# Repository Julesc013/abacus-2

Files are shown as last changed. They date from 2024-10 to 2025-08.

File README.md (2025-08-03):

# Project Codename: Abacus 2

**Carbon A1 Minicomputer** and **Carbon Z1 Microcomputer**

[Project Abacus 2 Technical Reference](https://github.com/Julesc013/abacus-2/blob/main/info/manual/Abacus%202%20Technical%20Reference.pdf) (PDF)

## Specifications

- _CPU:_ **Abacus 2** or **Zilog Z80** (8-bit CISC)
- _FPU:_ **AMD Am9511** (Pre-IEEE 754)
- _Clock:_ Up to **16 MHz** (Crystal FM)
- _RAM:_ Up to **640 KB** (SRAM)
- _ROM:_ Up to **128 KB** (PROM)
- _I/O:_ Up to **256 KB** (Memory Mapped)
- _TDD:_ **Compact Cassette** (KCS 240KB/hr)
- _FDD:_ **Floppy Disk** (5.25" DSDD 360KB, 3.5" DSHD 1.44MB)
- _Comms:_ **Serial** (RS-232), **Parallel** (DB-25)
- _Video:_ **Yamaha V9958** or **TMS9918**
- _Audio:_ **Yamaha OPNB** or **AY-3-8910**

## Design Showcase

### System Architecture

16-bit CISC (Von Neumann)

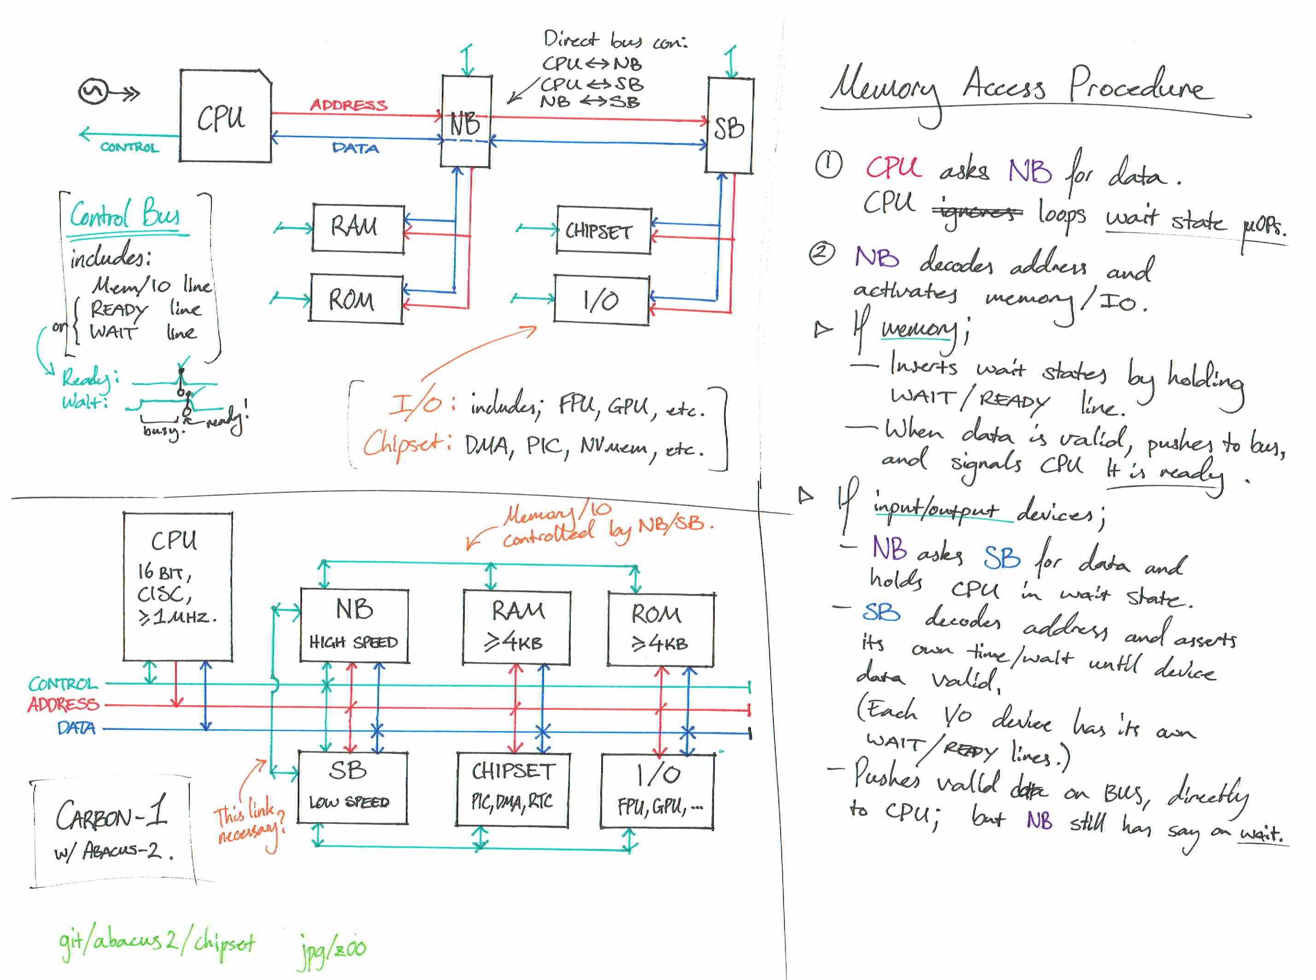
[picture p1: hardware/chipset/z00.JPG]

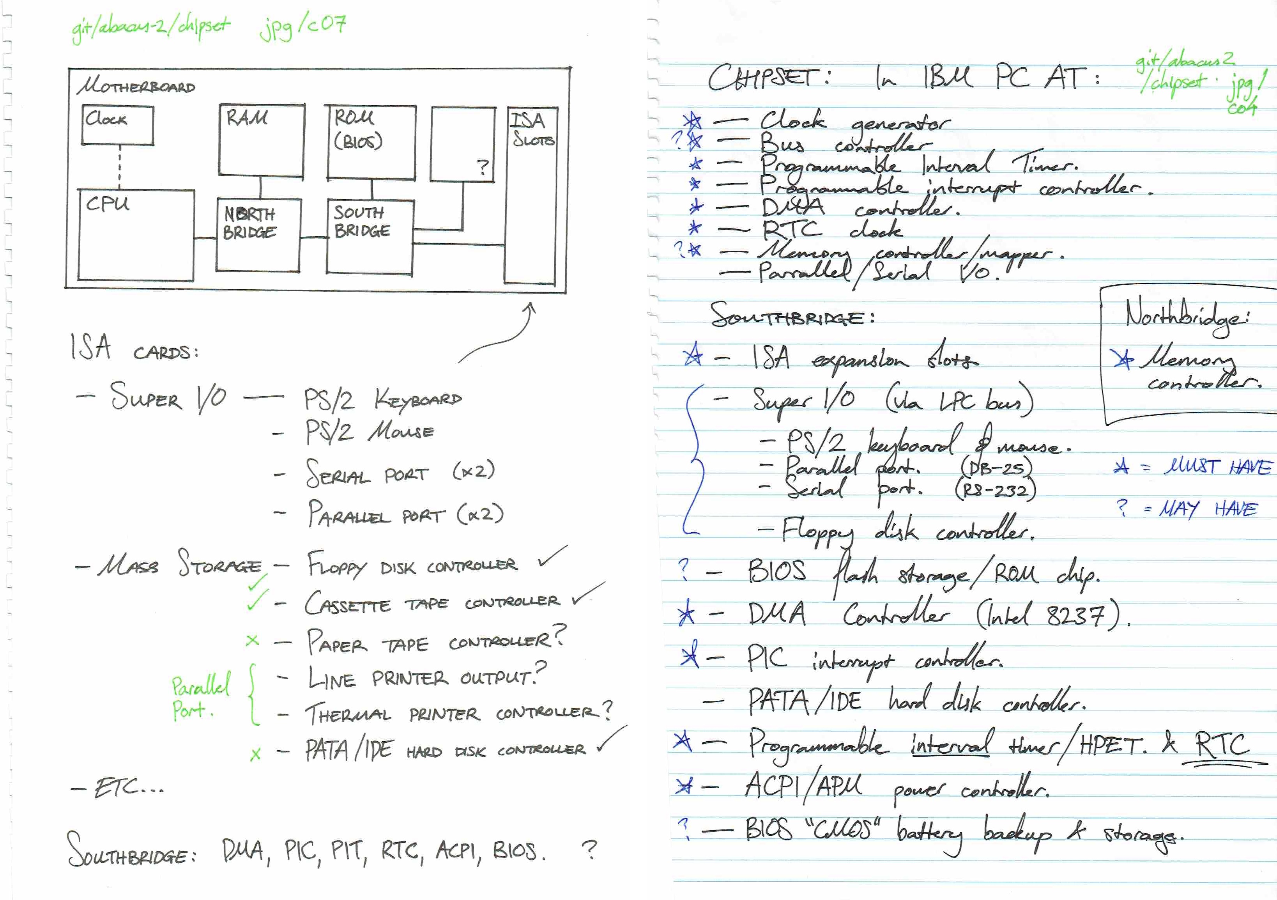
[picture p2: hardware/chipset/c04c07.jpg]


### Memory and I/O

Up to 640KB SRAM (8-bit bytes)

Up to 128KB PROM (8-bit bytes)

Up to 256KB memory mapped I/O.

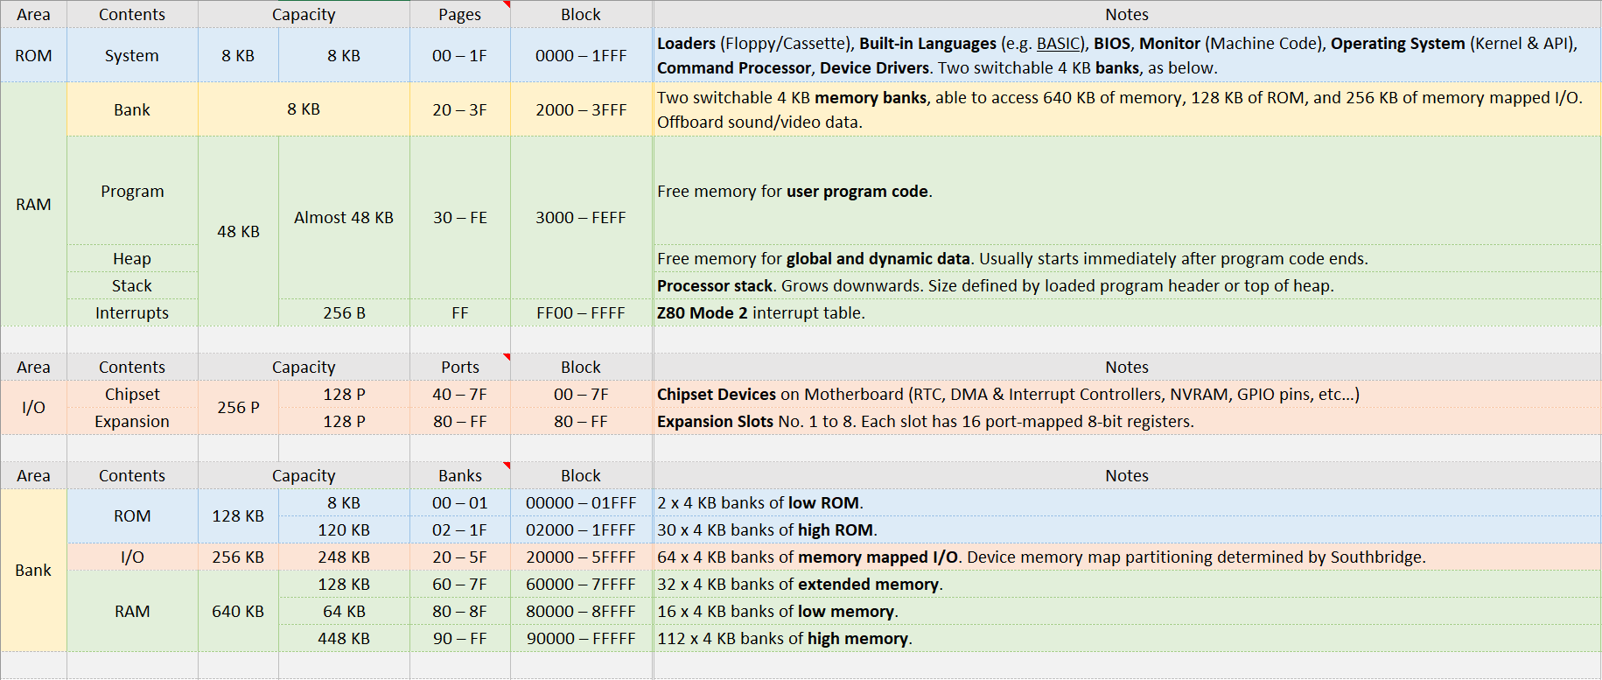
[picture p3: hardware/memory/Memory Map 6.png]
Memory map version 6

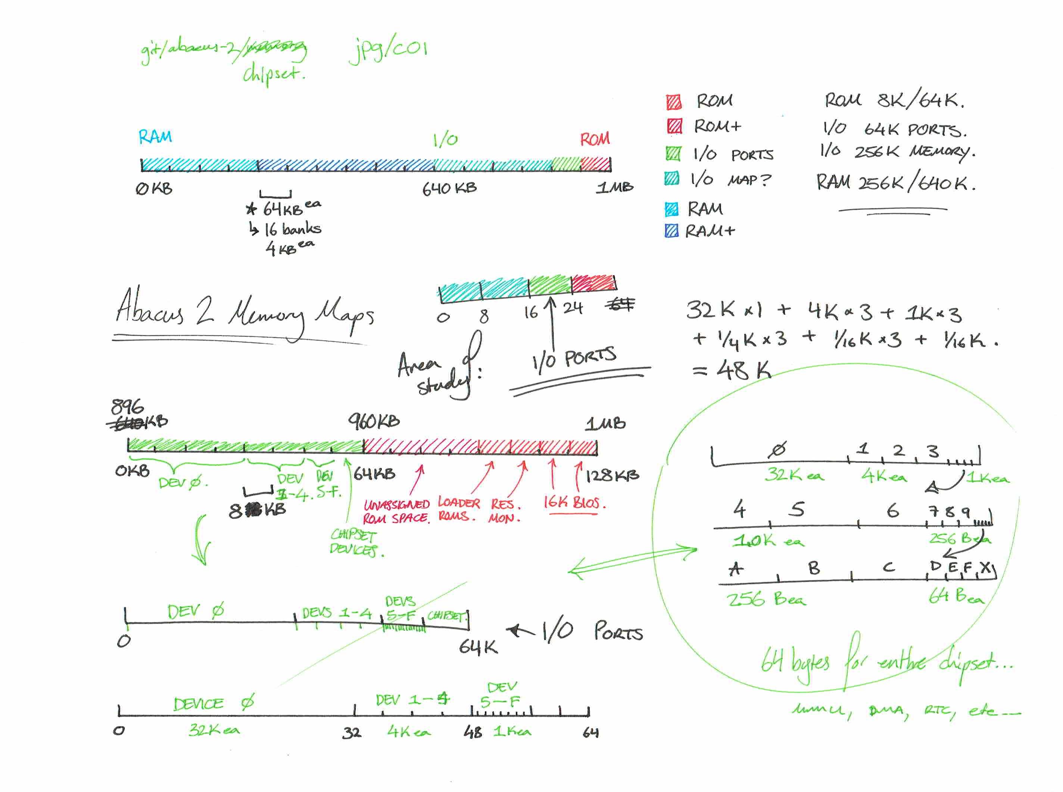
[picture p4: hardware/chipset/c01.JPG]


### Instruction Set

Abacus ISA (44 instructions) or Z80 ISA.

Integrated FPU (AMD AM9511)

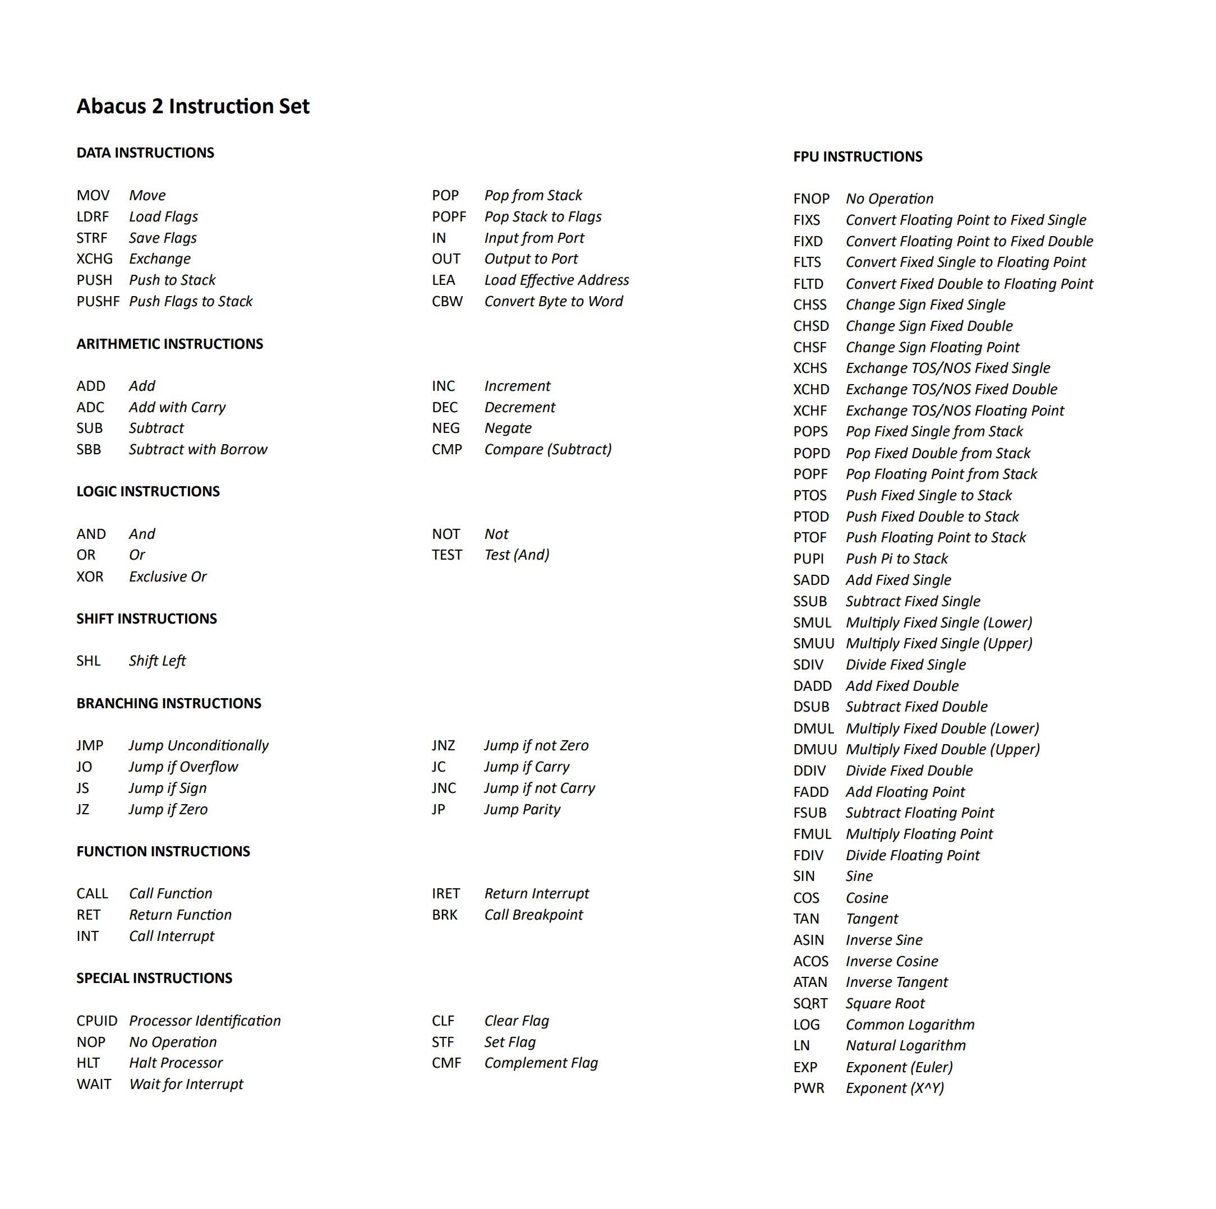
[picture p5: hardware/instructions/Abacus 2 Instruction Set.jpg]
Abacus 2 Instruction Set

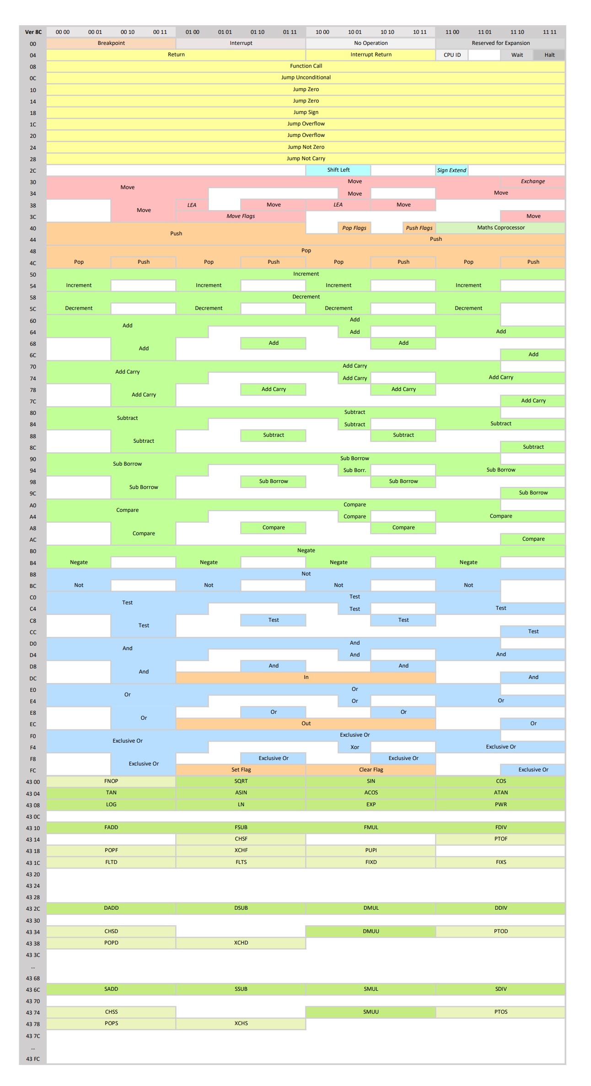
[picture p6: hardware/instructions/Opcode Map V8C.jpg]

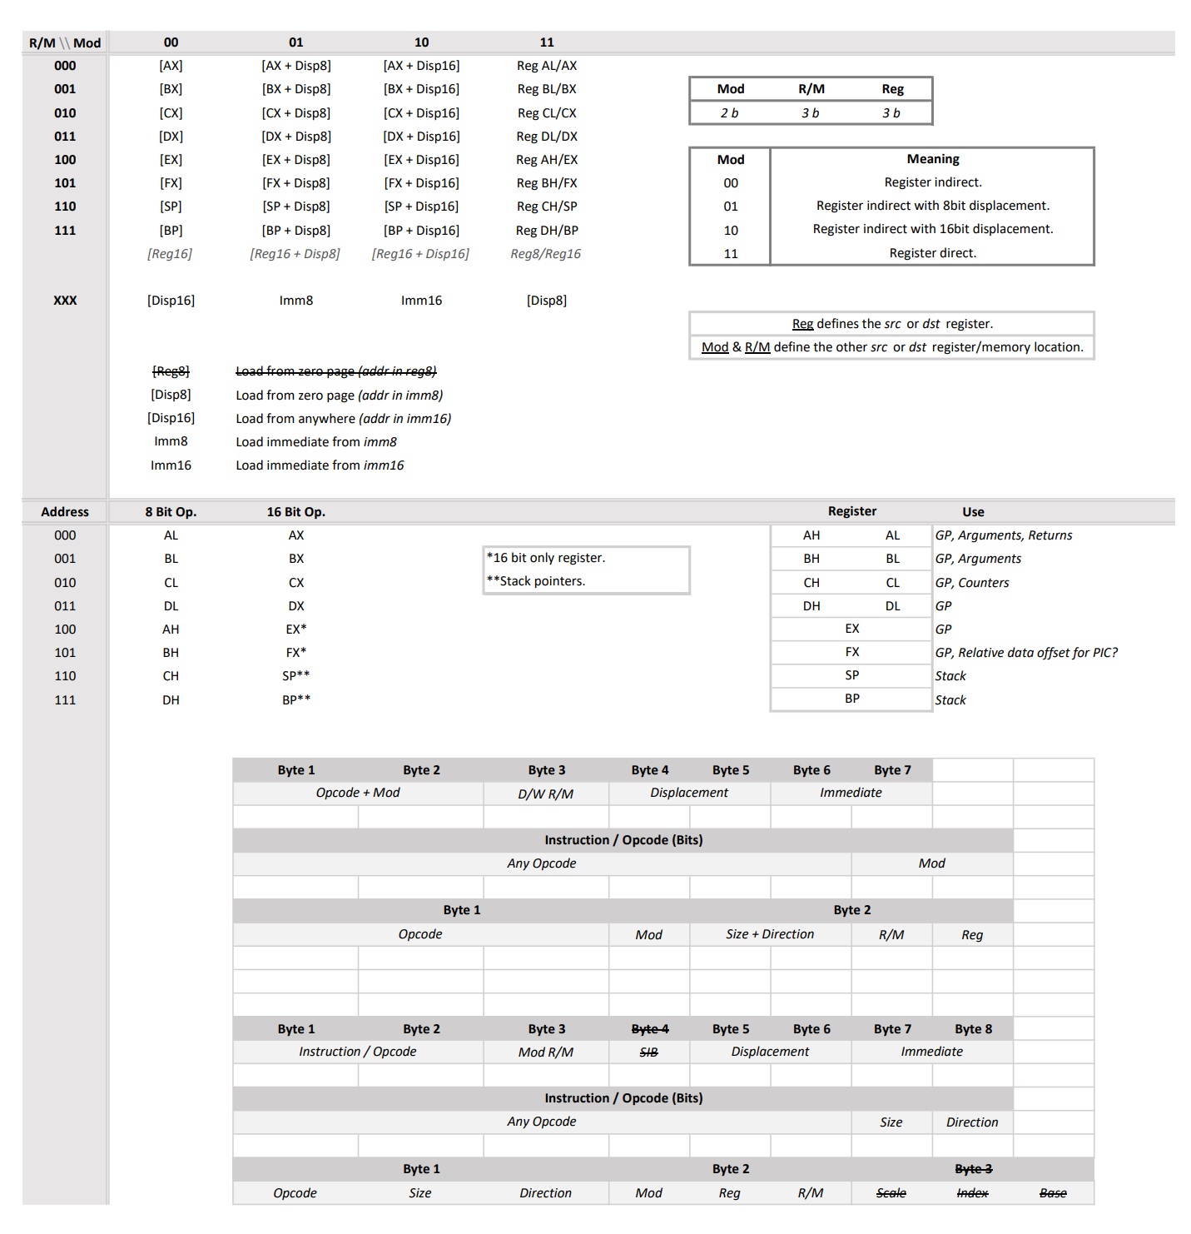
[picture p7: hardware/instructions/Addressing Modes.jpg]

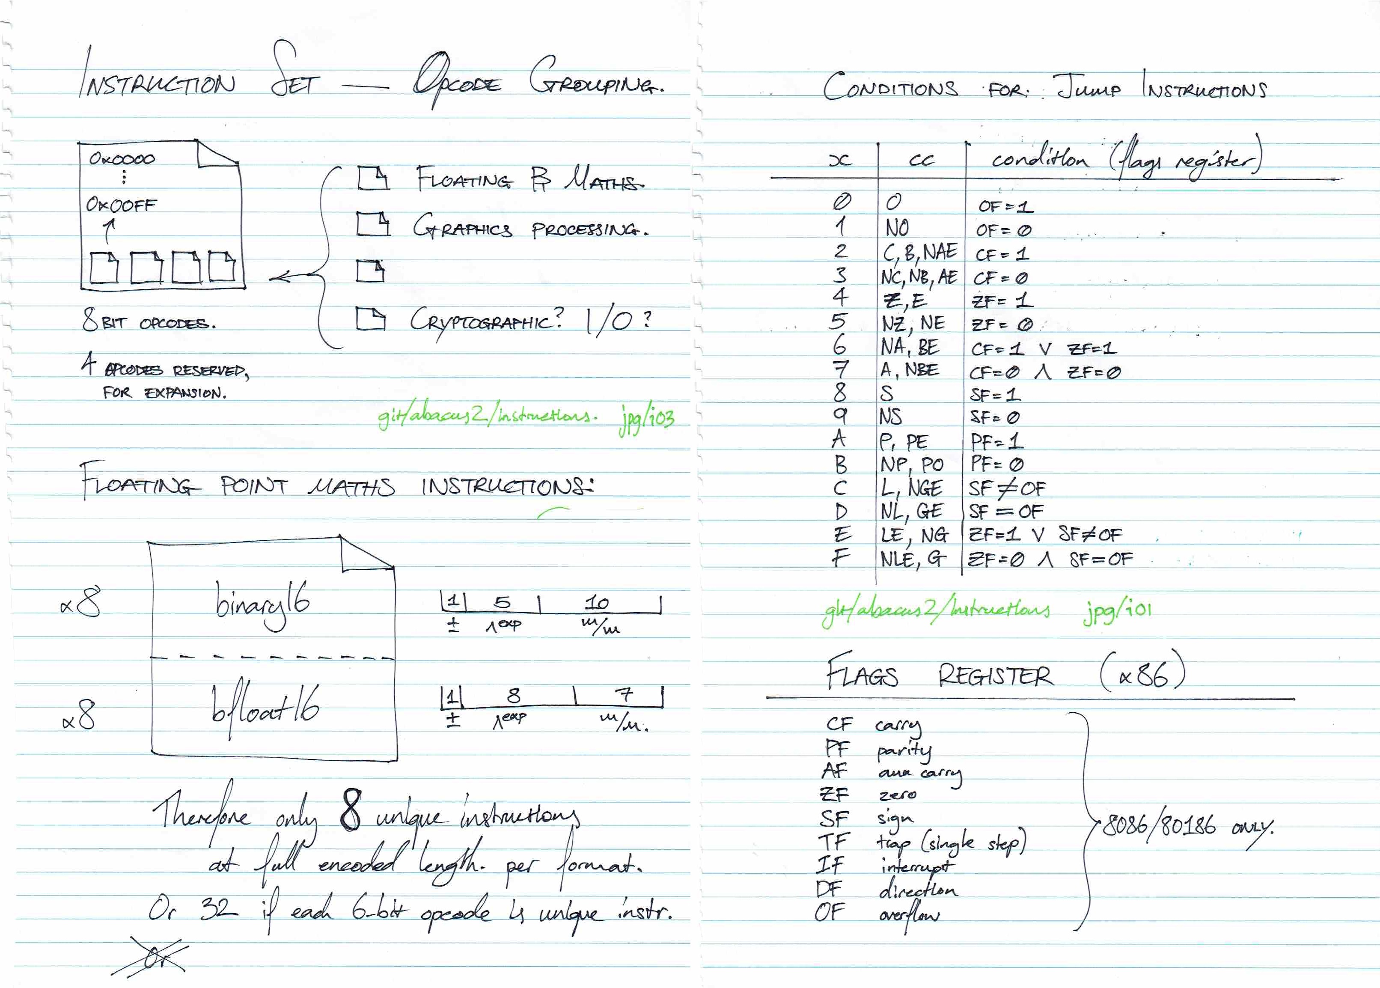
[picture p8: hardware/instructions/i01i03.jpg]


### Interrupt Handling

16 hardware int's, 110 software int's, 1 non-maskable int, 1 reset int; or Z80 Mode 2 interrupt scheme.

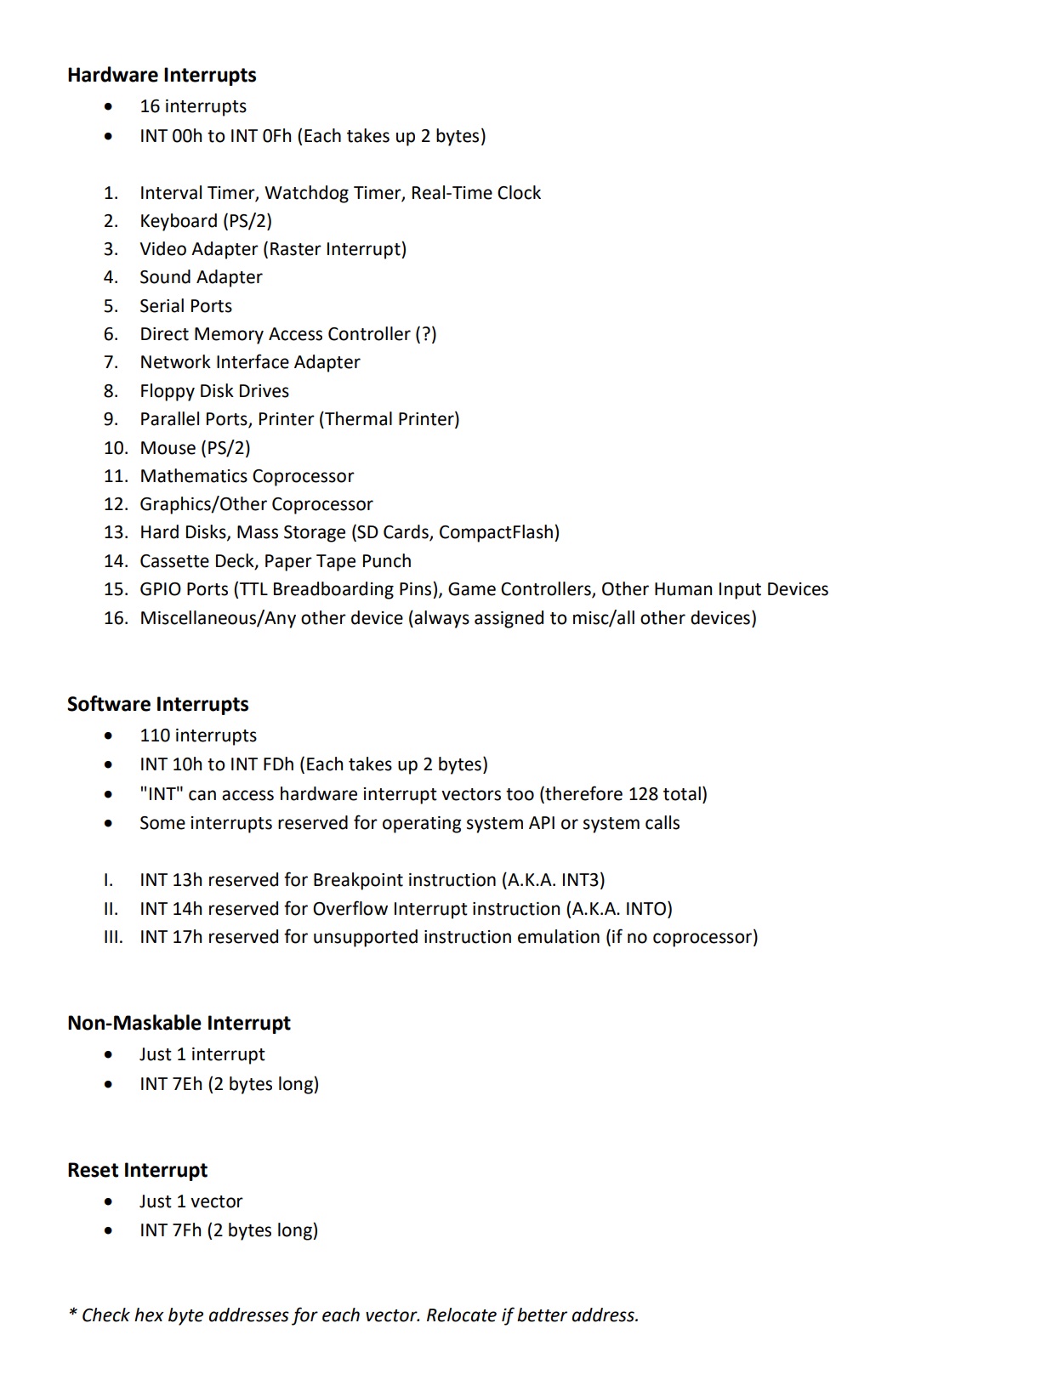
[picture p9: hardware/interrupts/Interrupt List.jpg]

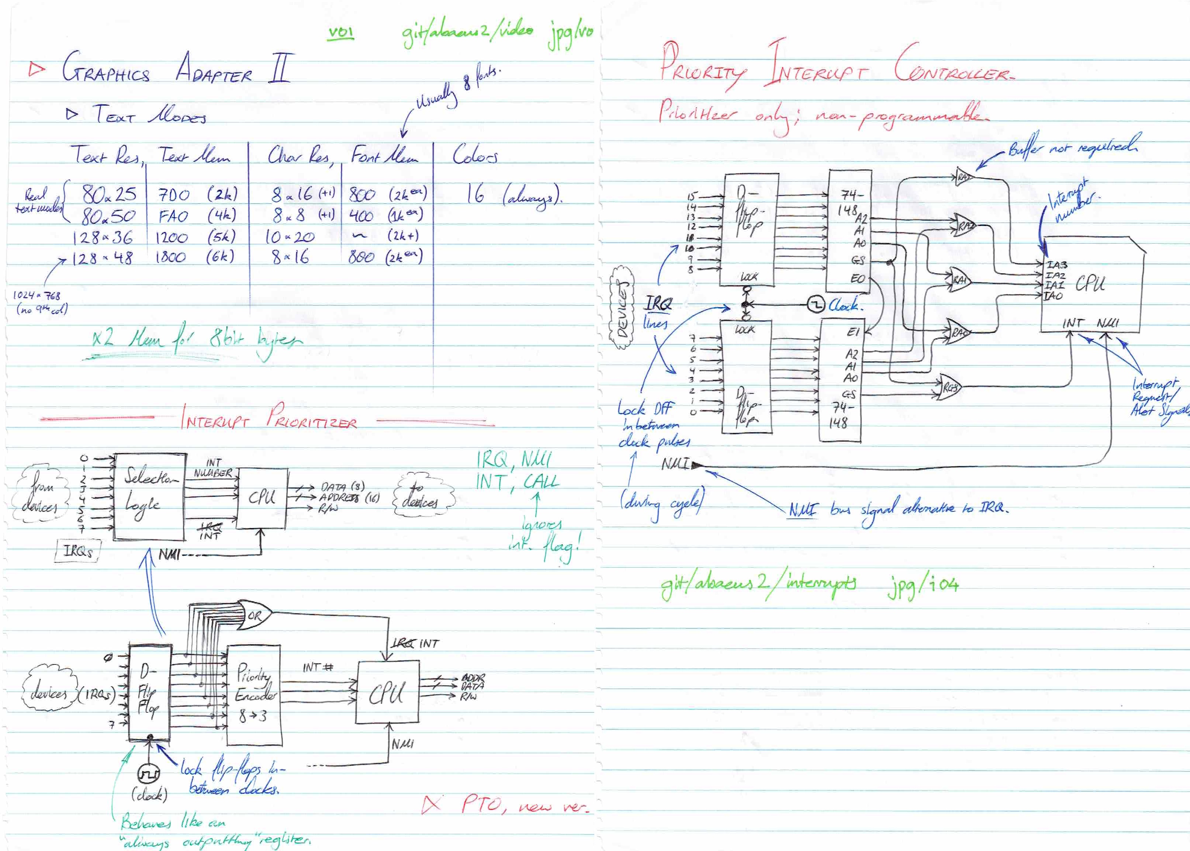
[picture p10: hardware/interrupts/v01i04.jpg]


### Video Output

VESA compatible (maybe)

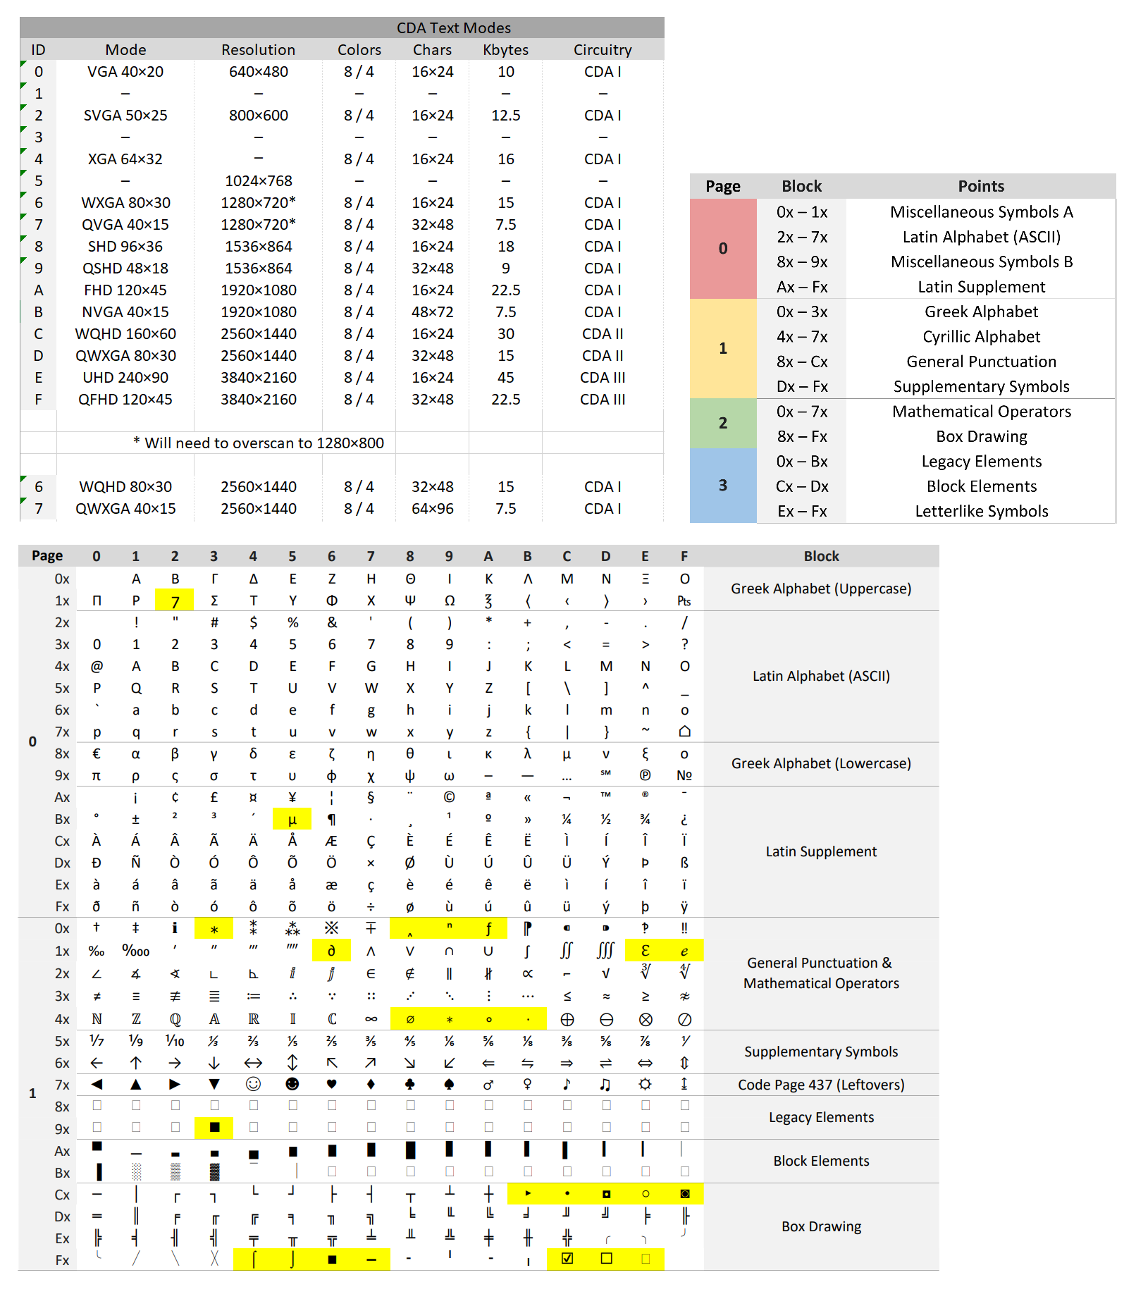
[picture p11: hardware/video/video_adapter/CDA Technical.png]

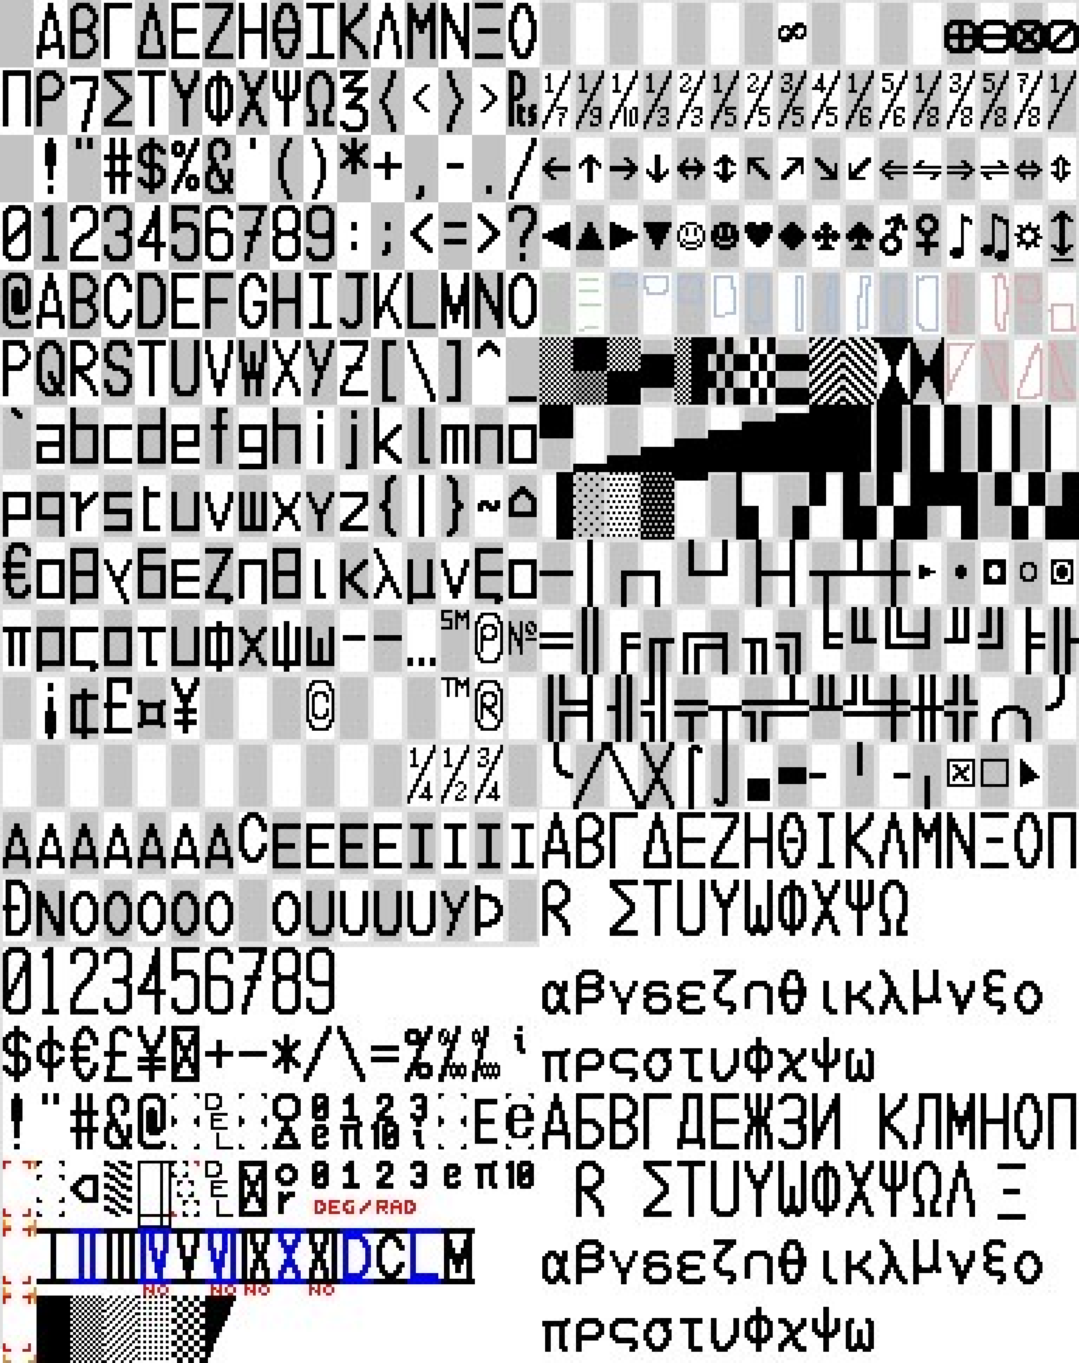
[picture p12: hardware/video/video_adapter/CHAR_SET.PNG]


### System Firmware

Resident monitor, loaders, system routines, etc.

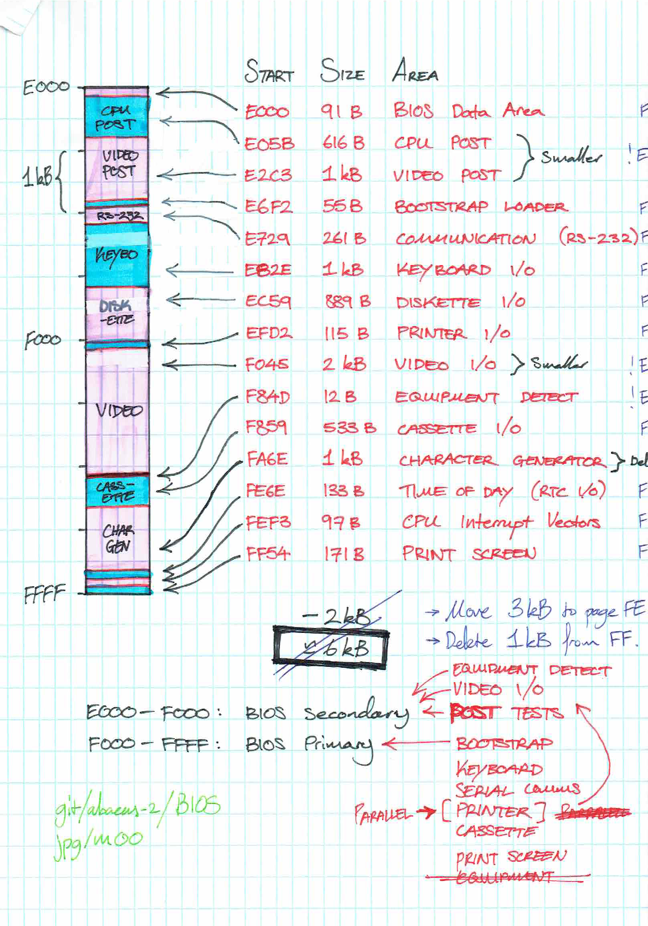
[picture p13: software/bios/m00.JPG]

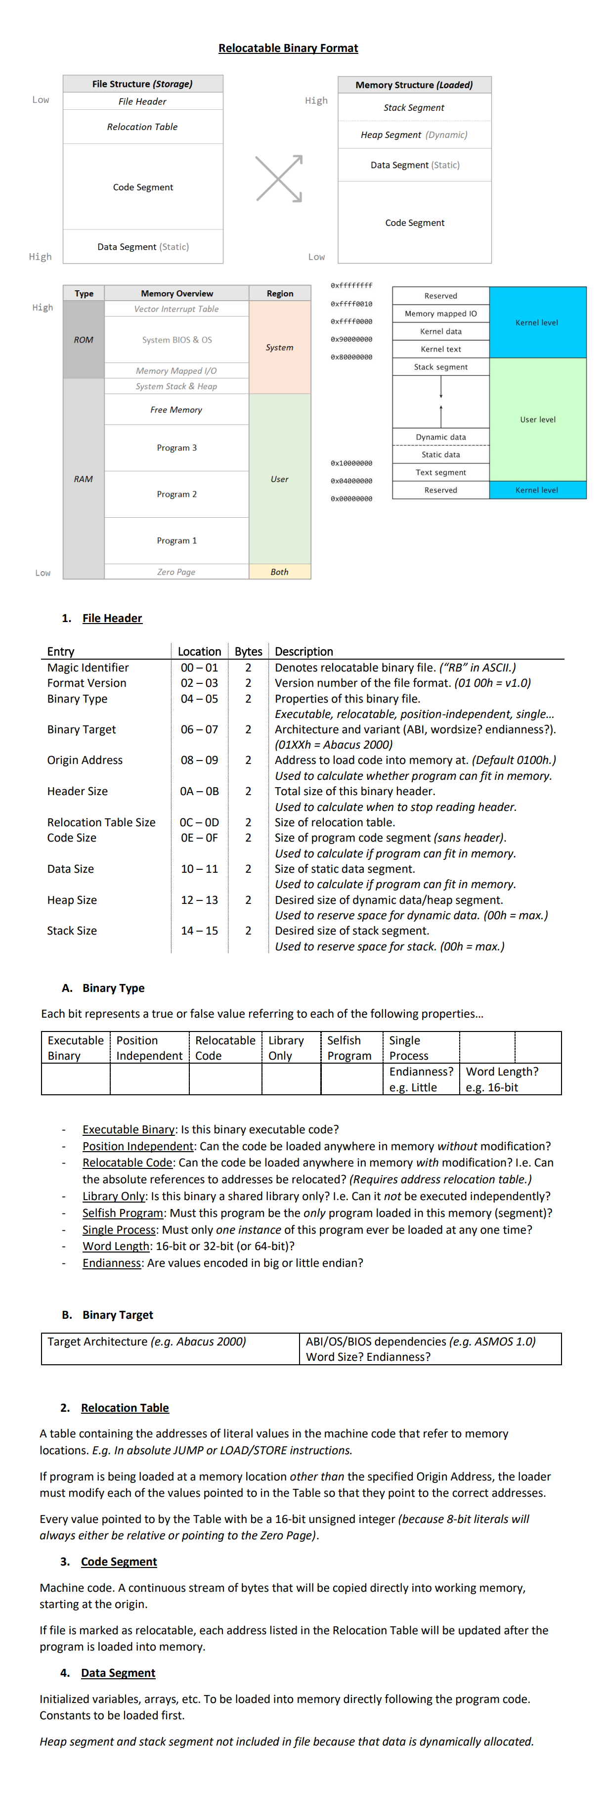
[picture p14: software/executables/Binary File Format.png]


## Physical Case

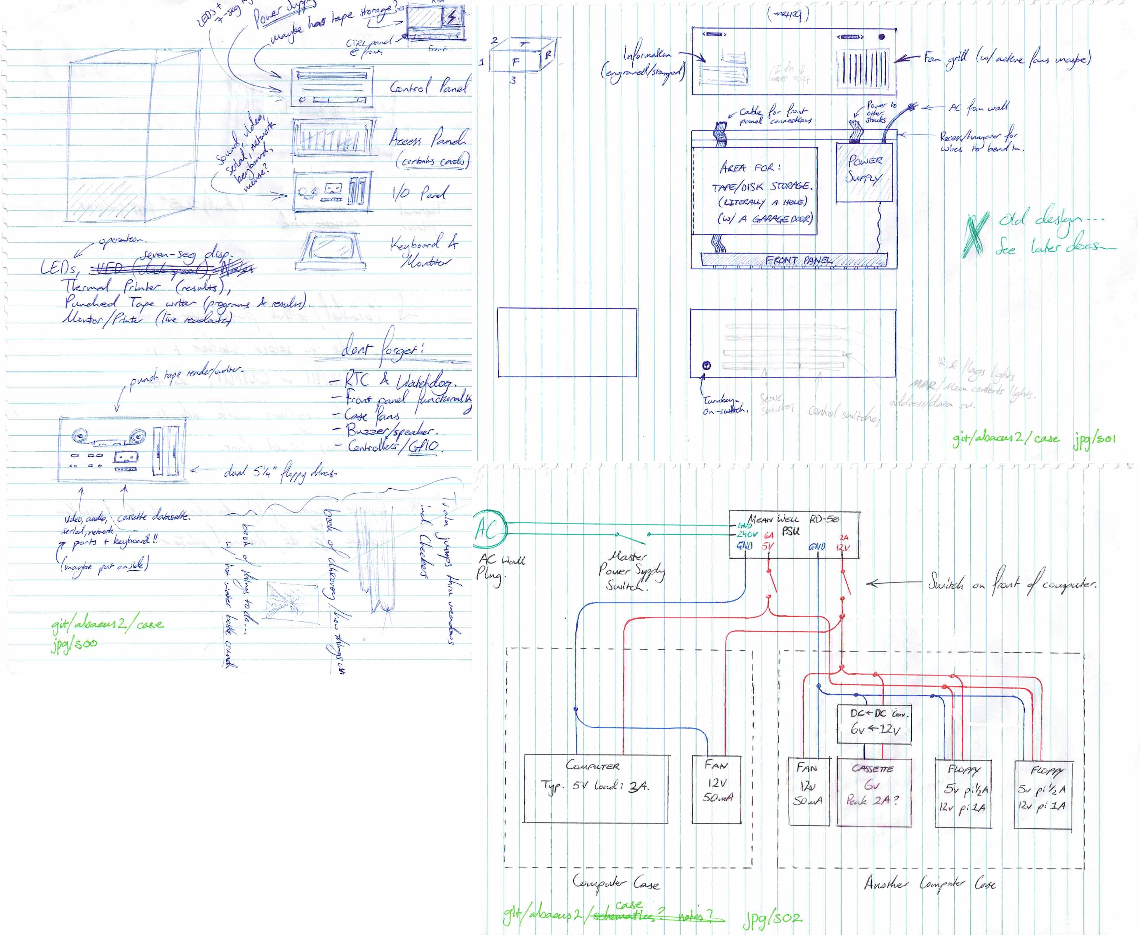
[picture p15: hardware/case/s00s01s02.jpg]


## User Manual

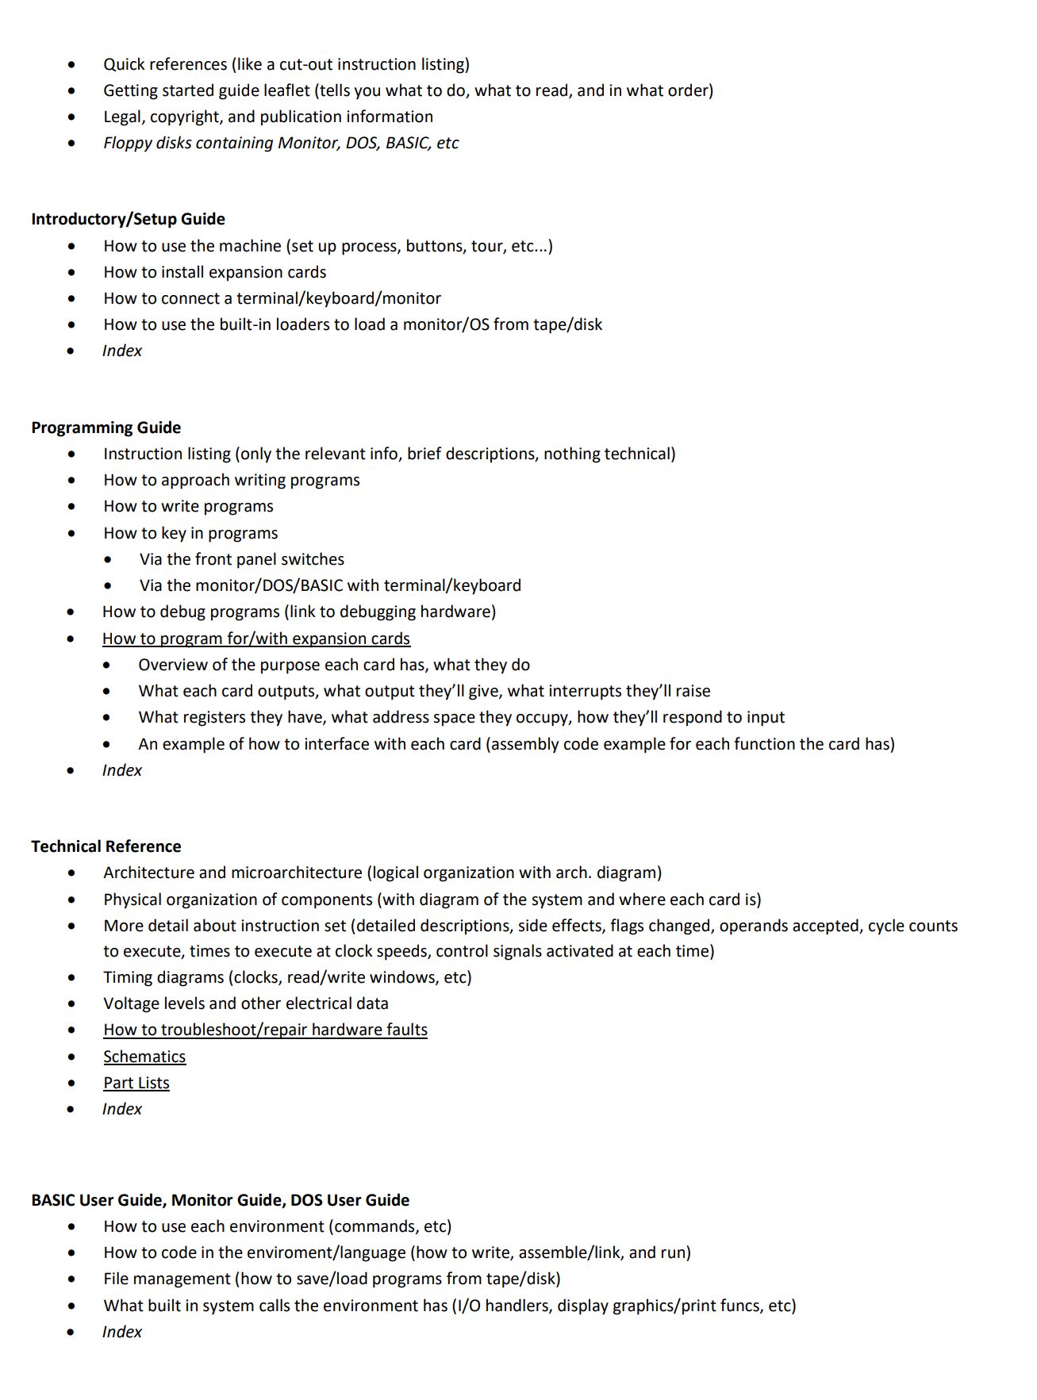
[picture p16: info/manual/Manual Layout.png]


[Abacus 2 Technical Reference](https://github.com/Julesc013/abacus-2/blob/main/info/manual/Abacus%202%20Technical%20Reference.pdf) (PDF)

## Directory Structure
```
├── archive             Archived and old versions of files.
├── hardware            Hardware design and circuitry.
│   ├── case                Physical design of machine.
│   ├── cassette            Cassette tape data storage.
│   ├── chipset             Northbridge, southbridge, I/O, wait states, etc.
│   ├── floppy              Floppy diskette data storage.
│   ├── instructions        Instruction set architecture.
│   ├── interrupts          Interrupt tables and circuits.
│   ├── memory              Memory maps, wait states, DMA, etc.
│   ├── printer             Parallel ports and printer communication.
│   ├── serial              Serial ports and teletype communication.
│   ├── todo                Todo lists and general notes.
│   └── video               Video text and graphics output.
├── info                General project information and metadata.
│   ├── datasheets          Relevant datasheets.
│   ├── manual              User and technical manuals for the system.
│   └── parts               Parts lists and records.
├── schematics          Schematics and technical drawings.
├── simulation          Virtual simulation of processor.
│   ├── digital             Implementation in Digital.
│   └── logisim             Implementation in Logisim Evolution.   
└── software            Software, firmware, drivers, operating systems, etc.
    ├── assembler           Assembler and linker.
    ├── basic               Implementation of Microsoft 8K BASIC.
    ├── bios                Disk loaders, bootstrappers, system calls, etc.
    ├── compiler            Compiler for K&R C.
    └── executables         Executable file formats and disk formats.
```

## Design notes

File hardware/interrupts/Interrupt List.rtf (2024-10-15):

Hardware Interrupts
• 16 interrupts
• INT 00h to INT 0Fh (Each takes up 2 bytes)

1. Interval Timer, Watchdog Timer, Real-Time Clock
2. Keyboard (PS/2)
3. Video Adapter (Raster Interrupt)
4. Sound Adapter
5. Serial Ports
6. Direct Memory Access Controller (?)
7. Network Interface Adapter
8. Floppy Disk Drives
9. Parallel Ports, Printer (Thermal Printer)
10. Mouse (PS/2)
11. Mathematics Coprocessor
12. Graphics/Other Coprocessor
13. Hard Disks, Mass Storage (SD Cards, CompactFlash)
14. Cassette Deck, Paper Tape Punch
15. GPIO Ports (TTL Breadboarding Pins), Game Controllers, Other Human Input Devices
16. Miscellaneous/Any other device (always assigned to misc/all other devices)

Software Interrupts
• 110 interrupts
• INT 10h to INT FDh (Each takes up 2 bytes)
• "INT" can access hardware interrupt vectors too (therefore 128 total)
• Some interrupts reserved for operating system API or system calls

I. INT 13h reserved for Breakpoint instruction (A.K.A. INT3)
II. INT 14h reserved for Overflow Interrupt instruction (A.K.A. INTO)
III. INT 17h reserved for unsupported instruction emulation (if no coprocessor)

Non-Maskable Interrupt
• Just 1 interrupt
• INT 7Eh (2 bytes long)

Reset Interrupt
• Just 1 vector
• INT 7Fh (2 bytes long)

* Check hex byte addresses for each vector. Relocate if better address.

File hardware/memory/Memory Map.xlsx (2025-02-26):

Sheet: Version 6 Lite
Area | Contents | Capacity |  | Pages | Block | Addresses | Notes
ROM | System | 8 KB | 8 KB | 00 – 1F | 0000 – 1FFF |  | Loaders (Floppy/Cassette), Built-in Languages (e.g. BASIC), BIOS, Monitor (Machine Code), Operating System (Kernel & API), Command Processor, Device Drivers.
RAM | Program | 56 KB | Almost 56 KB | 20 – FE | 2000 – FEFF | 00XX XXXX XXXX XXXX 01XX XXXX XXXX XXXX 10XX XXXX XXXX XXXX | Free memory for user program code.
 | Heap |  |  |  |  |  | Free memory for global and dynamic data. Usually starts immediately after program code ends.
 | Stack |  |  |  |  |  | Processor stack. Grows downwards. Size defined by loaded program header or top of heap.
 | Interrupts |  | 256 B | FF | FF00 – FFFF | 1111 1111 000X XXXX | Z80 Mode 2 interrupt table.
Area | Contents | Capacity |  | Ports | Block | Addresses | Notes
I/O | Chipset | 256 P | 128 P | 40 – 7F | 00 – 7F |  | Chipset Devices on Motherboard (RTC, DMA & Interrupt Controllers, NVRAM, GPIO pins, etc…)
 | Expansion |  | 128 P | 80 – FF | 80 – FF |  | Expansion Slots No. 1 to 8. Each slot has 16 port-mapped 8-bit registers.
Area | Contents | Capacity |  | Banks | Block | Addresses | Notes
Bank | ROM | 128 KB | 8 KB | 00 – 01 | 00000 – 01FFF |  | 2 x 4 KB banks of low ROM.
 |  |  | ~~120 KB~~ | ~~02 – 1F~~ | ~~02000 – 1FFFF~~ |  | ~~30 x 4 KB banks of ~~high ROM~~~~.~~~~
 | ~~I/O~~ | ~~256 KB~~ | ~~248 KB~~ | ~~20 – 5F~~ | ~~20000 – 5FFFF~~ |  | ~~64 x 4 KB banks of ~~memory mapped I/O~~~~. Device memory map partitioning determined by Southbridge.~~~~
 | RAM | 640 KB | ~~128 KB~~ | ~~60 – 7F~~ | ~~60000 – 7FFFF~~ |  | ~~32 x 4 KB banks of ~~extended memory~~~~.~~~~
 |  |  | 64 KB | 80 – 8F | 80000 – 8FFFF |  | 16 x 4 KB banks of low memory.
 |  |  | ~~448 KB~~ | ~~90 – FF~~ | ~~90000 – FFFFF~~ |  | ~~112 x 4 KB banks of ~~high memory~~~~.~~~~

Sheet: Version 6
Area | Contents | Capacity |  | Pages | Block | Addresses | Notes
ROM | System | 8 KB | 8 KB | 00 – 1F | 0000 – 1FFF |  | Loaders (Floppy/Cassette), Built-in Languages (e.g. BASIC), BIOS, Monitor (Machine Code), Operating System (Kernel & API), Command Processor, Device Drivers. Two switchable 4 KB banks, as below.
RAM | Bank | 8 KB |  | 20 – 3F | 2000 – 3FFF |  | Two switchable 4 KB memory banks, able to access 640 KB of memory, 128 KB of ROM, and 256 KB of memory mapped I/O. Offboard sound/video data.
 | Program | 48 KB | Almost 48 KB | 30 – FE | 3000 – FEFF | 00XX XXXX XXXX XXXX 01XX XXXX XXXX XXXX 10XX XXXX XXXX XXXX | Free memory for user program code.
 | Heap |  |  |  |  |  | Free memory for global and dynamic data. Usually starts immediately after program code ends.
 | Stack |  |  |  |  |  | Processor stack. Grows downwards. Size defined by loaded program header or top of heap.
 | Interrupts |  | 256 B | FF | FF00 – FFFF | 1111 1111 000X XXXX | Z80 Mode 2 interrupt table.
Area | Contents | Capacity |  | Ports | Block | Addresses | Notes
I/O | Chipset | 256 P | 128 P | 40 – 7F | 00 – 7F |  | Chipset Devices on Motherboard (RTC, DMA & Interrupt Controllers, NVRAM, GPIO pins, etc…)
 | Expansion |  | 128 P | 80 – FF | 80 – FF |  | Expansion Slots No. 1 to 8. Each slot has 16 port-mapped 8-bit registers.
Area | Contents | Capacity |  | Banks | Block | Addresses | Notes
Bank | ROM | 128 KB | 8 KB | 00 – 01 | 00000 – 01FFF |  | 2 x 4 KB banks of low ROM.
 |  |  | 120 KB | 02 – 1F | 02000 – 1FFFF |  | 30 x 4 KB banks of high ROM.
 | I/O | 256 KB | 248 KB | 20 – 5F | 20000 – 5FFFF |  | 64 x 4 KB banks of memory mapped I/O. Device memory map partitioning determined by Southbridge.
 | RAM | 640 KB | 128 KB | 60 – 7F | 60000 – 7FFFF |  | 32 x 4 KB banks of extended memory.
 |  |  | 64 KB | 80 – 8F | 80000 – 8FFFF |  | 16 x 4 KB banks of low memory.
 |  |  | 448 KB | 90 – FF | 90000 – FFFFF |  | 112 x 4 KB banks of high memory.

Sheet: Version 5V Nano
Area | Contents | Capacity |  | Pages | Block | Addresses | Notes
RAM | Zero Page | 48 KB | 256 B | 00 | 0000 – 00FF | 0000 0000 XXXX XXXX | Used for variable and immediate data storage. Can be accessed by shortened instructions.
 | Program |  | Almost 48 KB | 01 – BF | 0100 – BFFF | 00XX XXXX XXXX XXXX 01XX XXXX XXXX XXXX 10XX XXXX XXXX XXXX | Free memory for user program code.
 | Heap |  |  |  |  |  | Free memory for global and dynamic data. Usually starts immediately after program code ends.
 | Stack |  |  |  |  |  | Processor stack. Grows downwards. Size defined by loaded program header or top of heap. Hardware overflow detection.
 | I/O | 8 KB |  | C0 – DF | 40 – 7F |  | 8 KB of memory mapped I/O. Device memory map partitioning determined by Southbridge. Or mapped to internal RAM or ROM.
ROM | System | 8 KB | Almost 8 KB | E0 – FE | E000 – FEFF |  | Loaders (Floppy/Cassette), Built-in Languages (e.g. BASIC), BIOS, Monitor (Machine Code), Operating System (Kernel & API), Command Processor, Device Drivers.
 | Interrupts |  | 256 B | FF | FF00 – FFFF | 1111 1111 000X XXXX | 16 IRQ Hardware Interrupts. 110 INT Software Interrupts. One Non-Maskable Interrupt vector. One Reset vector.
Area | Contents | Capacity |  | Ports | Block | Addresses | Notes
I/O | Non-Volatile | 256 B | 64 B | 00 – 3F | 00 – 3F |  | Non-volatile memory for storing BIOS settings. Backed up by battery.
 | Chipset |  | 64 B | 40 – 7F | 40 – 7F |  | Chipset Devices on Motherboard (RTC, DMA & Interrupt Controllers, GPIO pins, etc…)
 | Expansion |  | 128 B | 80 – FF | 80 – FF |  | Expansion Slots No. 1 to 8. Each slot has 32 port-mapped 8-bit registers.
Area | Contents | Capacity |  | Banks | Block | Addresses | Notes
Bank | ~~RAM~~ | ~~640 KB~~ | ~~64 KB~~ | ~~00 – 0F~~ | ~~00000 – 0FFFF~~ |  | ~~16 x 4 KB banks of ~~standard memory~~~~. Pages 00 to BF map here.~~~~
 |  |  | ~~576 KB~~ | ~~10 – 9F~~ | ~~10000 – 9FFFF~~ |  | ~~144 x 4 KB banks of ~~extended memory~~~~.~~~~
 | ~~ROM~~ | ~~128 KB~~ | ~~120 KB~~ | ~~A0 – BD~~ | ~~A0000 – BDFFF~~ |  | ~~30 x 4 KB banks of ~~extended ROM~~~~.~~~~
 |  |  | ~~8 KB~~ | ~~BE – BF~~ | ~~BE000 – BFFFF~~ |  | ~~2 x 4 KB banks of ~~standard ROM~~~~. Pages E0 to FF map here.~~~~
 | I/O | 256 KB | ~~248 KB~~ | ~~C0 – FB~~ | ~~C0000 – FBFFF~~ |  | ~~60 x 4 KB banks of ~~extended I/O~~~~. Device memory map partitioning determined by Southbridge.~~~~
 |  |  | 8 KB | FC – FD | FC000 – FDFFF |  | 2 x 4 KB banks of memory mapped I/O. Pages C0 to DF map here. Device memory map partitioning determined by Southbridge.
 |  |  | ~~8 KB~~ | ~~FE – FF~~ | ~~FE000 – FFFFF~~ |  | ~~2 x 4 KB banks of ~~extended I/O~~~~. Device memory map partitioning determined by Southbridge.~~~~

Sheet: Version 5V Lite
Area | Contents | Capacity |  | Pages | Block | Addresses | Notes
RAM | Zero Page | 48 KB | 256 B | 00 | 0000 – 00FF | 0000 0000 XXXX XXXX | Used for variable and immediate data storage. Can be accessed by shortened instructions.
 | Program |  | Almost 48 KB | 01 – BF | 0100 – BFFF | 00XX XXXX XXXX XXXX 01XX XXXX XXXX XXXX 10XX XXXX XXXX XXXX | Free memory for user program code.
 | Heap |  |  |  |  |  | Free memory for global and dynamic data. Usually starts immediately after program code ends.
 | Stack |  |  |  |  |  | Processor stack. Grows downwards. Size defined by loaded program header or top of heap. Hardware overflow detection.
 | Bank | 8 KB |  | C0 – DF | C000 – DFFF |  | Two switchable 4 KB memory banks, able to access 64 KB of memory, 8 KB of ROM, and 8 KB of memory mapped I/O. Offboard sound/video data. May be mapped to internal RAM or ROM.
ROM | System | 8 KB | Almost 8 KB | E0 – FE | E000 – FEFF |  | Loaders (Floppy/Cassette), Built-in Languages (e.g. BASIC), BIOS, Monitor (Machine Code), Operating System (Kernel & API), Command Processor, Device Drivers.
 | Interrupts |  | 256 B | FF | FF00 – FFFF | 1111 1111 000X XXXX | 16 IRQ Hardware Interrupts. 110 INT Software Interrupts. One Non-Maskable Interrupt vector. One Reset vector.
Area | Contents | Capacity |  | Ports | Block | Addresses | Notes
I/O | Non-Volatile | 256 B | 64 B | 00 – 3F | 00 – 3F |  | Non-volatile memory for storing BIOS settings. Backed up by battery.
 | Chipset |  | 64 B | 40 – 7F | 40 – 7F |  | Chipset Devices on Motherboard (RTC, DMA & Interrupt Controllers, GPIO pins, etc…)
 | Expansion |  | 128 B | 80 – FF | 80 – FF |  | Expansion Slots No. 1 to 8. Each slot has 32 port-mapped 8-bit registers.
Area | Contents | Capacity |  | Banks | Block | Addresses | Notes
Bank | RAM | 640 KB | 64 KB | 00 – 0F | 00000 – 0FFFF |  | 16 x 4 KB banks of standard memory. Pages 00 to BF map here.
 |  |  | ~~576 KB~~ | ~~10 – 9F~~ | ~~10000 – 9FFFF~~ |  | ~~144 x 4 KB banks of ~~extended memory~~~~.~~~~
 | ROM | 128 KB | ~~120 KB~~ | ~~A0 – BD~~ | ~~A0000 – BDFFF~~ |  | ~~30 x 4 KB banks of ~~extended ROM~~~~.~~~~
 |  |  | 8 KB | BE – BF | BE000 – BFFFF |  | 2 x 4 KB banks of standard ROM. Pages E0 to FF map here.
 | I/O | 256 KB | ~~248 KB~~ | ~~C0 – FB~~ | ~~C0000 – FBFFF~~ |  | ~~60 x 4 KB banks of ~~extended I/O~~~~. Device memory map partitioning determined by Southbridge.~~~~
 |  |  | 8 KB | FC – FD | FC000 – FDFFF |  | 2 x 4 KB banks of memory mapped I/O. Device memory map partitioning determined by Southbridge.
 |  |  | ~~8 KB~~ | ~~FE – FF~~ | ~~FE000 – FFFFF~~ |  | ~~2 x 4 KB banks of ~~extended I/O~~~~. Device memory map partitioning determined by Southbridge.~~~~

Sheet: Version 5V
Area | Contents | Capacity |  | Pages | Block | Addresses | Notes
RAM | Zero Page | 48 KB | 256 B | 00 | 0000 – 00FF | 0000 0000 XXXX XXXX | Used for variable and immediate data storage. Can be accessed by shortened instructions.
 | Program |  | Almost 48 KB | 01 – BF | 0100 – BFFF | 00XX XXXX XXXX XXXX 01XX XXXX XXXX XXXX 10XX XXXX XXXX XXXX | Free memory for user program code.
 | Heap |  |  |  |  |  | Free memory for global and dynamic data. Usually starts immediately after program code ends.
 | Stack |  |  |  |  |  | Processor stack. Grows downwards. Size defined by loaded program header or top of heap. Hardware overflow detection.
 | Bank | 8 KB |  | C0 – DF | C000 – DFFF |  | Two switchable 4 KB memory banks, able to access 640 KB of memory, 128 KB of ROM, and 256 KB of memory mapped I/O. Offboard sound/video data.
ROM | System | 8 KB | Almost 8 KB | E0 – FE | E000 – FEFF |  | Loaders (Floppy/Cassette), Built-in Languages (e.g. BASIC), BIOS, Monitor (Machine Code), Operating System (Kernel & API), Command Processor, Device Drivers.
 | Interrupts |  | 256 B | FF | FF00 – FFFF | 1111 1111 000X XXXX | 16 IRQ Hardware Interrupts. 110 INT Software Interrupts. One Non-Maskable Interrupt vector. One Reset vector.
Area | Contents | Capacity |  | Ports | Block | Addresses | Notes
I/O | Non-Volatile | 256 B | 64 B | 00 – 3F | 00 – 3F |  | Non-volatile memory for storing BIOS settings. Backed up by battery.
 | Chipset |  | 64 B | 40 – 7F | 40 – 7F |  | Chipset Devices on Motherboard (RTC, DMA & Interrupt Controllers, GPIO pins, etc…)
 | Expansion |  | 128 B | 80 – FF | 80 – FF |  | Expansion Slots No. 1 to 8. Each slot has 32 port-mapped 8-bit registers.
Area | Contents | Capacity |  | Banks | Block | Addresses | Notes
Bank | RAM | 640 KB | 64 KB | 00 – 0F | 00000 – 0FFFF |  | 16 x 4 KB banks of standard memory. Pages 00 to BF map here.
 |  |  | 576 KB | 10 – 9F | 10000 – 9FFFF |  | 144 x 4 KB banks of extended memory.
 | ROM | 128 KB | 120 KB | A0 – BD | A0000 – BDFFF |  | 30 x 4 KB banks of extended ROM.
 |  |  | 8 KB | BE – BF | BE000 – BFFFF |  | 2 x 4 KB banks of standard ROM. Pages E0 to FF map here.
 | I/O | 256 KB | 248 KB | C0 – FB | C0000 – FBFFF |  | 60 x 4 KB banks of extended I/O. Device memory map partitioning determined by Southbridge.
 |  |  | 8 KB | FC – FD | FC000 – FDFFF |  | 2 x 4 KB banks of memory mapped I/O. Device memory map partitioning determined by Southbridge.
 |  |  | 8 KB | FE – FF | FE000 – FFFFF |  | 2 x 4 KB banks of extended I/O. Device memory map partitioning determined by Southbridge.
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

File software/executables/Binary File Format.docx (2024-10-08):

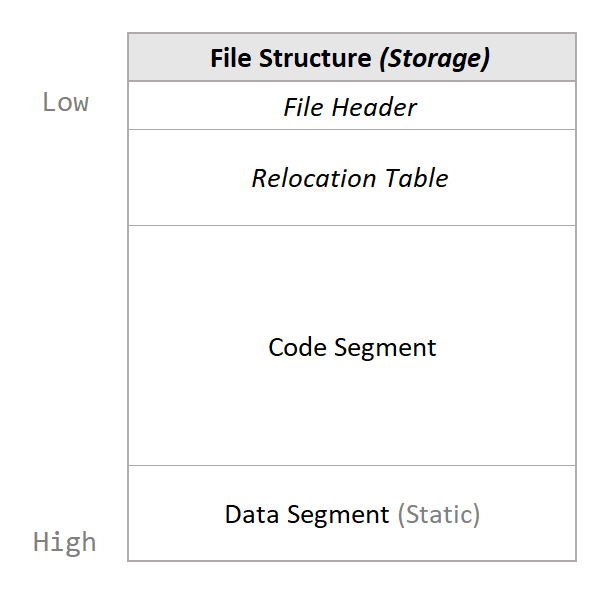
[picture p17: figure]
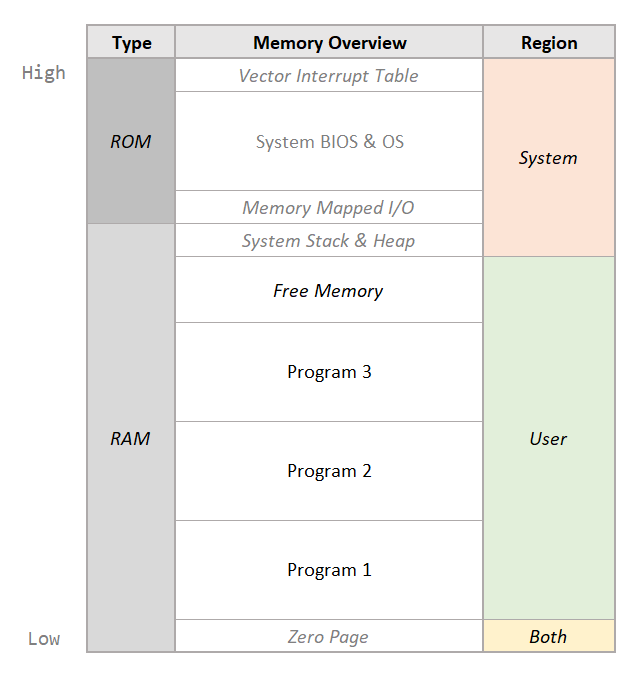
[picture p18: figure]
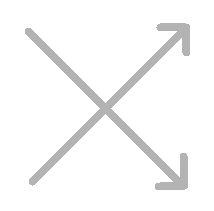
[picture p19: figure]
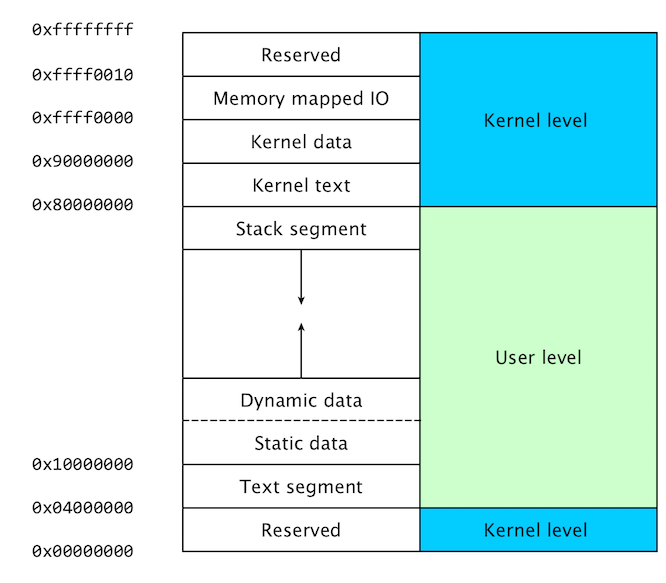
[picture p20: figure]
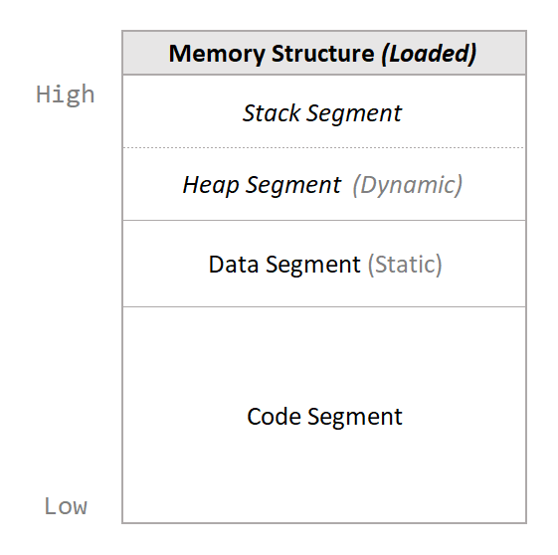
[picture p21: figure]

Relocatable Binary Format

1. File Header

Entry | Location | Bytes | Description
Magic Identifier | 00 – 01 | 2 | Denotes relocatable binary file. (“RB” in ASCII.)
Format Version | 02 – 03 | 2 | Version number of the file format. (01 00h = v1.0)
Binary Type | 04 – 05 | 2 | Properties of this binary file. Executable, relocatable, position-independent, single…
Binary Target | 06 – 07 | 2 | Architecture and variant (ABI, wordsize? endianness?). (01XXh = Abacus 2000)
Origin Address | 08 – 09 | 2 | Address to load code into memory at. (Default 0100h.) Used to calculate whether program can fit in memory.
Header Size | 0A – 0B | 2 | Total size of this binary header. Used to calculate when to stop reading header.
Relocation Table Size | 0C – 0D | 2 | Size of relocation table.
Code Size | 0E – 0F | 2 | Size of program code segment (sans header). Used to calculate if program can fit in memory.
Data Size | 10 – 11 | 2 | Size of static data segment. Used to calculate if program can fit in memory.
Heap Size | 12 – 13 | 2 | Desired size of dynamic data/heap segment. Used to reserve space for dynamic data. (00h = max.)
Stack Size | 14 – 15 | 2 | Desired size of stack segment. Used to reserve space for stack. (00h = max.)

A. Binary Type

Each bit represents a true or false value referring to each of the following properties…

Executable Binary | Position Independent | Relocatable Code | Library Only | Selfish Program | Single Process
| | | | | Endianness? e.g. Little | Word Length? e.g. 16-bit

- Executable Binary: Is this binary executable code?
- Position Independent: Can the code be loaded anywhere in memory without modification?
- Relocatable Code: Can the code be loaded anywhere in memory with modification? I.e. Can the absolute references to addresses be relocated? (Requires address relocation table.)
- Library Only: Is this binary a shared library only? I.e. Can it not be executed independently?
- Selfish Program: Must this program be the only program loaded in this memory (segment)?
- Single Process: Must only one instance of this program ever be loaded at any one time?
- Word Length: 16-bit or 32-bit (or 64-bit)?
- Endianness: Are values encoded in big or little endian?
B. Binary Target

Target Architecture (e.g. Abacus 2000) | ABI/OS/BIOS dependencies (e.g. ASMOS 1.0) Word Size? Endianness?

2. Relocation Table

A table containing the addresses of literal values in the machine code that refer to memory locations. E.g. In absolute JUMP or LOAD/STORE instructions.

If program is being loaded at a memory location other than the specified Origin Address, the loader must modify each of the values pointed to in the Table so that they point to the correct addresses.

Every value pointed to by the Table with be a 16-bit unsigned integer (because 8-bit literals will always either be relative or pointing to the Zero Page).

3. Code Segment

Machine code. A continuous stream of bytes that will be copied directly into working memory, starting at the origin.

If file is marked as relocatable, each address listed in the Relocation Table will be updated after the program is loaded into memory.

4. Data Segment

Initialized variables, arrays, etc. To be loaded into memory directly following the program code. Constants to be loaded first.

Heap segment and stack segment not included in file because that data is dynamically allocated.

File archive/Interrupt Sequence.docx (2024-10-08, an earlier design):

1. Any Interrupt control line goes high; set DF flag high.
2. Finish current cycle. (When DF and IF are high the interrupt sequence will be executed on the next cycle.)
3. Push FR to return stack.
4. Push PC to return stack.
5. Send Acknowledgement signal to bus device that sent interrupt request. (There is an interrupt and an acknowledgement control line for each device.)
6. Receive interrupt code from device (via GPI/O).
7. Jump to interrupt vector that corresponds to code. (7DF00h to 7DFFFh)
8. Execute this code as per usual.
9. When finished with execution, exit (somehow)… Set DF low.
10. Pop PC from stack.
11. Pop FR from stack.
12. Resume normal execution.
1. Interrupt control line goes high; latch DF high.
2. Save 3bit interrupt code in temporary register; finish executing current cycle.
3. If IF and DF are both high begin sequence, else set DF low and finish.
4. Push PC to stack.
5. Jump to corresponding interrupt vector (0b 111 1111 1111 xxx0 0000).
6. Execute code; when DF goes low stop (flags “DF low” instruction).
7. Pop PC from stack.
8. Resume normal execution.

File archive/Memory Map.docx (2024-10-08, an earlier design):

Memory Block | Contents | Memory Area | Block Capacity | Area Capacity | Block Start
00 0000 – F0 0000 | RAM (Free) | Conventional | MB | MB | 0000 0000 0000 0000 0000 0000
EC 0000 – F0 0000 | Video (VGA) | | 256 KB
F0 0000 – 100 0000 | ROM (OS) | Extended | 1 MB

Memory Block | Contents | Memory Area | Block Capacity | Area Capacity | Block Start
0 0000 – 5 0000 | RAM (Free) | Conventional | 320 | 320 | 000 0000 0000 0000 0000
5 0000 – 7 0000 | ROM (OS) | Extended | 128 | 183¹/2 | 101 0000 0000 0000 0000
7 0000 – 7 C000 | Video | | 48 | | 111 0000 0000 0000 0000
7 C000 – 7 D000 | Sound | | 4 | | 111 1100 0000 0000 0000
7 D000 – 7 DD70 | General I/O | | 3⁵⁴/64 (3952) | | 111 1101 0000 0000 0000
7 DD70 – 7 DD80 | Joystick I/O (x2) | | ¹/64 (16) | | 111 1101 1101 0111 0000
7 DD80 – 7 DDC0 | Control I/O (x8) | | ¹/16 (64) | | 111 1101 1101 1000 0000
7 DDC0 – 7 DE00 | Expansion I/O (x8) | | ¹/16 (64) | | 111 1101 1101 1100 0000
7 DE00 – 7 DF00 | Hard Interrupts | Restricted | ¹/4 (256) | 8¹/2 | 111 1101 1110 0000 0000
7 DF00 – 7 E000 | Soft Interrupts | | ¹/4 (256) | | 111 1101 1111 0000 0000
7 E000 – 7 F000 | Stack (Data) | | 4 | | 111 1110 0000 0000 0000
7 F000 – 8 0000 | Stack (Instruction) | | 4 | | 111 1111 0000 0000 0000

Memory Block | Contents | Capacity
0 0000 – 5 6FFF | RAM (Free) | 348 KB
5 7000 – 7 6FFF | ROM (OS) | 128 KB
7 7000 – 7 EFFF | Video | 32 KB
7 F000 – 7 F3FF | Sound | 1 KB
7 F400 – 7 F6FF | General I/O | 768 B
7 F700 – 7 F7FF | Interrupt Vectors | 256 B
7 F800 – 7 FFFF | Stack | 2 KB

Memory Block | Contents | Capacity
7 FF00 – 7 FFFF | Interrupt Vectors | 256 B
7 FE00 – 7 FEFF | I/O#7 (Sound) | 256 B
7 FC00 – 7 FDFF | I/O#6 | 512 B
7 F800 – 7 FBFF | I/O#5 | 1 KB
7 F000 – 7 F7FF | I/O#4 | 2 KB
7 E000 – 7 EFFF | I/O#3 | 4 KB
7 C000 – 7 DFFF | I/O#2 | 8 KB
7 8000 – 7 BFFF | I/O#1 | 16 KB
7 0000 – 7 7FFF | I/O#0 (Video) | 32 KB
5 0000 – 6 FFFF | ROM | 128 KB
0 0000 – 4 FFFF | RAM (Free) | 320 KB

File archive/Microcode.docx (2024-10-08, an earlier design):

Legend

HLT – Halt Clock

MPI – Memory Pointer In

MI – Memory Data In

MO – Memory Data Out

CI – Program Counter In

CO – Program Counter Out

CC – Program Counter Count

II – Instruction Register In

IO – Instruction Register Out

GPI – General Register Pointers In

GPO – General Register Destination Pointer Override

GI – General Register Bank In

GO – General Register Bank Out

SC – Stack Pointer Count

SR – Stack Pointer Reverse

SI – Stack Data In

SO – Stack Data Out

RC – Return Pointer Count

RR – Return Pointer Reverse

RI – Return Data In

RO – Return Data Out

AO – ALU Result Out

ASU – ALU Subtract

AIN – ALU Increment

ADC – ALU Decrement

ANT – ALU Not

AND – ALU And

AOR – ALU Or

AXR – ALU Xor

ASH – ALU Shift Left

ART – ALU Rotate Left

FI – Flags Register In

FO – Flags Register Out

TAI – Temporary Register Address Bus In

TAO – Temporary Register Address Bus Out

TDI – Temporary Register Data Bus In

TDO – Temporary Register Data Bus Out

Fetch

CO, MPI, MO, II

CC, [else]

Mov

CO, MPI, MO, II (Fetch instruction)

CC, IO, GPI (Store Reg-Sel)

GO, TDI (Store value to Temp)

CO, MPI, MO, GPI (Fetch and store Reg-Sel)

CC, TDO, GI (Copy value to Reg)

Wait

[null] (Do nothing; still respond to interrupts)

Lda

CO, MPI, MO, II (Fetch instruction)

CC, IO, GPI (Store Reg-Sel)

CO, MPI, MO, TAI (Store address in Temp)

CC, TAO, MPI (Fetch data at address)

Source is written to Temp register. Dest is overridden to the output of the Regs. Temp is added to Dest and written to Dest.

For ADD… GO and GPO and TI controls allow Source Pointer to place Source in Temp Register; then GI and TO allows Source to be added to Destination.

ALU always uses Source Register (which can be overwritten by Destination Pointer to be Destination Register) for Operand A and Temporary Register as Operand B.

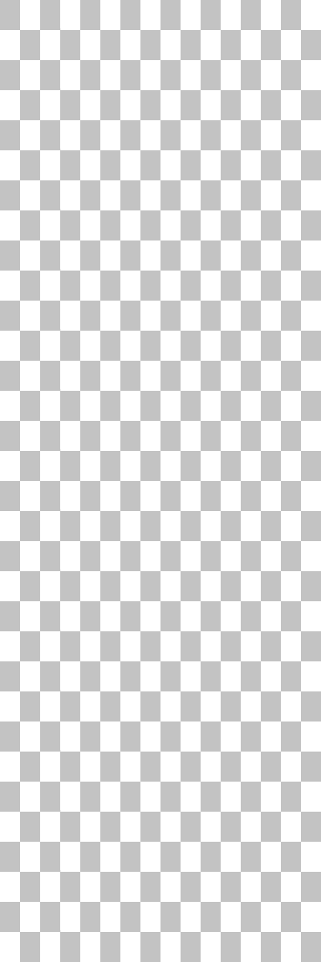
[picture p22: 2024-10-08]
hardware/video/video_adapter/fonts/24x36 Font.png

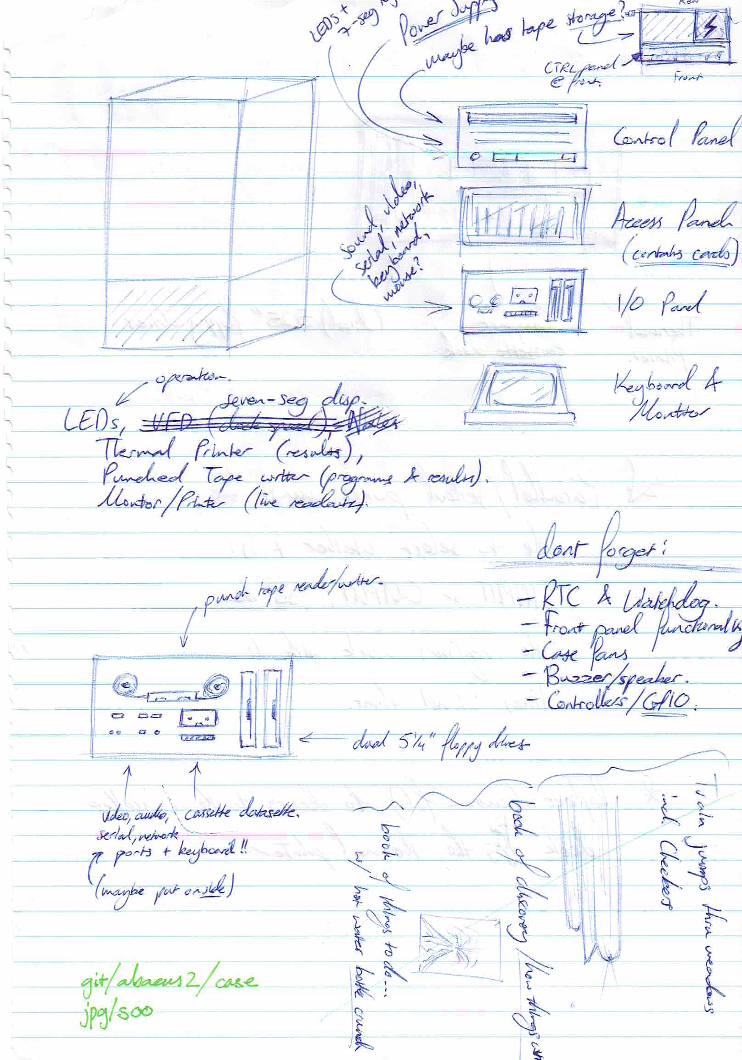
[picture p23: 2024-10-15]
hardware/case/s00.JPG

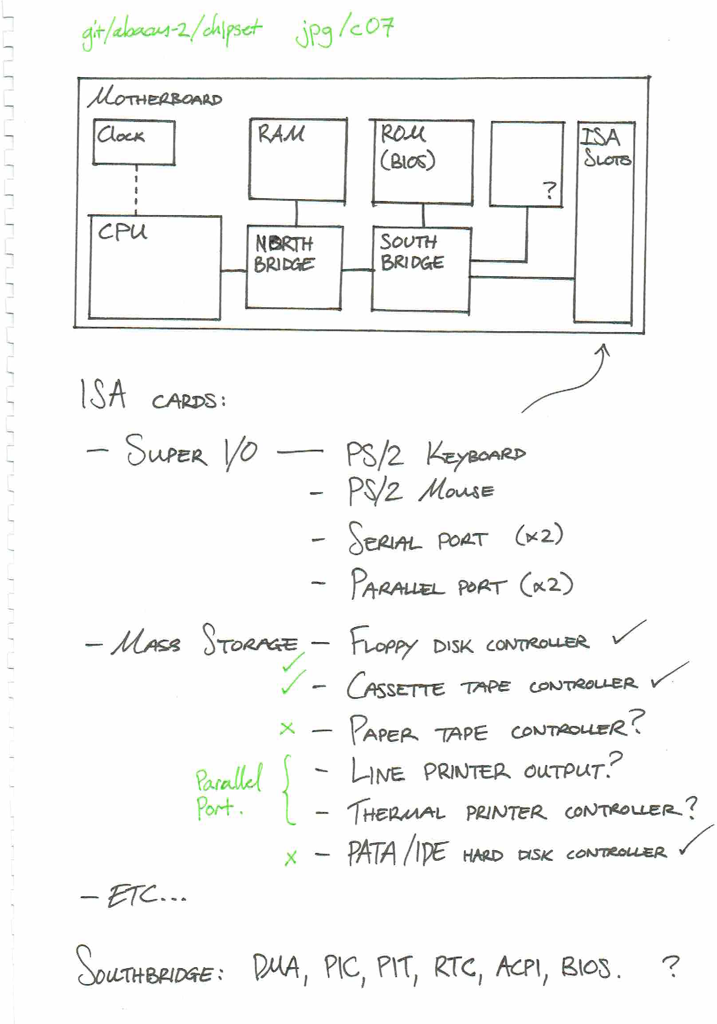
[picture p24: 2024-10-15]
hardware/chipset/c07.JPG

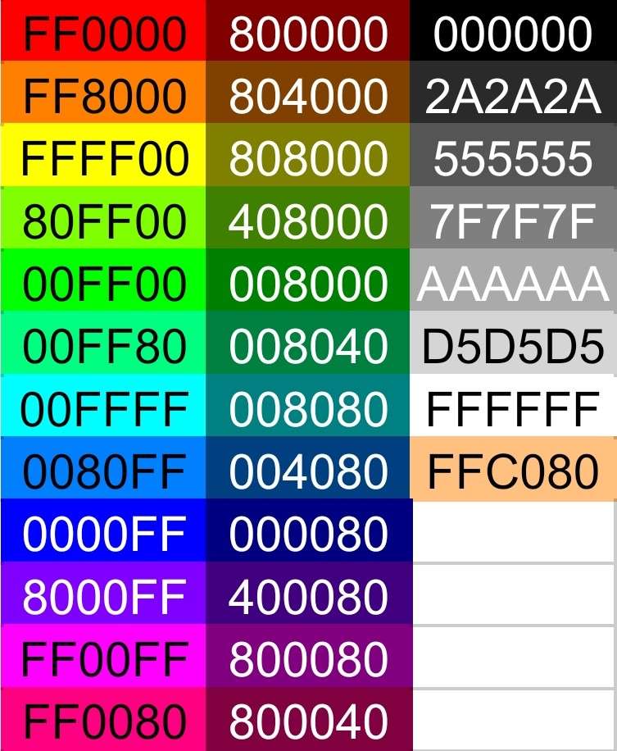
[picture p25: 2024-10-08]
hardware/video/video_adapter/resources/Screenshot_2023-12-20-02-18-27-25_f90b96e7af3c5a594eb0c92de7fc5fe12.jpg

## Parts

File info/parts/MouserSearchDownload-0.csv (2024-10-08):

Mouser Part Number | Mfr Part Number | Mfr. | Datasheet | Availability | Pricing | RoHS | Lifecycle | Product Detail | Product | Logic Function | Logic Family | Number of Gates | Number of Input Lines | Number of Output Lines | High Level Output Current | Low Level Output Current | Propagation Delay Time | Supply Voltage - Max | Supply Voltage - Min | Minimum Operating Temperature | Maximum Operating Temperature | Mounting Style | Package/Case | Packaging
595-CD4082BE | CD4082BE | Texas Instruments | https://www.ti.com/general/docs/suppproductinfo.tsp?distId=26&gotoUrl=https://www.ti.com/lit/gpn/cd4082b | 8,264 In Stock | ="$1.20" | RoHS Compliant |  | https://au.mouser.com/ProductDetail/Texas-Instruments/CD4082BE?qs=KaAwwOlwapuurJwzCPQBUQ%3D%3D | Single-Function Gates | AND | CD4000 | 2 Gate | 8 Input | 2 Output | - 6.8 mA | 6.8 mA | 60 ns | 18 V | 3 V | - 55 C | + 125 C | Through Hole | PDIP-14 | Tube
595-SN74HC08NE4 | SN74HC08NE4 | Texas Instruments | https://www.ti.com/general/docs/suppproductinfo.tsp?distId=26&gotoUrl=https://www.ti.com/lit/gpn/sn74hc08 | 5,525 In Stock | ="$1.17" | RoHS Compliant |  | https://au.mouser.com/ProductDetail/Texas-Instruments/SN74HC08NE4?qs=AgY10sKTvDKZbeCue%2Fg%2Fhg%3D%3D | Single-Function Gates | AND | HC | 4 Gate | 8 Input | 4 Output | - 5.2 mA | 5.2 mA | 8 ns | 6 V | 2 V | - 40 C | + 85 C | Through Hole | PDIP-14 | Tube
595-SN74HC86NE4 | SN74HC86NE4 | Texas Instruments | https://www.ti.com/general/docs/suppproductinfo.tsp?distId=26&gotoUrl=https://www.ti.com/lit/gpn/sn74hc86 | 4,219 In Stock | ="$1.57" | RoHS Compliant |  | https://au.mouser.com/ProductDetail/Texas-Instruments/SN74HC86NE4?qs=AgY10sKTvDJ1JKuZG2yHJg%3D%3D | Single-Function Gates | XOR | HC | 4 Gate | 8 Input | 4 Output | - 5.2 mA | 5.2 mA | 10 ns | 6 V | 2 V | - 40 C | + 85 C | Through Hole | PDIP-14 | Tube
595-CD4093BE | CD4093BE | Texas Instruments | https://www.ti.com/general/docs/suppproductinfo.tsp?distId=26&gotoUrl=https://www.ti.com/lit/gpn/cd4093b | 59,831 In Stock | ="$0.794" | RoHS Compliant |  | https://au.mouser.com/ProductDetail/Texas-Instruments/CD4093BE?qs=X1HXWTtiZ0QxcrKuDdZ5rg%3D%3D | Single-Function Gates | NAND | CD4000 | 4 Gate | 8 Input | 4 Output | - 6.8 mA | 6.8 mA | 65 ns | 18 V | 3 V | - 55 C | + 125 C | Through Hole | PDIP-14 | Tube
595-SN74HC00AN | SN74HC00AN | Texas Instruments | https://www.ti.com/lit/ds/symlink/sn74hc00.pdf?ts=1605228534576 | 9,056 In Stock | ="$1.17" | RoHS Compliant |  | https://au.mouser.com/ProductDetail/Texas-Instruments/SN74HC00AN?qs=6ZVwTuetbD7YqMbSpl34ug%3D%3D | Single-Function Gates | NAND | HC | 4 Gate | 8 Input | 4 Output | - 5.2 mA | 5.2 mA | 8 ns | 6 V | 2 V | - 40 C | + 85 C | Through Hole | PDIP-14 | Tube
595-SN74S20NE4 | SN74S20NE4 | Texas Instruments | https://www.ti.com/general/docs/suppproductinfo.tsp?distId=26&gotoUrl=https://www.ti.com/lit/gpn/sn74s20 | 279 In Stock | ="$4.83" | RoHS Compliant |  | https://au.mouser.com/ProductDetail/Texas-Instruments/SN74S20NE4?qs=dT9u2OTAaVXpwRa5gE7lOA%3D%3D | Single-Function Gates | NAND | S | 2 Gate | 8 Input | 2 Output | - 1 mA | 20 mA | 5 ns | 5.25 V | 4.75 V | 0 C | + 70 C | Through Hole | PDIP-14 | Tube
595-CD4070BE | CD4070BE | Texas Instruments | https://www.ti.com/general/docs/suppproductinfo.tsp?distId=26&gotoUrl=https://www.ti.com/lit/gpn/cd4070b | 16,836 In Stock | ="$0.81" | RoHS Compliant |  | https://au.mouser.com/ProductDetail/Texas-Instruments/CD4070BE?qs=5WY7Uqh921w5Ya0dPgjorQ%3D%3D | Single-Function Gates | XOR | CD4000 | 4 Gate | 8 Input | 4 Output | - 6.8 mA | 6.8 mA | 65 ns | 18 V | 3 V | - 55 C | + 125 C | Through Hole | PDIP-14 | Tube
595-CD4081BEE4 | CD4081BEE4 | Texas Instruments | https://www.ti.com/general/docs/suppproductinfo.tsp?distId=26&gotoUrl=https://www.ti.com/lit/gpn/cd4081b | 793 In Stock | ="$1.54" | RoHS Compliant |  | https://au.mouser.com/ProductDetail/Texas-Instruments/CD4081BEE4?qs=HTr%252BoA4jRiloxIEWd2QErQ%3D%3D | Single-Function Gates | AND | CD4000 | 4 Gate | 8 Input | 4 Output | - 6.8 mA | 6.8 mA | 60 ns | 18 V | 3 V | - 55 C | + 125 C | Through Hole | PDIP-14 | Tube
595-CD4001BE | CD4001BE | Texas Instruments | https://www.ti.com/general/docs/suppproductinfo.tsp?distId=26&gotoUrl=https://www.ti.com/lit/gpn/cd4001b | 14,496 In Stock | ="$0.859" | RoHS Compliant |  | https://au.mouser.com/ProductDetail/Texas-Instruments/CD4001BE?qs=Tv815z3GeNSKspfG7F34rg%3D%3D | Single-Function Gates | NOR | CD4000 | 4 Gate | 8 Input | 4 Output | - 6.8 mA | 6.8 mA | 60 ns | 18 V | 3 V | - 55 C | + 125 C | Through Hole | PDIP-14 | Tube
595-SN74HC7002NE4 | SN74HC7002NE4 | Texas Instruments | https://www.ti.com/general/docs/suppproductinfo.tsp?distId=26&gotoUrl=https://www.ti.com/lit/gpn/sn74hc7002 | 102 In Stock | ="$6.01" | RoHS Compliant |  | https://au.mouser.com/ProductDetail/Texas-Instruments/SN74HC7002NE4?qs=AgY10sKTvDLVliWXT%252BU1YA%3D%3D | Single-Function Gates | NOR | HC | 4 Gate | 8 Input | 4 Output | - 5.2 mA | 5.2 mA | 14 ns | 6 V | 2 V | - 40 C | + 85 C | Through Hole | PDIP-14 | Tube
595-CD74HC32EE4 | CD74HC32EE4 | Texas Instruments | https://www.ti.com/general/docs/suppproductinfo.tsp?distId=26&gotoUrl=https://www.ti.com/lit/gpn/cd74hc32 | 1,180 In Stock | ="$1.05" | RoHS Compliant |  | https://au.mouser.com/ProductDetail/Texas-Instruments/CD74HC32EE4?qs=xFfolx0DHx3KUZ2O2iMjlg%3D%3D | Single-Function Gates | OR | HC | 4 Gate | 8 Input | 4 Output | - 5.2 mA | 5.2 mA | 15 ns | 6 V | 2 V | - 55 C | + 125 C | Through Hole | PDIP-14 | Tube
595-CD74HCT32EE4 | CD74HCT32EE4 | Texas Instruments | https://www.ti.com/general/docs/suppproductinfo.tsp?distId=26&gotoUrl=https://www.ti.com/lit/gpn/cd74hct32 | 195 In Stock | ="$1.28" | RoHS Compliant |  | https://au.mouser.com/ProductDetail/Texas-Instruments/CD74HCT32EE4?qs=xFfolx0DHx2nbN4wbr6qGA%3D%3D | Single-Function Gates | OR | HCT | 4 Gate | 8 Input | 4 Output | - 4 mA | 4 mA | 24 ns | 5.5 V | 4.5 V | - 55 C | + 125 C | Through Hole | PDIP-14 | Tube
595-CD4081BE | CD4081BE | Texas Instruments | https://www.ti.com/general/docs/suppproductinfo.tsp?distId=26&gotoUrl=https://www.ti.com/lit/gpn/cd4081b | 15,093 In Stock | ="$1.13" | RoHS Compliant |  | https://au.mouser.com/ProductDetail/Texas-Instruments/CD4081BE?qs=dQbkqP7qjaZ0jSz5I7zHYA%3D%3D | Single-Function Gates | AND | CD4000 | 4 Gate | 8 Input | 4 Output | - 6.8 mA | 6.8 mA | 60 ns | 18 V | 3 V | - 55 C | + 125 C | Through Hole | PDIP-14 | Tube
595-CD4023BEE4 | CD4023BEE4 | Texas Instruments | https://www.ti.com/general/docs/suppproductinfo.tsp?distId=26&gotoUrl=https://www.ti.com/lit/gpn/cd4023b | 1,080 In Stock | ="$1.36" | RoHS Compliant |  | https://au.mouser.com/ProductDetail/Texas-Instruments/CD4023BEE4?qs=HTr%252BoA4jRil%252BXERw7u%252BFHg%3D%3D | Single-Function Gates | NAND | CD4000 | 3 Gate | 9 Input | 3 Output | - 6.8 mA | 6.8 mA | 60 ns | 18 V | 3 V | - 55 C | + 125 C | Through Hole | PDIP-14 | Tube
595-74ACT11032NE4 | 74ACT11032NE4 | Texas Instruments | https://www.ti.com/general/docs/suppproductinfo.tsp?distId=26&gotoUrl=https://www.ti.com/lit/gpn/74act11032 | 263 In Stock | ="$4.83" | RoHS Compliant |  | https://au.mouser.com/ProductDetail/Texas-Instruments/74ACT11032NE4?qs=yhNIDeTE%252Bcb0UZT3WEUQXw%3D%3D | Single-Function Gates | OR | ACT | 4 Gate | 8 Input | 4 Output | - 24 mA | 24 mA | 6.2 ns | 5.5 V | 4.5 V | - 40 C | + 85 C | Through Hole | PDIP-16 | Tube
595-CD4025BEE4 | CD4025BEE4 | Texas Instruments | https://www.ti.com/general/docs/suppproductinfo.tsp?distId=26&gotoUrl=https://www.ti.com/lit/gpn/cd4025b | 482 In Stock | ="$1.43" | RoHS Compliant |  | https://au.mouser.com/ProductDetail/Texas-Instruments/CD4025BEE4?qs=HTr%252BoA4jRik3OPx6eUsmLg%3D%3D | Single-Function Gates | NOR | CD4000 | 3 Gate | 9 Input | 3 Output | - 6.8 mA | 6.8 mA | 60 ns | 18 V | 3 V | - 55 C | + 125 C | Through Hole | PDIP-14 | Tube
595-SN74LS86ANE4 | SN74LS86ANE4 | Texas Instruments | https://www.ti.com/general/docs/suppproductinfo.tsp?distId=26&gotoUrl=https://www.ti.com/lit/gpn/sn74ls86a | 1,108 In Stock | ="$1.31" | RoHS Compliant |  | https://au.mouser.com/ProductDetail/Texas-Instruments/SN74LS86ANE4?qs=UG%2F8xqv%2F6WdUoTaDIpbxrw%3D%3D | Single-Function Gates | XOR | LS | 4 Gate | 8 Input | 4 Output | - 400 uA | 8 mA | 20 ns | 5.25 V | 4.75 V | 0 C | + 70 C | Through Hole | PDIP-14 | Tube
595-CD74AC20E | CD74AC20E | Texas Instruments | https://www.ti.com/general/docs/suppproductinfo.tsp?distId=26&gotoUrl=https://www.ti.com/lit/gpn/cd74ac20 | 1,065 In Stock | ="$1.49" | RoHS Compliant |  | https://au.mouser.com/ProductDetail/Texas-Instruments/CD74AC20E?qs=bvpNxolhIUP11ckaxDwD7A%3D%3D | Single-Function Gates | NAND | AC | 2 Gate | 8 Input | 2 Output | - 24 mA | 24 mA | 12.2 ns | 5.5 V | 1.5 V | - 55 C | + 125 C | Through Hole | PDIP-14 | Tube
595-CD4011BE | CD4011BE | Texas Instruments | https://www.ti.com/general/docs/suppproductinfo.tsp?distId=26&gotoUrl=https://www.ti.com/lit/gpn/cd4011b | 22,729 In Stock | ="$0.859" | RoHS Compliant |  | https://au.mouser.com/ProductDetail/Texas-Instruments/CD4011BE?qs=st7IWvlL5%2FgbunuzXw39Lg%3D%3D | Single-Function Gates | NAND | CD4000 | 4 Gate | 8 Input | 4 Output | - 6.8 mA | 6.8 mA | 60 ns | 18 V | 3 V | - 55 C | + 125 C | Through Hole | PDIP-14 | Tube
595-CD4082BEE4 | CD4082BEE4 | Texas Instruments | https://www.ti.com/general/docs/suppproductinfo.tsp?distId=26&gotoUrl=https://www.ti.com/lit/gpn/cd4082b | 1,143 In Stock | ="$1.22" | RoHS Compliant |  | https://au.mouser.com/ProductDetail/Texas-Instruments/CD4082BEE4?qs=HTr%252BoA4jRinkkqvflbAJbQ%3D%3D | Single-Function Gates | AND | CD4000 | 2 Gate | 8 Input | 2 Output | - 6.8 mA | 6.8 mA | 60 ns | 18 V | 3 V | - 55 C | + 125 C | Through Hole | PDIP-14 | Tube
595-CD4572UBEE4 | CD4572UBEE4 | Texas Instruments | https://www.ti.com/general/docs/suppproductinfo.tsp?distId=26&gotoUrl=https://www.ti.com/lit/gpn/cd4572ub | 357 In Stock | ="$3.06" | RoHS Compliant |  | https://au.mouser.com/ProductDetail/Texas-Instruments/CD4572UBEE4?qs=HTr%252BoA4jRilTme890hfCEA%3D%3D | Configurable Multiple-Function Gates | NAND, NOR, Inverter | CD4000 | 6 Gate | 8 Input | 1 Output | - 6.8 mA | 6.8 mA | 40 ns | 18 V | 3 V | - 55 C | + 125 C | Through Hole | PDIP-16 | Tube
595-SN74LS11NE4 | SN74LS11NE4 | Texas Instruments | https://www.ti.com/general/docs/suppproductinfo.tsp?distId=26&gotoUrl=https://www.ti.com/lit/gpn/sn74ls11 | 991 In Stock | ="$1.49" | RoHS Compliant |  | https://au.mouser.com/ProductDetail/Texas-Instruments/SN74LS11NE4?qs=SL3LIuy2dWzy1xEz4RR1WQ%3D%3D | Single-Function Gates | AND | LS | 3 Gate | 9 Input | 3 Output | - 400 uA | 8 mA | 10 ns | 5.25 V | 4.75 V | 0 C | + 70 C | Through Hole | PDIP-14 | Tube
595-SN74AHCT132N | SN74AHCT132N | Texas Instruments | https://www.ti.com/general/docs/suppproductinfo.tsp?distId=26&gotoUrl=https://www.ti.com/lit/gpn/sn74ahct132 | 2,548 In Stock | ="$1.25" | RoHS Compliant |  | https://au.mouser.com/ProductDetail/Texas-Instruments/SN74AHCT132N?qs=b0gIXGU74fPl3IUCZE74OQ%3D%3D | Single-Function Gates | NAND | AHCT | 4 Gate | 8 Input | 4 Output | - 8 mA | 8 mA | 6.5 ns | 5.5 V | 4.5 V | - 40 C | + 85 C | Through Hole | PDIP-14 | Tube
595-SN74HC10NE4 | SN74HC10NE4 | Texas Instruments | https://www.ti.com/general/docs/suppproductinfo.tsp?distId=26&gotoUrl=https://www.ti.com/lit/gpn/sn74hc10 | 230 In Stock | ="$1.25" | RoHS Compliant |  | https://au.mouser.com/ProductDetail/Texas-Instruments/SN74HC10NE4?qs=AgY10sKTvDIgfHULZlg4JA%3D%3D | Single-Function Gates | NAND | HC | 3 Gate | 9 Input | 3 Output | - 5.2 mA | 5.2 mA | 9 ns | 6 V | 2 V | - 40 C | + 85 C | Through Hole | PDIP-14 | Tube
595-CD4011UBEE4 | CD4011UBEE4 | Texas Instruments | https://www.ti.com/general/docs/suppproductinfo.tsp?distId=26&gotoUrl=https://www.ti.com/lit/gpn/cd4011ub | 745 In Stock | ="$1.28" | RoHS Compliant |  | https://au.mouser.com/ProductDetail/Texas-Instruments/CD4011UBEE4?qs=HTr%252BoA4jRinJNauBhIS10Q%3D%3D | Single-Function Gates | NAND | CD4000 | 4 Gate | 8 Input | 4 Output | - 6.8 mA | 6.8 mA | 30 ns | 18 V | 3 V | - 55 C | + 125 C | Through Hole | PDIP-14 | Tube

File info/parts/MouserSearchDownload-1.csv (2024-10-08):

Mouser Part Number | Mfr Part Number | Mfr. | Datasheet | Availability | Pricing | RoHS | Lifecycle | Product Detail | Mounting Style | Package/Case | Logic Family | Logic Type
595-SN74HC595N | SN74HC595N | Texas Instruments | https://www.ti.com/general/docs/suppproductinfo.tsp?distId=26&gotoUrl=https://www.ti.com/lit/gpn/sn74hc595 | 72,899 In Stock | ="$1.91" | RoHS Compliant |  | https://au.mouser.com/ProductDetail/Texas-Instruments/SN74HC595N | Through Hole | PDIP-16 | 74HC | CMOS
584-AD734ANZ | AD734ANZ | Analog Devices | https://au.mouser.com/datasheet/2/609/AD734-3118823.pdf | 3,824 In Stock | ="$75.33" | RoHS Compliant |  | https://au.mouser.com/ProductDetail/Analog-Devices/AD734ANZ | Through Hole | PDIP-14
998-MIC58P42YN | MIC58P42YN | Microchip Technology | https://au.mouser.com/datasheet/2/268/mic58p42-1891243.pdf | 1,927 In Stock | ="$14.00" | RoHS Compliant |  | https://au.mouser.com/ProductDetail/Microchip-Technology/MIC58P42YN | Through Hole | DIP-18 | TTL | CMOS
595-SN74HC08NE4 | SN74HC08NE4 | Texas Instruments | https://www.ti.com/general/docs/suppproductinfo.tsp?distId=26&gotoUrl=https://www.ti.com/lit/gpn/sn74hc08 | 5,525 In Stock | ="$1.17" | RoHS Compliant |  | https://au.mouser.com/ProductDetail/Texas-Instruments/SN74HC08NE4 | Through Hole | PDIP-14 | HC | 2-Input AND
595-SN74HC86NE4 | SN74HC86NE4 | Texas Instruments | https://www.ti.com/general/docs/suppproductinfo.tsp?distId=26&gotoUrl=https://www.ti.com/lit/gpn/sn74hc86 | 4,219 In Stock | ="$1.57" | RoHS Compliant |  | https://au.mouser.com/ProductDetail/Texas-Instruments/SN74HC86NE4 | Through Hole | PDIP-14 | HC | 2-Input Exclusive-OR
595-CD4099BE | CD4099BE | Texas Instruments | https://www.ti.com/general/docs/suppproductinfo.tsp?distId=26&gotoUrl=https://www.ti.com/lit/gpn/cd4099b | 3,703 In Stock | ="$1.39" | RoHS Compliant |  | https://au.mouser.com/ProductDetail/Texas-Instruments/CD4099BE | Through Hole | PDIP-16 | ="40" | Latch
595-SN74HC574NE4 | SN74HC574NE4 | Texas Instruments | https://www.ti.com/general/docs/suppproductinfo.tsp?distId=26&gotoUrl=https://www.ti.com/lit/gpn/sn74hc574 | 7,554 In Stock | ="$1.39" | RoHS Compliant |  | https://au.mouser.com/ProductDetail/Texas-Instruments/SN74HC574NE4 | Through Hole | PDIP-20 | HC | D-Type Flip-Flop
595-SN75437ANE | SN75437ANE | Texas Instruments | https://www.ti.com/general/docs/suppproductinfo.tsp?distId=26&gotoUrl=https://www.ti.com/lit/gpn/sn75437a | 9,852 In Stock | ="$4.39" | RoHS Compliant |  | https://au.mouser.com/ProductDetail/Texas-Instruments/SN75437ANE | Through Hole | PDIP-16
595-SN74LS175NE4 | SN74LS175NE4 | Texas Instruments | https://www.ti.com/general/docs/suppproductinfo.tsp?distId=26&gotoUrl=https://www.ti.com/lit/gpn/sn74ls175 | 3,666 In Stock | ="$1.67" | RoHS Compliant |  | https://au.mouser.com/ProductDetail/Texas-Instruments/SN74LS175NE4 | Through Hole | PDIP-16 | LS | D-Type Flip-Flop
595-CD74AC573E | CD74AC573E | Texas Instruments | https://www.ti.com/general/docs/suppproductinfo.tsp?distId=26&gotoUrl=https://www.ti.com/lit/gpn/cd74ac573 | 1,870 In Stock | ="$1.83" | RoHS Compliant |  | https://au.mouser.com/ProductDetail/Texas-Instruments/CD74AC573E | Through Hole | PDIP-20 | 74AC | Transparent Latch
595-SN74HC240AN | SN74HC240AN | Texas Instruments | https://www.ti.com/lit/ds/symlink/sn74hc240.pdf?ts=1601064195927 | 6,413 In Stock | ="$1.88" | RoHS Compliant |  | https://au.mouser.com/ProductDetail/Texas-Instruments/SN74HC240AN | Through Hole | PDIP-20 | HC
595-CD4082BE | CD4082BE | Texas Instruments | https://www.ti.com/general/docs/suppproductinfo.tsp?distId=26&gotoUrl=https://www.ti.com/lit/gpn/cd4082b | 8,264 In Stock | ="$1.20" | RoHS Compliant |  | https://au.mouser.com/ProductDetail/Texas-Instruments/CD4082BE | Through Hole | PDIP-14 | CD4000 | 4-Input AND
595-CD4047BEE4 | CD4047BEE4 | Texas Instruments | https://www.ti.com/general/docs/suppproductinfo.tsp?distId=26&gotoUrl=https://www.ti.com/lit/gpn/cd4047b | 4,645 In Stock | ="$1.36" | RoHS Compliant |  | https://au.mouser.com/ProductDetail/Texas-Instruments/CD4047BEE4 | Through Hole | PDIP-14 | CD4000 | Monostable/Astable Multivibrator
595-SN74HC240N | SN74HC240N | Texas Instruments | https://www.ti.com/general/docs/suppproductinfo.tsp?distId=26&gotoUrl=https://www.ti.com/lit/gpn/sn74hc240 | 5,526 In Stock | ="$2.35" | RoHS Compliant |  | https://au.mouser.com/ProductDetail/Texas-Instruments/SN74HC240N | Through Hole | PDIP-20 | HC | CMOS
595-SN74HC595NE4 | SN74HC595NE4 | Texas Instruments | https://www.ti.com/general/docs/suppproductinfo.tsp?distId=26&gotoUrl=https://www.ti.com/lit/gpn/sn74hc595 | 2,410 In Stock | ="$2.59" | RoHS Compliant |  | https://au.mouser.com/ProductDetail/Texas-Instruments/SN74HC595NE4 | Through Hole | PDIP-16 | 74HC | CMOS
595-SN74LS73AN | SN74LS73AN | Texas Instruments | https://www.ti.com/general/docs/suppproductinfo.tsp?distId=26&gotoUrl=https://www.ti.com/lit/gpn/sn74ls73a | 2,534 In Stock | ="$4.10" | RoHS Compliant |  | https://au.mouser.com/ProductDetail/Texas-Instruments/SN74LS73AN | Through Hole | PDIP-14 | LS | J-K Type Flip-Flop
595-CD4028BEE4 | CD4028BEE4 | Texas Instruments | https://www.ti.com/general/docs/suppproductinfo.tsp?distId=26&gotoUrl=https://www.ti.com/lit/gpn/cd4028b | 4,600 In Stock | ="$1.47" | RoHS Compliant |  | https://au.mouser.com/ProductDetail/Texas-Instruments/CD4028BEE4 | Through Hole | PDIP-16 | CD4000 | Decoders/Demultiplexers
595-SN74ALS109AN | SN74ALS109AN | Texas Instruments | https://www.ti.com/general/docs/suppproductinfo.tsp?distId=26&gotoUrl=https://www.ti.com/lit/gpn/sn74als109a | 2,136 In Stock | ="$3.08" | RoHS Compliant |  | https://au.mouser.com/ProductDetail/Texas-Instruments/SN74ALS109AN | Through Hole | PDIP-16 | ALS | J-K Type Flip-Flop
595-SN74HC165NE4 | SN74HC165NE4 | Texas Instruments | https://www.ti.com/general/docs/suppproductinfo.tsp?distId=26&gotoUrl=https://www.ti.com/lit/gpn/sn74hc165 | 2,904 In Stock | ="$2.19" | RoHS Compliant |  | https://au.mouser.com/ProductDetail/Texas-Instruments/SN74HC165NE4 | Through Hole | PDIP-16 | 74HC | CMOS
595-SN74HC138NE4 | SN74HC138NE4 | Texas Instruments | https://www.ti.com/general/docs/suppproductinfo.tsp?distId=26&gotoUrl=https://www.ti.com/lit/gpn/sn74hc138 | 3,758 In Stock | ="$2.01" | RoHS Compliant |  | https://au.mouser.com/ProductDetail/Texas-Instruments/SN74HC138NE4 | Through Hole | PDIP-16 | HC | Decoders/Demultiplexers
998-MIC5891YN | MIC5891YN | Microchip Technology | https://au.mouser.com/datasheet/2/268/MIC5891_8_Bit_Serial_Input_Latched_Source_Driver_D-2930405.pdf | 11,106 In Stock | ="$4.83" | RoHS Compliant |  | https://au.mouser.com/ProductDetail/Microchip-Technology/MIC5891YN | Through Hole | PDIP-16 | TTL | CMOS
595-SN74LS374N | SN74LS374N | Texas Instruments | https://www.ti.com/general/docs/suppproductinfo.tsp?distId=26&gotoUrl=https://www.ti.com/lit/gpn/sn74ls374 | 18,909 In Stock | ="$2.01" | RoHS Compliant |  | https://au.mouser.com/ProductDetail/Texas-Instruments/SN74LS374N | Through Hole | PDIP-20 | LS | Transparent D-Type Latch
595-CD4093BE | CD4093BE | Texas Instruments | https://www.ti.com/general/docs/suppproductinfo.tsp?distId=26&gotoUrl=https://www.ti.com/lit/gpn/cd4093b | 59,831 In Stock | ="$0.794" | RoHS Compliant |  | https://au.mouser.com/ProductDetail/Texas-Instruments/CD4093BE | Through Hole | PDIP-14 | CD4000 | CMOS
579-MCP2120IP | MCP2120-I/P | Microchip Technology | https://au.mouser.com/datasheet/2/268/21618a-74706.pdf | 1,699 In Stock | ="$2.27" | RoHS Compliant |  | https://au.mouser.com/ProductDetail/Microchip-Technology/MCP2120-I-P | Through Hole | PDIP-14 | IrDA
595-CD74AC273E | CD74AC273E | Texas Instruments | https://www.ti.com/general/docs/suppproductinfo.tsp?distId=26&gotoUrl=https://www.ti.com/lit/gpn/cd74ac273 | 3,998 In Stock | ="$2.59" | RoHS Compliant |  | https://au.mouser.com/ProductDetail/Texas-Instruments/CD74AC273E | Through Hole | PDIP-20 | AC | D-Type Flip-Flop

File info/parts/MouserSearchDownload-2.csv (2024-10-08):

Mouser Part Number | Mfr Part Number | Mfr. | Datasheet | Availability | Pricing | RoHS | Lifecycle | Product Detail | Product Type | Mounting Style | Package/Case | Memory Size | Interface Type
700-DS2431T&R | DS2431+T&R | Analog Devices / Maxim Integrated | https://au.mouser.com/datasheet/2/609/DS2431-3122384.pdf | 18,285 In Stock | ="$2.79" | RoHS Compliant |  | https://au.mouser.com/ProductDetail/Analog-Devices-Maxim-Integrated/DS2431%2bTR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 | EEPROM | Through Hole | TO-92-3 | 1 kbit | 1-Wire
579-24AA512-I/P | 24AA512-I/P | Microchip Technology | https://au.mouser.com/datasheet/2/268/21754M-708763.pdf | 8,937 In Stock | ="$2.96" | RoHS Compliant |  | https://au.mouser.com/ProductDetail/Microchip-Technology/24AA512-I-P | EEPROM | Through Hole | PDIP-8 | 512 kbit | 2-Wire, I2C
579-24LC32A-I/P | 24LC32A-I/P | Microchip Technology | https://au.mouser.com/datasheet/2/268/24AA32A_24LC32A_32_Kbit_I2C_Serial_EEPROM_20001713-2898696.pdf | 45,581 In Stock | ="$0.81" | RoHS Compliant |  | https://au.mouser.com/ProductDetail/Microchip-Technology/24LC32A-I-P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 | EEPROM | Through Hole | PDIP-8 | 32 kbit | 2-Wire, I2C
700-DS1250AB-70 | DS1250AB-70+ | Analog Devices / Maxim Integrated | https://au.mouser.com/datasheet/2/609/DS1250AB_DS1250Y-3122471.pdf |  |  | RoHS Compliant |  | https://au.mouser.com/ProductDetail/Analog-Devices-Maxim-Integrated/DS1250AB-70%2b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 | NVRAM | Through Hole | EDIP-32 | 4 Mbit | Parallel
700-DS1245Y-70IND | DS1245Y-70IND+ | Analog Devices / Maxim Integrated | https://au.mouser.com/datasheet/2/609/DS1245AB_DS1245Y-3122370.pdf |  |  | RoHS Compliant |  | https://au.mouser.com/ProductDetail/Analog-Devices-Maxim-Integrated/DS1245Y-70IND%2b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 | NVRAM | Through Hole | EDIP-32 | 1 Mbit | Parallel
700-DS28E25+T | DS28E25+T | Analog Devices / Maxim Integrated | https://au.mouser.com/datasheet/2/609/DS28E25-3122538.pdf | 8,901 In Stock | ="$4.10" | RoHS Compliant |  | https://au.mouser.com/ProductDetail/Analog-Devices-Maxim-Integrated/DS28E25%2bT | EEPROM | Through Hole | TO-92-3 | 4 kbit | 1-Wire
700-DS2430AT&R | DS2430A+T&R | Analog Devices / Maxim Integrated | https://au.mouser.com/datasheet/2/609/DS2430A-3122485.pdf | 9,342 In Stock | ="$4.70" | RoHS Compliant |  | https://au.mouser.com/ProductDetail/Analog-Devices-Maxim-Integrated/DS2430A%2bTR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 | EEPROM | Through Hole | TO-92-3 | 256 bit | 1-Wire
700-DS1230Y-120 | DS1230Y-120+ | Analog Devices / Maxim Integrated | https://au.mouser.com/datasheet/2/609/DS1230AB_DS1230Y-3122264.pdf |  |  | RoHS Compliant |  | https://au.mouser.com/ProductDetail/Analog-Devices-Maxim-Integrated/DS1230Y-120%2b | NVRAM | Through Hole | EDIP-28 | 256 kbit | Parallel
700-DS28E07+T | DS28E07+T | Analog Devices / Maxim Integrated | https://au.mouser.com/datasheet/2/609/DS28E07-3122240.pdf | 59,685 In Stock | ="$2.17" | RoHS Compliant |  | https://au.mouser.com/ProductDetail/Analog-Devices-Maxim-Integrated/DS28E07%2bT | EEPROM | Through Hole | TO-92-3 | 1 kbit | 1-Wire
700-DS28EC20T | DS28EC20+T | Analog Devices / Maxim Integrated | https://au.mouser.com/datasheet/2/609/DS28EC20-3123148.pdf | 25,809 In Stock | ="$5.65" | RoHS Compliant |  | https://au.mouser.com/ProductDetail/Analog-Devices-Maxim-Integrated/DS28EC20%2bT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 | EEPROM | Through Hole | TO-92-3 | 20 kbit | 1-Wire
556-AT27C040-90PU | AT27C040-90PU | Microchip Technology | https://au.mouser.com/datasheet/2/268/doc0189-1368911.pdf | 5,319 In Stock | ="$20.72" | RoHS Compliant |  | https://au.mouser.com/ProductDetail/Microchip-Technology/AT27C040-90PU | EPROM | Through Hole | PDIP-32 | 4 Mbit | Parallel
700-DS24B33+ | DS24B33+ | Analog Devices / Maxim Integrated | https://au.mouser.com/datasheet/2/609/DS24B33-3122733.pdf | 43,160 In Stock | ="$5.69" | RoHS Compliant |  | https://au.mouser.com/ProductDetail/Analog-Devices-Maxim-Integrated/DS24B33%2b | EEPROM | Through Hole | TO-92-3 | 4 kbit | 1-Wire
700-DS1245Y-70 | DS1245Y-70+ | Analog Devices / Maxim Integrated | https://au.mouser.com/datasheet/2/609/DS1245AB_DS1245Y-3122370.pdf |  |  | RoHS Compliant |  | https://au.mouser.com/ProductDetail/Analog-Devices-Maxim-Integrated/DS1245Y-70%2b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 | NVRAM | Through Hole | EDIP-32 | 1 Mbit | Parallel
579-25AA080C-I/P | 25AA080C-I/P | Microchip Technology | https://au.mouser.com/datasheet/2/268/8_Kbit_SPI_Bus_Serial_EEPROM_20002151C-2887481.pdf | 2,275 In Stock | ="$1.23" | RoHS Compliant |  | https://au.mouser.com/ProductDetail/Microchip-Technology/25AA080C-I-P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 | EEPROM | Through Hole | PDIP-8 | 8 kbit | SPI
700-DS1225AB-85 | DS1225AB-85+ | Analog Devices / Maxim Integrated | https://au.mouser.com/datasheet/2/609/DS1225AB_DS1225AD-3122192.pdf |  |  | RoHS Compliant |  | https://au.mouser.com/ProductDetail/Analog-Devices-Maxim-Integrated/DS1225AB-85%2b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 | NVRAM | Through Hole | EDIP-28 | 64 kbit | Parallel
700-DS1230Y-200 | DS1230Y-200+ | Analog Devices / Maxim Integrated | https://au.mouser.com/datasheet/2/609/DS1230AB_DS1230Y-3122264.pdf |  |  | RoHS Compliant |  | https://au.mouser.com/ProductDetail/Analog-Devices-Maxim-Integrated/DS1230Y-200%2b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 | NVRAM | Through Hole | EDIP-28 | 256 kbit | Parallel
579-24LC256-I/P | 24LC256-I/P | Microchip Technology | https://au.mouser.com/datasheet/2/268/24AA256_24LC256_24FC256_256K_I2C_Serial_EEPROM_DS2-3005041.pdf | 14,432 In Stock | ="$1.85" | RoHS Compliant |  | https://au.mouser.com/ProductDetail/Microchip-Technology/24LC256-I-P | EEPROM | Through Hole | PDIP-8 | 256 kbit | 2-Wire, I2C
700-DS1230Y-150 | DS1230Y-150+ | Analog Devices / Maxim Integrated | https://au.mouser.com/datasheet/2/609/DS1230AB_DS1230Y-3122264.pdf |  |  | RoHS Compliant |  | https://au.mouser.com/ProductDetail/Analog-Devices-Maxim-Integrated/DS1230Y-150%2b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 | NVRAM | Through Hole | EDIP-28 | 256 kbit | Parallel
804-25VF080B5CPAE | SST25VF080B-50-4C-PAE | Microchip Technology | https://au.mouser.com/datasheet/2/268/20005045D-1826881.pdf | 2,228 In Stock | ="$2.66" | RoHS Compliant |  | https://au.mouser.com/ProductDetail/Microchip-Technology/SST25VF080B-50-4C-PAE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 | NOR Flash | Through Hole | PDIP-8 | 8 Mbit | SPI
579-25AA256-E/P | 25AA256-E/P | Microchip Technology | https://au.mouser.com/datasheet/2/268/25AA256_25LC256_256K_SPI_Bus_Serial_EEPROM_2000182-2497265.pdf | 1,870 In Stock | ="$2.80" | RoHS Compliant |  | https://au.mouser.com/ProductDetail/Microchip-Technology/25AA256-E-P | EEPROM | Through Hole | PDIP-8 | 256 kbit | SPI
556-28C256-25DM/883 | AT28C256-25DM/883 | Microchip Technology | https://au.mouser.com/datasheet/2/268/doc0006-1108095.pdf | 14 In Stock | ="$361.63" | RoHS Compliant |  | https://au.mouser.com/ProductDetail/Microchip-Technology/AT28C256-25DM-883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 | EEPROM | Through Hole | CDIP-28 | 256 kbit | Parallel
700-DS1250Y-70 | DS1250Y-70+ | Analog Devices / Maxim Integrated | https://au.mouser.com/datasheet/2/609/DS1250AB_DS1250Y-3122580.pdf |  |  | RoHS Compliant |  | https://au.mouser.com/ProductDetail/Analog-Devices-Maxim-Integrated/DS1250Y-70%2b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 | NVRAM | Through Hole | EDIP-32 | 4 Mbit | Parallel
579-11AA010-I/TO | 11AA010-I/TO | Microchip Technology | https://au.mouser.com/datasheet/2/268/11AAXXX_1_Kbit_to_16_Kbit_UNI_O_Serial_EEPROM_Fami-3132853.pdf | 9,792 In Stock | ="$0.437" | RoHS Compliant |  | https://au.mouser.com/ProductDetail/Microchip-Technology/11AA010-I-TO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 | EEPROM | Through Hole | TO-92-3 | 1 kbit | UNI/O Bus
579-24LC512-E/P | 24LC512-E/P | Microchip Technology | https://au.mouser.com/datasheet/2/268/21754M-708763.pdf | 1,967 In Stock | ="$3.16" | RoHS Compliant |  | https://au.mouser.com/ProductDetail/Microchip-Technology/24LC512-E-P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 | EEPROM | Through Hole | PDIP-8 | 512 kbit | 2-Wire, I2C
579-23LC51579-2-I/P | 23LC512-I/P | Microchip Technology | https://au.mouser.com/datasheet/2/268/23A512_23LC512_512_Kbit_SPI_Serial_SRAM_with_SDI_a-2943674.pdf | 2,139 In Stock | ="$3.06" | RoHS Compliant |  | https://au.mouser.com/ProductDetail/Microchip-Technology/23LC512-I-P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 | SRAM | Through Hole | PDIP-8 | 512 kbit | SDI, SPI, SQI

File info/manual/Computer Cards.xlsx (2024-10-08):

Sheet: Grouped Scheme
Type | Component | ID | Support | Card Name | System | Comp. Num. | Version | Part ID | Notes
Core | Processor | 0 | Obsolete | Registers | 2 | 1 | 0 | 2001 | Data Registers, State Registers
Core | Processor | 0 | Obsolete | Memory | 2 | 2 | 0 | 2002 | Memory (Random Access & Stack), Memory Management Unit
Core | Processor | 0 | Obsolete | Arithmetic & Logic | 2 | 3 | 0 | 2003 | Arithmetic Logic Unit
Core | Processor | 0 | Obsolete | Control Logic | 2 | 4 | 0 | 2004 | Instruction Decoder, Control Logic
Core | Processor | 0 | Obsolete | Interrupt & DMA | 2 | 5 | 0 | 2005 | Interrupt Controller, DMA Controller
Core | Processor | 1 | Current | Combined Processor | 2 | 0 | 0 | 2010 | All the components of the individual CPU cards combined into one. This is the first generation/version.
Expansion | System/Output | 4 | Obsolete | Hexadecimal Display & Buzzer | 2 | 2 | 0 | 2042 | Built-In Hexadecimal Display Port, Built-In Buzzer/Speaker Port
Expansion | System | 4 | Obsolete | Timer | 2 | 1 | 0 | 2041 | Interval Timer/Watchdog Timer/Real-Time Clock
Expansion | I/O | 3 | Obsolete | Keyboard & Mouse | 2 | 1 | 0 | 2031 | Keyboard Controller, Mouse Controller
Expansion | I/O | 3 | Obsolete | Dual Serial | 2 | 2 | 0 | 2032 | Dual Serial Ports
Expansion | I/O | 3 | Obsolete | Dual Parallel | 2 | 3 | 0 | 2033 | Dual Parallel Ports
Expansion | Storage | 5 | Obsolete | Paper Tape Controller | 2 | 1 | 0 | 2051 | Paper Tape Punch Controller
Expansion | Storage | 5 | Obsolete | Cassette Tape Controller | 2 | 2 | 0 | 2052 | Cassette Tape Deck Controller
Expansion | Storage | 5 | Obsolete | Floppy Disk Controller | 2 | 3 | 0 | 2053 | Dual Floppy Disk Controller
Expansion | Storage | 5 | Obsolete | Hard Disk Controller | 2 | 4 | 0 | 2054 | Dual Hard Disk Controller
Expansion | Network | 6 | Obsolete | Network Interface Adapter | 2 | 1 | 0 | 2061 | Network Interface Adapter
Expansion | Video | 8 | Obsolete | Composite Video Graphics | 2 | 1 | 0 | 2081 | Composite Video Graphics Adapter
Expansion | Sound | 7 | Obsolete | Programmable Sound Generator | 2 | 1 | 0 | 2071 | Programmable Sound Generator
Expansion | Sound | 7 | Obsolete | FM Synthesizer | 2 | 2 | 0 | 2072 | FM Synthesizer (includes a PSG)
Expansion | Coprocessor | 9 | Obsolete | Mathematics Coprocessor | 2 | 1 | 0 | 2091 | Mathematics Coprocessor
Expansion | Coprocessor | 9 | Obsolete | Graphics Coprocessor | 2 | 2 | 0 | 2092 | Graphics Coprocessor
Expansion | Output | 4 | Obsolete | Thermal Printer Controller | 2 | 3 | 0 | 2043 | Thermal Printer Controller
Expansion | I/O | 3 | Obsolete | Game Controller | 2 | 4 | 0 | 2034 | Quad Game Controller Ports
Expansion | I/O | 3 | Obsolete | GPIO | 2 | 5 | 0 | 2035 | General Purpose I/O Pin Ports
Expansion | System, Network, Output | 4 | Current | Combined System, Network & Printer | 2 | 0 | 0 | 2040 | Interval Timer/Watchdog Timer/Real-Time Clock, PC Speaker/Buzzer, Hexadecimal Display, Network Interface Adapter, Thermal Printer Controller
Expansion | I/O | 3 | Current | Combined I/O | 2 | 0 | 0 | 2030 | Dual Serial Ports, Dual Parallel Ports, Quad Game Controller Ports, GPIO Pins, Keyboard Controller, Mouse Controller
Expansion | Storage | 5 | Current | Combined Storage | 2 | 0 | 0 | 2050 | Floppy-Disk Controller, Hard-Disk Controller, Cassette Deck Controller, Paper Tape Punch Controller
Expansion | Video, Sound | 7 | Current | Combined Graphics & Synthesizer | 2 | 0 | 0 | 2070 | Composite Video Graphics Adapter, FM Synthesizer (incl. PSG). Sound on this card is better than video, so a better video card would be 2080, while a better sound card would be 2075.

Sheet: Serialized Scheme
Type | Component | Support | Card Name | System | Number | Version | Part ID | Notes
Essential | Processor | Obsolete | Registers | 2 | 01 | 0 | 2001 | Data Registers, State Registers
Essential | Processor | Obsolete | Memory | 2 | 02 | 0 | 2002 | Memory (Random Access & Stack), Memory Management Unit
Essential | Processor | Obsolete | Arithmetic & Logic | 2 | 03 | 0 | 2003 | Arithmetic Logic Unit
Essential | Processor | Obsolete | Control Logic | 2 | 04 | 0 | 2004 | Instruction Decoder, Control Logic
Essential | Processor | Obsolete | Interrupt & DMA | 2 | 05 | 0 | 2005 | Interrupt Controller, DMA Controller
Essential | Processor | Current | Combined Processor | 2 | 20 | 0 | 2020 | All the components of the individual CPU cards combined into one. This is the first generation/version.
Expansion | System/Output | Obsolete | Hexadecimal Display & Buzzer | 2 | 31 | 0 | 2031 | Built-In Hexadecimal Display Port, Built-In Buzzer/Speaker Port
Expansion | System | Obsolete | Timer | 2 | 32 | 0 | 2032 | Interval Timer/Watchdog Timer/Real-Time Clock
Expansion | I/O | Obsolete | Keyboard & Mouse | 2 | 33 | 0 | 2033 | Keyboard Controller, Mouse Controller
Expansion | I/O | Obsolete | Dual Serial | 2 | 34 | 0 | 2034 | Dual Serial Ports
Expansion | I/O | Obsolete | Dual Parallel | 2 | 35 | 0 | 2035 | Dual Parallel Ports
Expansion | Storage | Obsolete | Paper Tape Controller | 2 | 36 | 0 | 2036 | Paper Tape Punch Controller
Expansion | Storage | Obsolete | Cassette Tape Controller | 2 | 37 | 0 | 2037 | Cassette Tape Deck Controller
Expansion | Storage | Obsolete | Floppy Disk Controller | 2 | 38 | 0 | 2038 | Dual Floppy Disk Controller
Expansion | Storage | Obsolete | Hard Disk Controller | 2 | 39 | 0 | 2039 | Dual Hard Disk Controller
Expansion | Network | Obsolete | Network Interface Adapter | 2 | 40 | 0 | 2040 | Network Interface Adapter
Expansion | Video | Obsolete | Composite Video Graphics | 2 | 41 | 0 | 2041 | Composite Video Graphics Adapter
Expansion | Sound | Obsolete | Programmable Sound Generator | 2 | 42 | 0 | 2042 | Programmable Sound Generator
Expansion | Sound | Obsolete | FM Synthesizer | 2 | 43 | 0 | 2043 | FM Synthesizer (includes a PSG)
Expansion | Coprocessor | Obsolete | Mathematics Coprocessor | 2 | 44 | 0 | 2044 | Mathematics Coprocessor
Expansion | Coprocessor | Obsolete | Graphics Coprocessor | 2 | 45 | 0 | 2045 | Graphics Coprocessor
Expansion | Output | Obsolete | Thermal Printer Controller | 2 | 46 | 0 | 2046 | Thermal Printer Controller
Expansion | I/O | Obsolete | Game Controller | 2 | 47 | 0 | 2047 | Quad Game Controller Ports
Expansion | I/O | Obsolete | GPIO | 2 | 48 | 0 | 2048 | General Purpose I/O Pin Ports
Expansion | System, Network, Output | Current | Combined System, Network & Printer | 2 | 81 | 0 | 2081 | Interval Timer/Watchdog Timer/Real-Time Clock, PC Speaker/Buzzer, Hexadecimal Display, Network Interface Adapter, Thermal Printer Controller
Expansion | I/O | Current | Combined I/O | 2 | 82 | 0 | 2082 | Dual Serial Ports, Dual Parallel Ports, Quad Game Controller Ports, GPIO Pins, Keyboard Controller, Mouse Controller
Expansion | Storage | Current | Combined Storage | 2 | 83 | 0 | 2083 | Floppy-Disk Controller, Hard-Disk Controller, Cassette Deck Controller, Paper Tape Punch Controller
Expansion | Video, Sound | Current | Combined Graphics & Synthesizer | 2 | 84 | 0 | 2084 | Composite Video Graphics Adapter, FM Synthesizer (incudes a PSG)

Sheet: Minimal Scheme
Type | Component | Support | Card Name | System | Number | Version | Part ID | Notes
Essential | Processor | Current | Combined Processor | 2 | 10 | 0 | 2010 | All the components of the individual CPU cards combined into one. This is the first generation/version.
Expansion | System, Network, Output | Current | Combined System, Network & Printer | 2 | 50 | 0 | 2050 | Interval Timer/Watchdog Timer/Real-Time Clock, PC Speaker/Buzzer, Hexadecimal Display, Network Interface Adapter, Thermal Printer Controller
Expansion | I/O | Current | Combined I/O | 2 | 60 | 0 | 2060 | Dual Serial Ports, Dual Parallel Ports, Quad Game Controller Ports, GPIO Pins, Keyboard Controller, Mouse Controller
Expansion | Storage | Current | Combined Storage | 2 | 70 | 0 | 2070 | Floppy-Disk Controller, Hard-Disk Controller, Cassette Deck Controller, Paper Tape Punch Controller
Expansion | Video, Sound | Current | Combined Graphics & Synthesizer | 2 | 80 | 0 | 2080 | Composite Video Graphics Adapter, FM Synthesizer (incudes a PSG)

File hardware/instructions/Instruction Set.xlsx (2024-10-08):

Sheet: Version 8C
Priority | Category | Name | Code | Range | Size | Addressing |  |  | ⧖ | Opcode | Instruction |  |  |  |  |  | Mo |  | D | S | R/M |  |  | Reg |  |  | Byte 3 | Byte 4 | Byte 5 | Byte 6 | Notes
Core | Data Transfer | Move | MOV | – | 8 | Register8 | ← | Register8 | H | 00 3 0 | 0 | 0 | 0 | 0 | 0 | 0 | 1 | 1 | 0 | 0 | Source |  |  | Dest |  |  |  |  |  |  | Move contents between registers. Mneumonic also serves Load and Store instructions.
 |  |  |  |  |  |  |  | Immediate8 | M | 04 1 0 | 0 | 0 | 0 | 0 | 0 | 1 | 0 | 1 | 0 | 0 |  |  |  | Dest |  |  | Immediate8
 |  |  |  |  | 16 | Register16 | ← | Register16 | H | 00 3 1 | 0 | 0 | 0 | 0 | 0 | 0 | 1 | 1 | 0 | 1 | Source |  |  | Dest
 |  |  |  |  |  |  |  | Immediate16 | M | 04 2 1 | 0 | 0 | 0 | 0 | 0 | 1 | 1 | 0 | 0 | 1 |  |  |  | Dest |  |  | Immediate16
Low |  |  |  | Zero Page | 8 | Register8 | ← | [Disp8] | H | 04 3 0 | 0 | 0 | 0 | 0 | 0 | 1 | 1 | 1 | 0 | 0 |  |  |  | Dest |  |  | Disp8
 |  |  |  |  |  |  | → | [Disp8] | M | 04 3 2 | 0 | 0 | 0 | 0 | 0 | 1 | 1 | 1 | 1 | 0 |  |  |  | Source |  |  | Disp8
 |  |  |  |  | 16 | Register16 | ← | [Disp8] | H | 04 3 1 | 0 | 0 | 0 | 0 | 0 | 1 | 1 | 1 | 0 | 1 |  |  |  | Dest |  |  | Disp8
 |  |  |  |  |  |  | → | [Disp8] | H | 04 3 3 | 0 | 0 | 0 | 0 | 0 | 1 | 1 | 1 | 1 | 1 |  |  |  | Source |  |  | Disp8
Low |  |  |  |  | 8 | Immediate8 | → | [Disp8] | M | 0C 3 2 | 0 | 0 | 0 | 0 | 1 | 1 | 1 | 1 | 1 | 0 |  |  |  |  |  |  | Disp8 | Immediate8
 |  |  |  |  | 16 | Immediate16 | → | [Disp8] | M | 0C 3 3 | 0 | 0 | 0 | 0 | 1 | 1 | 1 | 1 | 1 | 1 |  |  |  |  |  |  | Disp8 | Immediate16
Core |  |  |  | Near | 8 | Register8 | ← | [Disp16] | M | 04 0 0 | 0 | 0 | 0 | 0 | 0 | 1 | 0 | 0 | 0 | 0 |  |  |  | Dest |  |  | Disp16
 |  |  |  |  |  |  |  | [Reg16] | H | 00 0 0 | 0 | 0 | 0 | 0 | 0 | 0 | 0 | 0 | 0 | 0 | Base |  |  | Dest
 |  |  |  |  |  |  |  | [Reg16 + Disp8] | M | 00 1 0 | 0 | 0 | 0 | 0 | 0 | 0 | 0 | 1 | 0 | 0 | Base |  |  | Dest |  |  | Disp8
 |  |  |  |  |  |  |  | [Reg16 + Disp16] | M | 00 2 0 | 0 | 0 | 0 | 0 | 0 | 0 | 1 | 0 | 0 | 0 | Base |  |  | Dest |  |  | Disp16
Core |  |  |  |  | 16 | Register16 | ← | [Disp16] | M | 04 0 1 | 0 | 0 | 0 | 0 | 0 | 1 | 0 | 0 | 0 | 1 |  |  |  | Dest |  |  | Disp16
 |  |  |  |  |  |  |  | [Reg16] | H | 00 0 1 | 0 | 0 | 0 | 0 | 0 | 0 | 0 | 0 | 0 | 1 | Base |  |  | Dest
 |  |  |  |  |  |  |  | [Reg16 + Disp8] | M | 00 1 1 | 0 | 0 | 0 | 0 | 0 | 0 | 0 | 1 | 0 | 1 | Base |  |  | Dest |  |  | Disp8
 |  |  |  |  |  |  |  | [Reg16 + Disp16] | M | 00 2 1 | 0 | 0 | 0 | 0 | 0 | 0 | 1 | 0 | 0 | 1 | Base |  |  | Dest |  |  | Disp16
Med |  |  |  | Near | 8 | Immediate8 | → | [Disp16] | M | 0C 0 2 | 0 | 0 | 0 | 0 | 1 | 1 | 0 | 0 | 1 | 0 |  |  |  |  |  |  | Disp16 |  | Immediate8
 |  |  |  |  |  |  |  | [Reg16] | H | 08 0 2 | 0 | 0 | 0 | 0 | 1 | 0 | 0 | 0 | 1 | 0 | Base |  |  |  |  |  | Immediate8
 |  |  |  |  |  |  |  | [Reg16 + Disp8] | M | 08 1 2 | 0 | 0 | 0 | 0 | 1 | 0 | 0 | 1 | 1 | 0 | Base |  |  |  |  |  | Disp8 | Immediate8
 |  |  |  |  |  |  |  | [Reg16 + Disp16] | M | 08 2 2 | 0 | 0 | 0 | 0 | 1 | 0 | 1 | 0 | 1 | 0 | Base |  |  |  |  |  | Disp16 |  | Immediate8
Core |  |  |  |  |  | Register8 | → | [Disp16] | M | 04 0 2 | 0 | 0 | 0 | 0 | 0 | 1 | 0 | 0 | 1 | 0 |  |  |  | Source |  |  | Disp16
 |  |  |  |  |  |  |  | [Reg16] | H | 00 0 2 | 0 | 0 | 0 | 0 | 0 | 0 | 0 | 0 | 1 | 0 | Base |  |  | Source
 |  |  |  |  |  |  |  | [Reg16 + Disp8] | M | 00 1 2 | 0 | 0 | 0 | 0 | 0 | 0 | 0 | 1 | 1 | 0 | Base |  |  | Source |  |  | Disp8
 |  |  |  |  |  |  |  | [Reg16 + Disp16] | M | 00 2 2 | 0 | 0 | 0 | 0 | 0 | 0 | 1 | 0 | 1 | 0 | Base |  |  | Source |  |  | Disp16
Med |  |  |  |  | 16 | Immediate16 | → | [Disp16] | M | 0C 0 3 | 0 | 0 | 0 | 0 | 1 | 1 | 0 | 0 | 1 | 1 |  |  |  |  |  |  | Disp16 |  | Immediate16
 |  |  |  |  |  |  |  | [Reg16] | M | 08 0 3 | 0 | 0 | 0 | 0 | 1 | 0 | 0 | 0 | 1 | 1 | Base |  |  |  |  |  | Immediate16
 |  |  |  |  |  |  |  | [Reg16 + Disp8] | M | 08 1 3 | 0 | 0 | 0 | 0 | 1 | 0 | 0 | 1 | 1 | 1 | Base |  |  |  |  |  | Disp8 | Immediate16
 |  |  |  |  |  |  |  | [Reg16 + Disp16] | M | 08 2 3 | 0 | 0 | 0 | 0 | 1 | 0 | 1 | 0 | 1 | 1 | Base |  |  |  |  |  | Disp16 |  | Immediate16
Core |  |  |  |  |  | Register16 | → | [Disp16] | M | 04 0 3 | 0 | 0 | 0 | 0 | 0 | 1 | 0 | 0 | 1 | 1 |  |  |  | Source |  |  | Disp16
 |  |  |  |  |  |  |  | [Reg16] | H | 00 0 3 | 0 | 0 | 0 | 0 | 0 | 0 | 0 | 0 | 1 | 1 | Base |  |  | Source
 |  |  |  |  |  |  |  | [Reg16 + Disp8] | M | 00 1 3 | 0 | 0 | 0 | 0 | 0 | 0 | 0 | 1 | 1 | 1 | Base |  |  | Source |  |  | Disp8
 |  |  |  |  |  |  |  | [Reg16 + Disp16] | M | 00 2 3 | 0 | 0 | 0 | 0 | 0 | 0 | 1 | 0 | 1 | 1 | Base |  |  | Source |  |  | Disp16
Low |  | Move Flags | LDRF | – | 8 | Flags8 | ← | Register8 | N | 0C 1 0 | 0 | 0 | 0 | 0 | 1 | 1 | 0 | 1 | 0 | 0 |  |  |  | Source |  |  |  |  |  |  | Load value into Flags register from General register. (Flags8 can be either High or Low half of Flags.)
 |  |  |  |  | 16 | Flags16 | ← | Register16 | N | 0C 1 1 | 0 | 0 | 0 | 0 | 1 | 1 | 0 | 1 | 0 | 1 |  |  |  | Source
 |  |  | STRF | – | 8 | Flags8 | → | Register8 | N | 0C 1 2 | 0 | 0 | 0 | 0 | 1 | 1 | 0 | 1 | 1 | 0 |  |  |  | Dest |  |  |  |  |  |  | Store value from Flags register into General register. (Flags8 can be either High or Low half of Flags.)
 |  |  |  |  | 16 | Flags16 | → | Register16 | N | 0C 1 3 | 0 | 0 | 0 | 0 | 1 | 1 | 0 | 1 | 1 | 1 |  |  |  | Dest
Med |  | Exchange | XCHG | – | 8 | Register8 | ↔ | Register8 | N | 00 3 2 | 0 | 0 | 0 | 0 | 0 | 0 | 1 | 1 | 1 | 0 | Source |  |  | Dest |  |  |  |  |  |  | Swap values between registers.
 |  |  |  |  | 16 | Register16 | ↔ | Register16 | N | 00 3 3 | 0 | 0 | 0 | 0 | 0 | 0 | 1 | 1 | 1 | 1 | Source |  |  | Dest
Core |  | Push | PUSH | – | 8 | Stack16 | ← | Register8 | H | 20 3 2 | 0 | 0 | 1 | 0 | 0 | 0 | 1 | 1 | 1 | 0 |  |  |  | Source |  |  |  |  |  |  | Pushes register value to the stack.
 |  |  |  |  |  |  |  | Immediate8 | L | 14 0 X | 0 | 0 | 0 | 1 | 0 | 1 | 0 | 0 | Immediate8
 |  |  |  |  | 16 |  |  | Register16 | H | 20 3 3 | 0 | 0 | 1 | 0 | 0 | 0 | 1 | 1 | 1 | 1 |  |  |  | Source
 |  |  |  |  |  |  |  | Immediate16 | L | 14 1 X | 0 | 0 | 0 | 1 | 0 | 1 | 0 | 1 | Immediate16
 |  |  |  | Zero Page | 8 |  |  | [Disp8] | L | 18 0 X | 0 | 0 | 0 | 1 | 1 | 0 | 0 | 0 | Disp8
 |  |  |  |  | 16 |  |  | [Disp8] | L | 18 1 X | 0 | 0 | 0 | 1 | 1 | 0 | 0 | 1 | Disp8
 |  |  |  | Near | 8 |  |  | [Disp16] | M | 18 2 X | 0 | 0 | 0 | 1 | 1 | 0 | 1 | 0 | Disp16
 |  |  |  |  |  |  |  | [Reg16] | M | 20 0 2 | 0 | 0 | 1 | 0 | 0 | 0 | 0 | 0 | 1 | 0 | Base |  |  | Source
 |  |  |  |  |  |  |  | [Reg16 + Disp8] | M | 20 1 2 | 0 | 0 | 1 | 0 | 0 | 0 | 0 | 1 | 1 | 0 | Base |  |  | Source |  |  | Disp8
 |  |  |  |  |  |  |  | [Reg16 + Disp16] | M | 20 2 2 | 0 | 0 | 1 | 0 | 0 | 0 | 1 | 0 | 1 | 0 | Base |  |  | Source |  |  | Disp16
 |  |  |  |  | 16 |  |  | [Disp16] | M | 18 3 X | 0 | 0 | 0 | 1 | 1 | 0 | 1 | 1 | Disp16
 |  |  |  |  |  |  |  | [Reg16] | M | 20 0 3 | 0 | 0 | 1 | 0 | 0 | 0 | 0 | 0 | 1 | 1 | Base |  |  | Source
 |  |  |  |  |  |  |  | [Reg16 + Disp8] | M | 20 1 3 | 0 | 0 | 1 | 0 | 0 | 0 | 0 | 1 | 1 | 1 | Base |  |  | Source |  |  | Disp8
 |  |  |  |  |  |  |  | [Reg16 + Disp16] | M | 20 2 3 | 0 | 0 | 1 | 0 | 0 | 0 | 1 | 0 | 1 | 1 | Base |  |  | Source |  |  | Disp16
 |  |  | PUSHF | – | 16 | Stack16 | ← | Flags16 | L | 14 2 3 | 0 | 0 | 0 | 1 | 0 | 1 | 1 | 0 | 1 | 1 |  |  |  |  |  |  |  |  |  |  | Pushes Flags register to the stack.
Core |  | Pop | POP | – | 8 | Stack16 | → | Register8 | H | 20 3 0 | 0 | 0 | 1 | 0 | 0 | 0 | 1 | 1 | 0 | 0 |  |  |  | Dest |  |  |  |  |  |  | Pops register value from the stack.
 |  |  |  |  | 16 |  |  | Register16 | H | 20 3 1 | 0 | 0 | 1 | 0 | 0 | 0 | 1 | 1 | 0 | 1 |  |  |  | Dest
 |  |  |  | Zero Page | 8 |  |  | [Disp8] | L | 1C 0 X | 0 | 0 | 0 | 1 | 1 | 1 | 0 | 0 | Disp8
 |  |  |  |  | 16 |  |  | [Disp8] | L | 1C 1 X | 0 | 0 | 0 | 1 | 1 | 1 | 0 | 1 | Disp8
 |  |  |  | Near | 8 |  |  | [Disp16] | M | 1C 2 X | 0 | 0 | 0 | 1 | 1 | 1 | 1 | 0 | Disp16
 |  |  |  |  |  |  |  | [Reg16] | M | 20 0 0 | 0 | 0 | 1 | 0 | 0 | 0 | 0 | 0 | 0 | 0 | Base |  |  | Source
 |  |  |  |  |  |  |  | [Reg16 + Disp8] | M | 20 1 0 | 0 | 0 | 1 | 0 | 0 | 0 | 0 | 1 | 0 | 0 | Base |  |  | Source |  |  | Disp8
 |  |  |  |  |  |  |  | [Reg16 + Disp16] | M | 20 2 0 | 0 | 0 | 1 | 0 | 0 | 0 | 1 | 0 | 0 | 0 | Base |  |  | Source |  |  | Disp16
 |  |  |  |  | 16 |  |  | [Disp16] | M | 1C 3 X | 0 | 0 | 0 | 1 | 1 | 1 | 1 | 1 | Disp16
 |  |  |  |  |  |  |  | [Reg16] | M | 20 0 1 | 0 | 0 | 1 | 0 | 0 | 0 | 0 | 0 | 0 | 1 | Base |  |  | Source
 |  |  |  |  |  |  |  | [Reg16 + Disp8] | M | 20 1 1 | 0 | 0 | 1 | 0 | 0 | 0 | 0 | 1 | 0 | 1 | Base |  |  | Source |  |  | Disp8
 |  |  |  |  |  |  |  | [Reg16 + Disp16] | M | 20 2 1 | 0 | 0 | 1 | 0 | 0 | 0 | 1 | 0 | 0 | 1 | Base |  |  | Source |  |  | Disp16
 |  |  | POPF | – | 16 | Stack16 | → | Flags16 | L | 14 2 1 | 0 | 0 | 0 | 1 | 0 | 1 | 1 | 0 | 0 | 1 |  |  |  |  |  |  |  |  |  |  | Pops Flags register from the stack.
High |  | In | IN | Near | 8 | Register8 | ← | Port(Disp8) | N | DC 1 X | 1 | 1 | 0 | 1 | 1 | 1 | 0 | 1 | Disp8 |  |  |  |  |  |  |  |  |  |  |  | Input data from port to register.
 |  |  |  |  | 16 | Register16 | ← | Port(Disp8) | N | DC 2 X | 1 | 1 | 0 | 1 | 1 | 1 | 1 | 0 | Disp8
High |  | Out | OUT | Near | 8 | Register8 | → | Port(Disp8) | N | EC 1 X | 1 | 1 | 1 | 0 | 1 | 1 | 0 | 1 | Disp8 |  |  |  |  |  |  |  |  |  |  |  | Output data from rergister to port.
 |  |  |  |  | 16 | Register16 | → | Port(Disp8) | N | EC 2 X | 1 | 1 | 1 | 0 | 1 | 1 | 1 | 0 | Disp8
Low |  | Load Effective Address | LEA | Short | 8 | Register8 | ← | Reg8 + Disp8 | L | 08 2 0 | 0 | 0 | 0 | 0 | 1 | 0 | 1 | 0 | 0 | 0 | Base |  |  | Dest |  |  | Disp8
 |  |  |  | Near | 16 | Register16 | ← | Reg16 + Disp8 | L | 08 1 0 | 0 | 0 | 0 | 0 | 1 | 0 | 0 | 1 | 0 | 0 | Base |  |  | Dest |  |  | Disp8
 |  |  |  |  |  |  |  | Reg16 + Disp16 | L | 08 2 1 | 0 | 0 | 0 | 0 | 1 | 0 | 1 | 0 | 0 | 1 | Base |  |  | Dest |  |  | Disp16
Low | Arithmetic | Sign Extend | CBW | – | 8 | Register8 |  |  | N | 24 3 0 | 0 | 0 | 1 | 0 | 0 | 1 | 1 | 1 | 0 | 0 |  |  |  | Reg |  |  |  |  |  |  | Convert signed Byte to signed Word. (High byte goes into pair register. Doesn't work for High registers.)
High |  | Add | ADD | Zero Page | 8 | Register8 | ←+ | [Disp8] | H | 84 3 0 | 1 | 0 | 0 | 0 | 0 | 1 | 1 | 1 | 0 | 0 |  |  |  | Dest |  |  | Disp8 |  |  |  | Sums two registers or variables.
 |  |  |  |  |  |  | +→ | [Disp8] | M | 84 3 2 | 1 | 0 | 0 | 0 | 0 | 1 | 1 | 1 | 1 | 0 |  |  |  | Source |  |  | Disp8
Med |  |  |  |  | 16 | Register16 | ←+ | [Disp8] | H | 84 3 1 | 1 | 0 | 0 | 0 | 0 | 1 | 1 | 1 | 0 | 1 |  |  |  | Dest |  |  | Disp8
 |  |  |  |  |  |  | +→ | [Disp8] | H | 84 3 3 | 1 | 0 | 0 | 0 | 0 | 1 | 1 | 1 | 1 | 1 |  |  |  | Source |  |  | Disp8
Med |  |  |  |  | 8 | Immediate8 | +→ | [Disp8] | M | 8C 3 2 | 1 | 0 | 0 | 0 | 1 | 1 | 1 | 1 | 1 | 0 |  |  |  |  |  |  | Disp8 | Immediate8
 |  |  |  |  | 16 | Immediate16 | +→ | [Disp8] | M | 8C 3 3 | 1 | 0 | 0 | 0 | 1 | 1 | 1 | 1 | 1 | 1 |  |  |  |  |  |  | Disp8 | Immediate16
Core |  |  |  | Near | 8 | Register8 | ←+ | Immediate8 | M | 84 1 0 | 1 | 0 | 0 | 0 | 0 | 1 | 0 | 1 | 0 | 0 |  |  |  | Dest |  |  | Immediate8
 |  |  |  |  |  |  |  | Register8 | M | 80 3 0 | 1 | 0 | 0 | 0 | 0 | 0 | 1 | 1 | 0 | 0 | Source |  |  | Dest
 |  |  |  |  |  |  |  | [Disp16] | M | 84 0 0 | 1 | 0 | 0 | 0 | 0 | 1 | 0 | 0 | 0 | 0 |  |  |  | Dest |  |  | Disp16
 |  |  |  |  |  |  |  | [Reg16] | H | 80 0 0 | 1 | 0 | 0 | 0 | 0 | 0 | 0 | 0 | 0 | 0 | Base |  |  | Dest
High |  |  |  |  |  |  |  | [Reg16 + Disp8] | M | 80 1 0 | 1 | 0 | 0 | 0 | 0 | 0 | 0 | 1 | 0 | 0 | Base |  |  | Dest |  |  | Disp8
 |  |  |  |  |  |  |  | [Reg16 + Disp16] | H | 80 2 0 | 1 | 0 | 0 | 0 | 0 | 0 | 1 | 0 | 0 | 0 | Base |  |  | Dest |  |  | Disp16
 |  |  |  |  |  | Register8 | +→ | [Disp16] | M | 84 0 2 | 1 | 0 | 0 | 0 | 0 | 1 | 0 | 0 | 1 | 0 |  |  |  | Source |  |  | Disp16
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

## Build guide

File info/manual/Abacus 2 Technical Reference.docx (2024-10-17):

# Carboni 1 Minicomputer

Technical Reference

Jules Carboni, 2016-2024 First Edition, 17 November 20XX

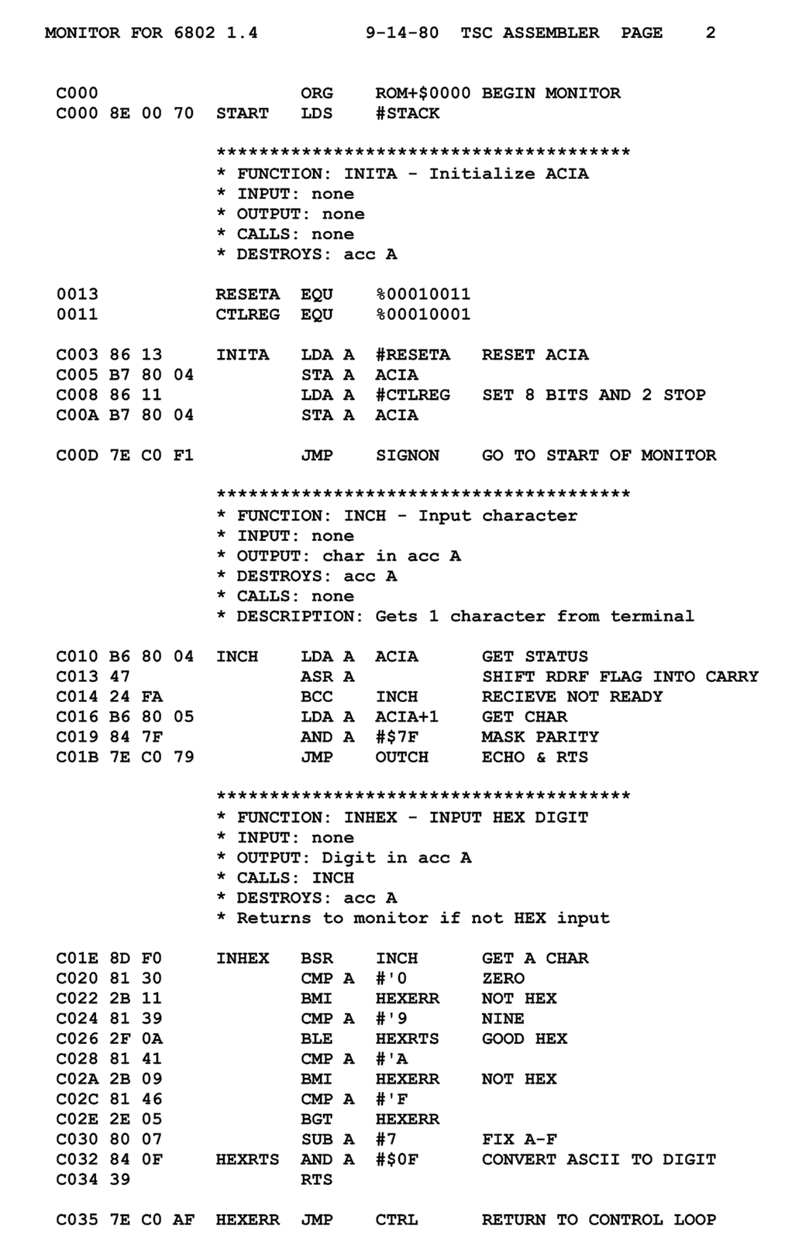
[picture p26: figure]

## Contents

Part One — Introduction Page 3

Background, For Beginners, System Specifications

Part Two — Design Details Page 5

Organisation, Clock, Arithmetic Logic Unit, Registers, Memory, External Storage, Instruction Decoding & Control Logic, Input & Output

Part Three — Operation Details Page X

Power Supply, Front Panel Switches & Indicators, Settings & Modes of Operation, Loading a Program, Using the Memory, Memory Addressing, Operating Hints

Part Four — Instruction Set Page X

Control Pins, Command Instructions, Data Transfer Instructions, Accumulator Instructions, Branching Instructions

Part Five — Programming Guide Page X

Fundamentals of Programming, A Simple Program, Assembly Language, Machine Code, Debugging, Sample Programs, Concept of Operating Systems

Appendix One — Maintenance Information Page X

Hardware Vulnerabilities, Maintenance Advice, Bad Circuitry, Bad Microcode

Appendix Two — Technical Information Page X

Instruction Reference Card, Parts List, System Schematics, Data Sheets

Appendix Three — Supplementary Information Page X

Boolean Algebra, Electronic Logic, Number Systems & Binary, Storing Negative Numbers

## Part 1 — Introduction

Background Page 4

Rationale, Design

For Beginners Page 4

Required Understanding

System Specifications Page 4

Overview

### 1.1 Background

The Abacus 1 was created as a research project with the purpose of exploring how computers function at the lowest level.

Abacus 2 uses an evolution of the Abacus 1 architecture (based on Albert Paul Malvino’s SAP-1/2/3 architecture). The computer is Turing complete; it can compute anything computable within the constraints of its memory size and processing speed (explained further in parts 2.5 & 2.2 respectively). The Abacus 2 instruction set architecture also provides integration with AMD’s AM9511 floating point unit.

The physical construction of Carbon 1 is highly reminiscent of home computers of the 1970s, i.e. MITS Altair 8800. The case opens to allow access to the internals. The “slot card” design allows components—called “modules”—to be easily removed for repair or replacement. The front panel uses LEDs to indicate the logical states of every component in the system, e.g. the registers, to assist the operator in debugging.

### 1.2 For Beginners

This operating manual will describe the architecture, functions and processes of the Abacus 2. An understanding of Boolean algebra, electronic logic, number systems (specifically the binary system) is assumed knowledge. It is highly recommended to understand these concepts fully before continuing. To assist beginners, the introductory section of MITS’ ‘Altair 8800 Operators Manual’ has been included in appendix three “Supplementary Information” of this manual. The excerpt details these concepts to a beginner audience in sufficient detail for comprehension of this manual.

### 1.3 System Specifications

This section of the manual outlines the key technical specifications of the Abacus 2 processor. For more detail see part two “Design Details”.

Power | ATX standard
Architecture | 16-bit, CISC, Von Neumann
Instruction Set | Abacus ISA, 44 instructions
Clock | FM, digital control, ~1Hz–16MHz
ALU | 16-bit, 74181 based
Memory | 4KB–16MB, 8-bit bytes, SRAM
Bus | 16-bits, shared, internal/external

## Part 2 — Design Details

Organisation Page 6

Modules

Clock Page 7

Astable & Monostable Modes, Speeds

Arithmetic Logic Unit Page 7

Arithmetic and Logic Operations

Registers Page 8

Importance of Accumulator, Other Registers, Flags Register

Memory Page 9

Word Length, Addressing, Program Counter

External Storage Page 9

Punched Tape Reader

Instruction Decoding & Control Logic Page 9

Word Length, Control Lines, Fetch Phase

Input & Output Page 9

Front Panel Interface, Seven-Segment Display, Internal State Indicators

### 2.1 Organisation

The organisation of the Abacus 1 is based around “modules”. Each major component of the system comprises its own module. Data is shared between modules on the system’s bus.Below can be observed the order of the Abacus 1’s modules as they are assembled.

Clock

MAR

Memory

Inst. Register

Counter

Accumulator

ALU

Register B

Output

Tape

Inst. Decoder

Flags

B

u

s

12 LSB

12 LSB

4 MSB

12 LSB

12 LSB

4 LSB

Hlt

Co Ce

J Jc Jz

Mi

Ri Ro

Ii Io

Ai Ao

Bi

Fi Fo

Eo Su Xr

An Or Nt

Oi

Clock

Counter

MAR

Memory

Accumulator

ALU

Flags

Register B

Instruction

Output

Tape

TEMPORARY GRAPHIC

### 2.2 Clock

The clock synchronises the actions of the whole system, keeping every component coordinated. Each component of the system activates and operates in time with the pulsing of the clock—the more frequent the clock pulses the faster the system operates.

The Abacus 1 internal clock has an adjustable clock speed in the range of 0.721Hz to 4810Hz (~5KHz). The duty cycle ranges from 50% high at 0.7Hz to 66.67% high at 4.8KHz. The clock is not regulated by a crystal, using only a 555 timer integrated circuit.

Each fetch-decode-execute cycle requires two to five clock pulses to complete, resulting in an execution rate in the range of 962 to 2405 instructions per second (IPS), with an approximate weighted average of 1150 IPS.

The Hlt control feeds back to the clock and halts it, so that neither a-stable nor monostable modes will output a clock pulse to the system, effectively freezing the computer until it is reset. This control is tied to the Hlt instruction which can be used in programs.

### 2.3 Arithmetic Logic Unit

At the heart of every computer is the Arithmetic Logic Unit, a device for performing operations on numbers. The Abacus 1’s ALU can perform six functions:

- Arithmetical Addition
- Arithmetical Subtraction
- Logical Exclusive Or
- Logical And
- Logical Or
- Logical Not

Note; all arithmetic operations are performed by addition (subtraction is just inverse addition); this means it is easily possible to write programs to perform multiplication and division, despite these functions not being implemented in hardware. Shift and rotate functions can also be implemented this way.

After the ALU has finished its operation, it will update the Flags Register. This enables the ALU to be used to implement comparative instructions that are not available as explicit instructions in the instruction set, such as “greater than” and “equal to”.

### 2.4 Registers

Every register in the Abacus 1 minicomputer serves a special purpose, there are no “general purpose” registers that can be used freely for variable storage—variables must be stored in memory. The unique features and uses of each register will be described in the following parts.

The A Register, known as the accumulator, is imperative to the functionality of the Abacus 1. It holds the current value being operated on, particularly during arithmetic and logic operations, and is where the results of these operations are eventually loaded/located. The accumulator is accessible via instructions and can be read and written to directly.

The B Register is electrically identical to the accumulator and holds intermediate or secondary values during operations that require the arithmetic and logic unit. However, unlike the accumulator, the B Register is not accessible to the end user and cannot be read or written to directly.

The Instruction Register takes in the four most significant bits on the bus (the instruction) and relays the value to the instruction decoder/control logic component. This register cannot be accessed by the user at all.

The Memory Address Register will be discussed in 2.5 “Memory” of this manual.

The Program Counter will be discussed in 2.5 “Memory” of this manual.

The Flags Register operates differently to the other registers. It stores the status of four conditions which may or may not be affected by the result of an operation. It is only readable through the Ldf instruction and cannot be read or written to directly. The four status bits are:

- Carry bit—This bit is set to 1 if a carry has occurred during an arithmetical or logical operation. The bit is reset to 0 is no carry occurs.
- Zero bit—This bit is set to 1 if the result of arithmetic or logic instructions is zero and reset to 0 is the result is not zero.
- Sign bit—This bit is set to show the sign of a result. If set to 1, the result is negative; if set to 0 the result is positive. The sign bit reflects the condition of the most significant bit in the result (bit number 15).
- Overflow bit—This bit indicates that an operation incorrectly changed the sign bit of the result. This happens when the result of an arithmetic operation exceeds the maximum value that can be stored in the 16-bit ALU’s “sum” register.

The carry bit and zero bit stored in the Flags Register affect the results of instructions that rely on comparisons between numbers, such as conditional jump instructions. The sign bit and overflow bit have no effect on the program/system at all and are used only as indicators to the operator.

The bit widths of the registers in the Abacus 1 differ:

Register | Bit Width
A | 16 bits
B | 16 bits
Instruction | 4 most significant bits
Memory Address | 12 least significant bits
Flags | 4 (least significant) bits

Note; most/least significant bits (MSB/LSB) refers to the significant figures of a binary integer. For example, the most significant bit in 1000 is 1.

### 2.5 Memory

The Abacus 1 minicomputer contains four kilowords (4,096 words) of random access memory. Each word is 16-bits in length. When instructions are stored in memory, the four most significant bits constitute the instruction and the remaining twelve bits form the address (if necessary). Values can also be stored in memory using the full 16-bits of data per address.

The memory can be read and written to directly with the use of the front panel memory address and memory data switches.

The Memory Address Register takes in the twelve least significant bits on the bus (the address) and relays the value to the (random access) memory module. This register cannot be accessed by the user at all.

The Program Counter is a special 12-bit register which stores the address of the next program step (memory address) to be executed. The Program Counter is automatically advanced to the next sequential program address upon completion of the “fetch phase” of the instruction cycle. The PC is directly writable via jump and conditional jump instructions but cannot be read from.

### 2.6 External Storage

The Abacus 1 has a 16-bit system-wide bus. This bus extends beyond the internal components and can be accessed via 16 external pins. The Abacus 1 is fitted with an optional “tape reader” module that can automate the process of loading programs. A punched tape reader, or any other functionally compatible device, can be plugged into the 16 external bus pins for use with the Tape module.

### 2.7 Instruction Decoding & Control Logic

The Instruction Register (explained in part 2.4 “Registers”) is connected to the bus. When the fetch phase of the instruction cycle commences, the IR reads the contents supplied by the memory and splits it into two sections; the instruction (4 MSB) and the address (12 LSB). It forwards the address (12 LSB) to where it needs to go and increments the Program Counter. All the while, the Instruction Decoder has taken in the instruction (4 MBS) and fed the value into the three EEPROMs that comprise its control logic. The logic activates certain control signals at specific times in the instruction cycle, allowing many unique and complex instructions to be performed depending on the input value.

### 2.8 Input & Output

The Abacus 1 can be interfaced with the on-board switches or using a “tape compatible” input device. Its output consists of a five-digit seven-segment display (with one additional digit for signifying negative integers). The display can be hexadecimal or signed or unsigned decimal. Additionally, myriad status indicator LEDs report the contents of every internal register in the system.

## Part 3 — Operation Details

Power Supply Page 6

temp

Front Panel Switches & Indicators Page 7

Temp

Settings & Modes of Operation Page 6

Clock Modes and Speed, Display Modes

Loading a Program Page 7

temp

Using the Memory Page 8

temp

Memory Addressing Page 9

temp

Operating Hints Page 9

temp

### 3.3 Settings & Modes of Operation

The clock has two operational modes; a-stable “pulse mode” and monostable “step mode”. Pulse mode is considered the normal operating mode, where the clock rhythmically pulses at its set speed. Step mode overrides the internal clock with a non-latching switch labelled Step on the front panel. When Step is pressed, the clock will go high until the switch is released. Note; a logical process is used when switching between modes to ensure the wire never floats.

The LED labelled Clock on the front panel indicates the computer’s current clock speed. The LED labelled Halt indicates whether the computer is halted… If so, the computer has finished executing the program in memory. When Halt is high, the clock will be stopped.

## Part 4 — Abacus 1 Instruction Set

Control Signals Page 12

Types of Instructions, Respective Control Signals, Control Timing

Control Instructions Page 13

Nop, Out, Hlt

Data Transfer Instructions Page 13

Lda, Ldi, Sta, Ldf

Accumulator Instructions Page 14

Add, Sub, Xor, And, Or, Not

Branching Instructions Page 14

Jmp, Jc, Jz

### 4.1 Control Signals

The Abacus 1 has 15 basic machine language instructions grouped into the following four categories:

- Command Instructions
- Data Transfer Instructions
- Accumulator Instructions
- Branching Instructions

Each instruction is performed over a maximum of five clock pulses through a series of signals sent to many different components of the system. Listed below are all the modules of the Abacus 1 and their control signals.

Module | Control Signals
Clock | Hlt
Program Counter | Ce, Co, J, Jc, Jz
Instruction Register | Ii, Io
Memory Address Register | Mi
(Random Access) Memory | Ri, Ro
Accumulator | Ai, Ao
Register B | Bi
Arithmetic Logic Unit | Eo, Su, Xr, An, Or, Nt
Flags Register | Fi, Fo

The special control signal Tr (time reset) is activated after an instruction has finished executing if it does not use all five “time” periods. It asynchronously resets the control logic counter back to “time one”, beginning the fetch phase of the next instruction cycle.

Listed below are all the instructions of the Abacus 1 and their active controls for every “time”. The first two “times” comprise the “fetch” component of the instruction (fetch-decode-execute) cycle.

Instruction | Active Controls
| T1 | T2 | T3 | T4 | T5
Nop | Mi, Co | Ro, Ii, Ce | Tr | – | –
Lda | Mi, Co | Ro, Ii, Ce | Io, Mi | Ro, Ai | Tr
Add | Mi, Co | Ro, Ii, Ce | Io, Mi | Ro, Bi | Eo, Ai, Fi
Sub | Mi, Co | Ro, Ii, Ce | Io, Mi | Ro, Bi | Eo, Ai, Su, Fi
Sta | Mi, Co | Ro, Ii, Ce | Io, Mi | Ao, Ri | Tr
Ldi | Mi, Co | Ro, Ii, Ce | Io, Ai | Tr | –
Jmp | Mi, Co | Ro, Ii, Ce | Io, J | Tr | –
Jc | Mi, Co | Ro, Ii, Ce | Io, Jc | Tr | –
Jz | Mi, Co | Ro, Ii, Ce | Io, Jz | Tr | –
Xor | Mi, Co | Ro, Ii, Ce | Io, Mi | Ro, Bi | Eo, Ai, Xr, Fi
And | Mi, Co | Ro, Ii, Ce | Io, Mi | Ro, Bi | Eo, Ai, An, Fi
Or | Mi, Co | Ro, Ii, Ce | Io, Mi | Ro, Bi | Eo, Ai, Or, Fi
Not | Mi, Co | Ro, Ii, Ce | Eo, Ai, Nt, Fi | Tr | –
Ldf | Mi, Co | Ro, Ii, Ce | Fo, Ai | Tr | –
Out | Mi, Co | Ro, Ii, Ce | Ao, Oi | Tr | –
Hlt | Mi, Co | Ro, Ii, Ce | Hlt | Tr | –

The physical paths and connections of the control signals can be observed in part 2.1 “Organisation” of this manual.

### 4.2 Control Instructions

Nop – no operation. Syntax: 0000. This instruction carries out the “fetch phase” of the instruction (fetch-decode-execute) cycle but nothing more. It simply increments the program counter, progressing to the next memory location.

Out – output accumulator. Syntax: 1110. This instruction takes the current value loaded in the accumulator and pushed it to the display module. The value will be displayed on the five-digit seven-segment display.

Hlt – halt clock. Syntax: 1111. This instruction signals the clock to stop pulsing, freezing the computer at “time five”—the Hlt instruction’s “execute phase”.

### 4.3 Data Transfer Instructions

Lda – load accumulator. Syntax: 0001 <Address>. This instruction takes the value stored at the specified address in memory and loads it into the accumulator. It does not affect the contents in memory.

Ldi – load immediate. Syntax: 0101 <Integer>. This instruction takes the value specified (which would normally be an address) and loads it into the accumulator. It cannot load values less than zero or greater than 4095 (0x000-0xfff). This is because it only has 12-bits to work with. It does not access the memory at any time.

Sta – store accumulator. Syntax: 0100 <Address>. This instruction takes the value loaded into the accumulator and stores it at the specified address in memory. It will overwrite any memory contents at the specified address.

Ldf – load flags. Syntax: 1101. This instruction takes the value stored at the special flags register and loads it into the accumulator. The contents can then be masked to make use of the system’s many flags. It does not affect the contents in memory.

### 4.4 Accumulator Instructions

Accumulator instructions will update the flags register. Note; they can cause overflow errors.

Add – arithmetical addition. Syntax: 0010 <Address>. This instruction takes the value stored at the specified address in memory and adds it to the current value loaded in the accumulator.

Sub – arithmetical subtraction. Syntax: 0011 <Address>. This instruction takes the value stored at the specified address in memory and subtracts it from the current value loaded in the accumulator. It works by adding the twos-compliment of a number.

Xor – logical exclusive or. Syntax: 1001 <Address>. This instruction takes the value stored at the specified address in memory and “exclusively ors” it with the current value loaded in the accumulator.

And – logical and. Syntax: 1010 <Address>. This instruction takes the value stored at the specified address in memory and “ands” it with the current value loaded in the accumulator.

Or – logical or. Syntax: 1011 <Address>. This instruction takes the value stored at the specified address in memory and “ors” it with the current value loaded in the accumulator.

Not – logical not. Syntax: 1100. This instruction “nots” the current value loaded in the accumulator. It does not require any additional parameters.

### 4.5 Branching Instructions

Jmp – unconditional jump. Syntax: 0110 <Address>. This instruction will overwrite the program counter’s value with the value stored at the specified address in memory.

Jc – jump on carry. Syntax: 0111 <Address>. This instruction will overwrite the program counter’s value with the value stored at the specified address in memory only when the carry bit is set.

Jz – jump on zero. Syntax: 1000 <Address>. This instruction will overwrite the program counter’s value with the value stored at the specified address in memory only when the zero bit is set.

An instruction reference card is included in appendix three “Supplementary Information” of this manual.

## Part 5 — Programming Guide

Fundamentals of Programming Page 16

Theory of Simulating Circuits, Methodical Approach to Programming

A Simple Program Page 17

Defining a Problem, Creating a Flow Diagram

Assembly Language Page 18

Purpose, Flow Diagram to Assembly Language, Representing Values

Machine Code Page 19

Assembly Language to Machine Code, Hexadecimal Representation

Debugging Page 20

Where Bugs Are Born, Tools to Use, Step-By-Step Process

Sample Programs Page 21

Fibonacci Sequence, Multiplication, Loop Counter, Floor Division with Modulo

Concept of Operating Systems Page 23

Purpose, Basic Application

### 5.1 Fundamentals of Programming

As has become apparent through the exploration of the Abacus 1 and its control logic, to be meaningfully applied, the computer must be programmed. Sets of digital instructions, called programs, routines, code or software, implement variations in hardware, altering the functionality of the computer. In programming a computer, the operator is effectively wiring an invisible circuit; and so long that the circuit does not change, the process which it carries out will not change. For example, imagine the programmed “circuit” is one that adds numbers; given this “circuit” or process remains the same, the outputs will always be the same for given inputs. Computers are a piece of variable hardware, that can be programmed to imitate a constant piece of hardware reliably.

The software instructions for the Abacus 1 must be inputted into the machine in the form of sequential 16-bit words known as machine language. Machine code will be discussed in part 5.3.

The basics of computer programming are quite simple. In fact, often the most difficult part of programming is defining the problem you with to solve with the computer. Below are listed the three main steps in generating a program.

1. Defining the problem.
2. Establishing an approach.
3. Writing the program.

Once the problem has been defined, an approach to its solution can be developed. This step is simplified by making a diagram which shows the orderly, step-by-step solution of the problem. Such a diagram is called a flow diagram. After a flow diagram has been made, the various steps can be translated into the computer's language. This is the easiest of the three steps since all you need is a general understanding of the instructions and a list showing each instruction and its machine language equivalent.

The Abacus 1 has a small instruction set with extensive capability. For example, a program can cause data to be transferred between the computer's memory and the registers. The program can even cause the computer to make logical decisions. For example, if a specified condition is met, the computer can jump from one place in the program to any other place and continue program execution at the new place.

The Abacus 1 instruction set was described in detail in part four of this manual.

### 5.2 A Simple Program

Assume you wish to use the Abacus 1 to add two numbers located at two different memory locations and store the result elsewhere in the memory. Of course, this is a very simple problem, but it can be used to illustrate several basic programming techniques. Here are the steps used in generating a program to solve this problem:

1. Define the problem—Add two numbers located in memory and store the result elsewhere in memory, then display the number and halt execution.
2. Establish an approach—A flow diagram can now be generated:

Add number from second memory location.

Retrieve number from first memory location.

Store result in a new memory location.

Output result and halt the computer.

3. Write the program—This step will be covered in the next part, part 5.3, after an explanation of assembly language.

Note; many flow diagrams can be created to compare the structure of different approaches to a problem.

### 5.3 Assembly Language

The software for any computer must be entered the machine in the form of binary words called machine language/code. Machine language programs are generally written with the help of mnemonics which correspond to the bit patterns for various instructions. For example, 0010 is an add instruction for the Abacus 1 and the corresponding mnemonic is Add. Obviously, the mnemonic Add is much more convenient to remember than its corresponding machine language bit pattern.

Ultimately, however, the machine language bit pattern for each instruction must be entered into the computer one step at a time.

We are now ready to translate the simple program from part 5.2 into assembly language. Translating the flow diagram into a language or format suitable for use by the computer may seem complicated at first. However, a general knowledge of the computer's organization and operation makes the job simple. In this case, the four-part flow diagram translates into five separate instructions:

Line | Instruction | Address
0 | Lda (load value into accumulator) | 5
1 | Add (add value to accumulator) | 6
2 | Sta (store accumulator to memory) | 7
3 | Out (output result to display) | null
4 | Hlt (halt/stop the computer) | null

Make note of the line numbering, the program begins at line zero. This is because each line of code represents an address in physical memory, which is indexed from zero.

As described in part four, many instructions have arguments that are required for the instruction to execute. For example, the Lda instruction on line zero looks up the value at memory address three and moves it into the accumulator. If the address space were to be empty, the instruction would attempt to load memory address zero into the accumulator, which happens to be itself—a value of 0001—not what we intended.

For this reason, we need to store our values/integers in the memory too. The following lines of this program could look like this.

Line | Instruction | Address
5 | 137 (the first number) 6200 (the second number) null (the result will go here)
6
7

The lines of a program that contain values should always be written in the final lines of the program, sequentially after the program is halted. Values stored in memory can take up the whole 16-bits of data at any address, so were these placed in the middle of a program, they could be interpreted as an instruction and cause errors in execution. Shared instruction and data memory is one limitation of the Von Neumann architecture.

### 5.4 Machine Code

To put it simply, “machine code” is ones and zeroes. The mnemonics of assembly language are directly interchangeable with the raw binary instructions of machine code. This makes “assembling programs” simple.

Assembled, the program from part 5.3 would be written like this:

Line | Instruction | Address
… 0000 | 0001 | 0000 0000 0101
… 0001 | 0010 | 0000 0000 0110
… 0010 | 0100 | 0000 0000 0111
… 0011 | 1110 | 0000 0000 0000
… 0100 | 1111 | 0000 0000 0000
… 0101 | 0000 | 0000 1000 1001
… 0110 | 0001 | 1000 0011 1000
… 0111 | 0000 | 0000 0000 0000

Make note of how binary representation of the decimal value 6200 flows into the instruction space.

The binary view of the program is not elegant nor space efficient. To neaten things up we can use hexadecimal notation to display this program; where in the contents the first digit represents the 4-bit instruction and the following three represent the 12-bit address.

Memory Address | Memory Contents
000 | 1 005 2 006 4 007 E 000 F 000 0 089 1 838 0 000
001
002
003
004
005
006
007

Congratulations, you’ve just written your first program for the Abacus 1 minicomputer! This code can be loaded into the memory of the computer and executed. Additionally, the code can be stored on paper or punch tape for storage outside of the volatile system memory for later recall/usage.

### 5.5 Debugging

Occasionally, the code loaded into the computer’s memory will not execute as expected. This is most likely the result of an error, called a “bug”, in the program. Rarely, this can be the result of a hardware failure; appendix one details the proper method of identifying and repairing faulty hardware. A bug often arises at three times in the process of programming a computer:

- When establishing an approach.
- When writing the program.
- When loading the program into memory.

There are a few things that will make debugging your code easier. These include:

- The program’s flow diagram.
- The program itself, written in assembly code.
- The instruction set reference, including all control signals (see part four).

The process of debugging can be both time consuming and infuriating; patience is essential. Rest assured, finally executing your program without error will be a very satisfying and rewarding experience. To successfully debug a program, follow these steps:

1. Switch the clock mode from Pulse to Step; this ensures that the computer will not run before we’re ready.
2. Load the program from scratch; sometimes a “buggy” program can alter its own code, further worsening the problem.
3. Reset the computer by pressing the Reset switch. Initialisation of the computer is done.
4. Look up the current instruction in your program and make note of the controls that it activates at each “time”. The clock should be at “time zero”, the first half of the “fetch phase”. It is safe to step the clock once, moving to “time one”, the second half of the “fetch phase”. If there are any erroneous controls at this point, there is an error in the computer’s microcode; see appendix 1.4 “Bad Microcode”.
5. Step the clock by one, progressing to “time two”. Check that the instruction in the Instruction Register is the same as the one in your program. If not, there is an error in translation from assembly language to machine code.
6. Compare the active controls to that of the instruction to check that there are no errors in the Microcode. If there are any erroneous controls at this point, there is an error in the computer’s microcode; see appendix 1.4 “Bad Microcode”.
7. Repeat steps five to six until at “time four”.
8. Compare the result of the instruction to the expected results described in your flow diagram and program (check register indicators). If there is a discrepancy, there may be an error in the usage of certain instructions, the implementation of code from the flow diagram, or simply a flow diagram that does not describe the process desired for execution.
9. Repeat steps four to eight until a bug is found. If the program is not to blame for the erroneous operation of the computer, there may be an error in the wiring of the computer’s circuitry; see appendix 1.3 “Bad Circuitry”.

### 5.6 Sample Programs

Note; “–” denotes a variable value that is supplied by the programmer at the time of assembly.

Fibonacci Sequence:

# | Assembly | Code | Comments

| Top:
0 | Ldi 0 | 7000 | Load 0 into accumulator (Acc).
1 | Sta X | 400D | Store Acc value in X variable.
2 | Out | E000 | Output Acc.
3 | Ldi 1 | 5001 | Load 1 into Acc.
| Next:
4 | Sta Y | 400E | Store Acc in Y variable.
5 | Out | E000 | Output Acc.
6 | Add X | 200D | Add Y to Acc.
7 | Jc Top | 7000 | If carry, start over (jump to “Top”).
8 | Sta Z | 400F | Store Acc in Z variable.
9 | Lda Y | 100E | Load Y into Acc.
10 | Sta X | 400D | Store Acc into X.
11 | Lda Z | 100F | Load Z into Acc.
12 | Jmp Next | 6004 | Jump to “Next”.
13 | X; 0 | 0000
14 | Y; 0 | 0000
15 | Z; 0 | 0000

Multiplication:

# | Assembly | Code | Comments

0 | Lda Y | 100E
1 | Sta Count | 4010 | Store multiplier (Y) as Count.
| Top:
2 | Lda Count | 1010
3 | Sub One | 300D | For every addition, decrement Count.
4 | Jc Next | 7008 | If Count > 0, go to addition.
5 | Lda Result | 1011
6 | Out | E000 | Output result.
7 | Hlt | F000
| Next:
8 | Sta Count | 4010 | Store decremented Count value.
9 | Lda Result | 1011 | Load previous sum.
10 | Add X | 200F | Add multiplicand.
11 | Sta Result | 4011 | Store sum as Result.
12 | Jmp Top | 6002 | Do it all again.
13 | One; 1 | 0001
14 | X; – | – | Multiplicand variable.
15 | Y; – | – | Multiplier variable.
16 | Count; 0 | 0000
17 | Result; 0 | 0000 | Product value.

### 5.6 Sample Programs (continued)

Loop Counter:

# | Assembly | Code | Comments

| Top:
0 | Add Inc | 2003 | Increment by “inc” value.
1 | Out | E000 | Display number.
2 | Jmp Top | 6000 | Do it again.
3 | Inc; 1 | 0001 | Value to increment by.

Floor Division with Modulo:

# | Assembly | Code | Comments

| Top:
0 | Ldi 0 | 7000
1 | Or Num | A012
2 | Sta Res | 4016 | Res = Num.
3 | Jz Result | 800E | If Num == 0, skip division.
4 | Ldi 1 | 5001
5 | Add Cnt | 2014 | Increment Cnt.
6 | Sta Cnt | 4014
7 | Lda Res | 1016
8 | Sub Den | 3013
9 | Jc Modulo | 700C | If Num < Den, store Mod and output Cnt.
10 | Sta Res | 4016 | Store current value as Res.
11 | Jmp Top | 6000 | Do it again.
| Modulo:
12 | Sta Mod | 4015 | Mod = Res.
13 | Nop | 0000 | Optionally output modulo.
| Result:
14 | Lda Cnt | 1014
15 | Sta Res | 4016 | Res = Cnt.
16 | Out | E000 | Output result.
| End:
17 | Hlt | F000 | End of program.
18 | Num; – | – | Numerator/Dividend variable.
19 | Den; – | – | Denominator/Divisor variable.
20 | Cnt; 0 | 0000
21 | Mod; 0 | 0000 | Modulus value.
22 | Res; 0 | 0000 | Quotient value.

### 5.7 Concept of Operating Systems

Traditionally, a program is loaded into a computer’s memory and is executed until completed, at which point the computer halts. Only one program can be loaded into a computer at once and the computer must be reprogrammed before each use. Operating systems can be used in computers to elevate this limitation, allowing the user to select from hundreds of programs which have all been loaded into memory at once.

The simplest form of an operating system is a small program located at the beginning of the system’s memory which, referencing a user-defined value, can jump to the location of and execute many other programs. This can be represented in a flow diagram:

Retrieve number of program to jump to.

Is number zero?

Is number one?

Is number two?

Jump to and execute first program.

Jump to and execute second program.

Jump to and execute third program.

## Appendix 1 — Maintenance Information

Hardware Vulnerabilities Page 25

Hardware Vulnerabilities, Maintenance Advice, Bad Circuitry, Bad Microcode, Parts List

Maintenance Advice Page 25

Hardware

Bad Circuitry Page 25

Hardware

Bad Microcode Page 25

Hardware

## Appendix 2 — Technical Information

Instruction Reference Card Page 35

Instruction Set Listing

Parts List Page 25

Hardware

System Schematics Page 36

Redacted

Data Sheets Page 37

74LS161, 74LS189, 28C16, 74LS382

## Appendix 3 — Supplementary Information

Boolean Algebra (Logic) Page 25

History, Logical Operations, Binary States, Truth Tables

Electronic Logic Page 28

Logic Gates, Layers

Number Systems & Binary Page 30

Overview, The Binary System, Conversion

Storing Negative Numbers Page 34

Two’s Compliment

Jules Carboni, Nov 20XX First Edition, Page 1

Jules Carboni, Nov 2018 First Edition, Page 1

Carbon 1 Technical Reference

ABACUS 1 Operators Manual

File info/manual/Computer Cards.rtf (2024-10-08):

Internal Cards (CPU)
1. Data Registers, State Registers
2. Memory (Random Access & Stack), Memory Management Unit
3. Arithmetic Logic Unit
4. Interrupt Controller, DMA Controller
5. Instruction Decoder, Control Logic
Maybe more cards to be added to this list.

External Cards (Expansion)
1. Interval Timer/Watchdog Timer/Real-Time Clock
2. Keyboard Controller, Mouse Controller
3. Composite Video Graphics Adapter
4. FM Synthesizer/Programmable Sound Generator
5. Dual Serial Ports, Dual Parallel Ports
6. Network Interface Adapter
7. Floppy-Disk Controller, Hard-Disk Controller
8. Mathematics Coprocessor
9. Graphics Coprocessor
10. Cassette Deck Controller, Paper Tape Punch Controller
11. Thermal Printer Controller, Game Controller Ports, GPIO Pins, Hexadecimal Display, PC Speaker/Buzzer

Proposed Combinations
1. CPU Combination Card 1
2. CPU Combination Card 2
3. Interval Timer/Watchdog Timer/Real-Time Clock, PC Speaker/Buzzer, Hexadecimal Display, Network Interface Adapter, Thermal Printer Controller
4. Composite Video Graphics Adapter, FM Synthesizer/Programmable Sound Generator
5. Dual Serial Ports, Dual Parallel Ports, Game Controller Ports, GPIO Pins, Keyboard Controller, Mouse Controller
6. Floppy-Disk Controller, Hard-Disk Controller, Cassette Deck Controller, Paper Tape Punch Controller

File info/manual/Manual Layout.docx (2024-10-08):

- Quick references (like a cut-out instruction listing)
- Getting started guide leaflet (tells you what to do, what to read, and in what order)
- Legal, copyright, and publication information
- Floppy disks containing Monitor, DOS, BASIC, etc

Introductory/Setup Guide

- How to use the machine (set up process, buttons, tour, etc...)
- How to install expansion cards
- How to connect a terminal/keyboard/monitor
- How to use the built-in loaders to load a monitor/OS from tape/disk
- Index

Programming Guide

- Instruction listing (only the relevant info, brief descriptions, nothing technical)
- How to approach writing programs
- How to write programs
- How to key in programs
- Via the front panel switches
- Via the monitor/DOS/BASIC with terminal/keyboard
- How to debug programs (link to debugging hardware)
- How to program for/with expansion cards
- Overview of the purpose each card has, what they do
- What each card outputs, what output they’ll give, what interrupts they’ll raise
- What registers they have, what address space they occupy, how they’ll respond to input
- An example of how to interface with each card (assembly code example for each function the card has)
- Index

Technical Reference

- Architecture and microarchitecture (logical organization with arch. diagram)
- Physical organization of components (with diagram of the system and where each card is)
- More detail about instruction set (detailed descriptions, side effects, flags changed, operands accepted, cycle counts to execute, times to execute at clock speeds, control signals activated at each time)
- Timing diagrams (clocks, read/write windows, etc)
- Voltage levels and other electrical data
- How to troubleshoot/repair hardware faults
- Schematics
- Part Lists
- Index

BASIC User Guide, Monitor Guide, DOS User Guide

- How to use each environment (commands, etc)
- How to code in the enviroment/language (how to write, assemble/link, and run)
- File management (how to save/load programs from tape/disk)
- What built in system calls the environment has (I/O handlers, display graphics/print funcs, etc)
- Index

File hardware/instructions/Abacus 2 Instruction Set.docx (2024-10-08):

Abacus 2 Instruction Set

DATA INSTRUCTIONS

MOV Move

LDRF Load Flags

STRF Save Flags

XCHG Exchange

PUSH Push to Stack

PUSHF Push Flags to Stack

POP Pop from Stack

POPF Pop Stack to Flags

IN Input from Port

OUT Output to Port

LEA Load Effective Address

CBW Convert Byte to Word

ARITHMETIC INSTRUCTIONS

ADD Add

ADC Add with Carry

SUB Subtract

SBB Subtract with Borrow

INC Increment

DEC Decrement

NEG Negate

CMP Compare (Subtract)

LOGIC INSTRUCTIONS

AND And

OR Or

XOR Exclusive Or

NOT Not

TEST Test (And)

SHIFT INSTRUCTIONS

SHL Shift Left

BRANCHING INSTRUCTIONS

JMP Jump Unconditionally

JO Jump if Overflow

JS Jump if Sign

JZ Jump if Zero

JNZ Jump if not Zero

JC Jump if Carry

JNC Jump if not Carry

JP Jump Parity

FUNCTION INSTRUCTIONS

CALL Call Function

RET Return Function

INT Call Interrupt

IRET Return Interrupt

BRK Call Breakpoint

SPECIAL INSTRUCTIONS

CPUID Processor Identification

NOP No Operation

HLT Halt Processor

WAIT Wait for Interrupt

CLF Clear Flag

STF Set Flag

CMF Complement Flag

FPU INSTRUCTIONS

FNOP No Operation

FIXS Convert Floating Point to Fixed Single

FIXD Convert Floating Point to Fixed Double

FLTS Convert Fixed Single to Floating Point

FLTD Convert Fixed Double to Floating Point

CHSS Change Sign Fixed Single

CHSD Change Sign Fixed Double

CHSF Change Sign Floating Point

XCHS Exchange TOS/NOS Fixed Single

XCHD Exchange TOS/NOS Fixed Double

XCHF Exchange TOS/NOS Floating Point

POPS Pop Fixed Single from Stack

POPD Pop Fixed Double from Stack

POPF Pop Floating Point from Stack

PTOS Push Fixed Single to Stack

PTOD Push Fixed Double to Stack

PTOF Push Floating Point to Stack

PUPI Push Pi to Stack

SADD Add Fixed Single

SSUB Subtract Fixed Single

SMUL Multiply Fixed Single (Lower)

SMUU Multiply Fixed Single (Upper)

SDIV Divide Fixed Single

DADD Add Fixed Double

DSUB Subtract Fixed Double

DMUL Multiply Fixed Double (Lower)

DMUU Multiply Fixed Double (Upper)

DDIV Divide Fixed Double

FADD Add Floating Point

FSUB Subtract Floating Point

FMUL Multiply Floating Point

FDIV Divide Floating Point

SIN Sine

COS Cosine

TAN Tangent

ASIN Inverse Sine

ACOS Inverse Cosine

ATAN Inverse Tangent

SQRT Square Root

LOG Common Logarithm

LN Natural Logarithm

EXP Exponent (Euler)

PWR Exponent (X^Y)

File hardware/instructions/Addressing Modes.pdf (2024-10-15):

R/M \\ Mod | 00 | 01 | 10 | 11
000 | [AX] | [AX + Disp8] | [AX + Disp16] | Reg AL/AX
001 | [BX] | [BX + Disp8] | [BX + Disp16] | Reg BL/BX | Mod | R/M | Reg
010 | [CX] | [CX + Disp8] | [CX + Disp16] | Reg CL/CX | 2 b | 3 b | 3 b
011 | [DX] | [DX + Disp8] | [DX + Disp16] | Reg DL/DX
100 | [EX] | [EX + Disp8] | [EX + Disp16] | Reg AH/EX | Mod
101 | [FX] | [FX + Disp8] | [FX + Disp16] | Reg BH/FX | 00
110 | [SP] | [SP + Disp8] | [SP + Disp16] | Reg CH/SP | 01
111 | [BP] | [BP + Disp8] | [BP + Disp16] | Reg DH/BP | 10
| [Reg16] | [Reg16 + Disp8] | [Reg16 + Disp16] | Reg8/Reg16 | 11
XXX | [Disp16] | Imm8 | Imm16 | [Disp8]
| [Reg8] | Load from zero page (addr in reg8)
| [Disp8] | Load from zero page (addr in imm8)
| [Disp16] | Load from anywhere (addr in imm16)
| Imm8 | Load immediate from imm8
| Imm16 | Load immediate from imm16
Address | 8 Bit Op. | 16 Bit Op. | | | Use
000 | AL | AX | AH | AL | GP, Arguments, Returns
001 | BL | BX | BH | BL | GP, Arguments
010 | CL | CX | CH | CL | GP, Counters
011 | DL | DX | DH | DL | GP
100 | AH | EX* | | | GP
101 | BH | FX* | | | GP, Relative data offset for PIC?
110 | CH | SP** | | | Stack
111 | DH | BP** | | | Stack
Byte 1 | Byte 2 | Byte 3 | Byte 4 | Byte 5 | Byte 6 | Byte 7
Opcode + Mod | | D/W R/M | | | Immediate Displacement
Byte 1 | Byte 2 | Byte 3 | Byte 4 | Byte 5 | Byte 6 | Byte 7 | Byte 8
Instruction / Opcode | | Mod R/M | SIB | Displacement | | Immediate
Opcode | Size | Direction | Mod | Reg | R/M | Scale | Index | Base

Reg defines the src or dst register. Mod & R/M define the other src or dst register/memory location.

Instruction / Opcode (Bits)
Any Opcode | Size | Direction
Byte 1 | Byte 2 | Byte 3

Instruction / Opcode (Bits)
Any Opcode | Mod
Byte 1 | Byte 2
Opcode | Mod | Size + Direction | R/M | Reg

SP
BP

Register

*16 bit only register.
**Stack pointers.

EX
FX

Meaning

Register direct.

Register indirect with 16bit displacement.

Register indirect with 8bit displacement.

Register indirect.

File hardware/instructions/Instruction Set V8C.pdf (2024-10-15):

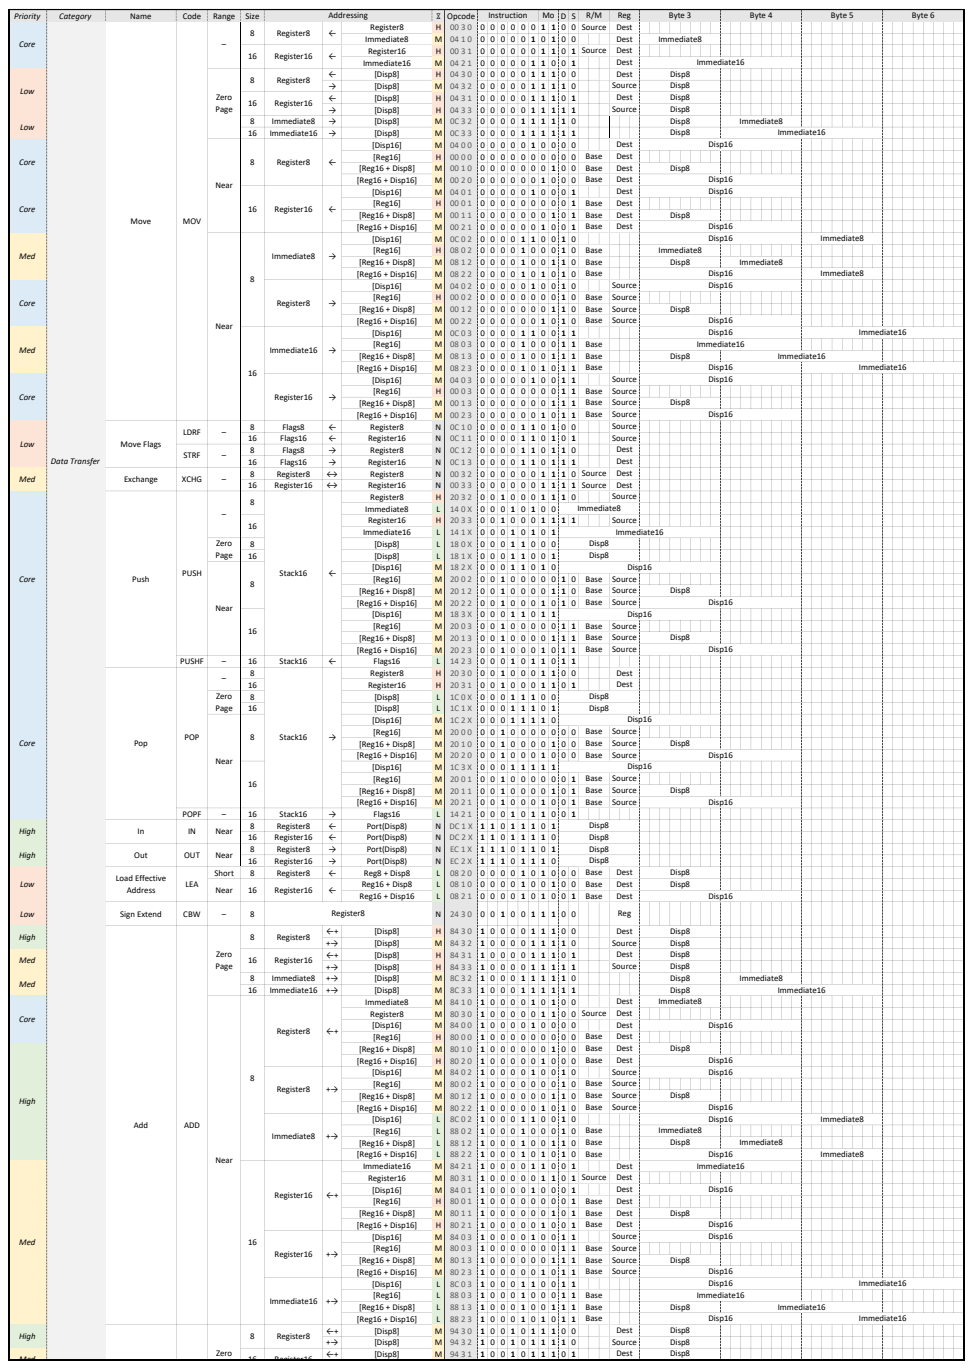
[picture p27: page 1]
Priority; Category; Name; Code Range Size; ⧖ Opcode; Register8; Immediate8; Register16; Immediate16; [Disp8]; 16 Immediate16 →; [Disp16]; [Reg16]; [Reg16 + Disp8]; [Reg16 + Disp16]; Flags8; Flags16; PUSHF; Stack16; POPF; Port(Disp8); Short; Reg8 + Disp8; Reg16 + Disp8; Reg16 + Disp16; Low; Sign Extend; CBW; Immediate8 +→; 16 Immediate16 +→; Dest; Byte 4; Byte 5; Byte 6; Core; Data Transfer; Move; MOV; 8 Register8; Addressing; Instruction; Reg; Byte 3; Disp8; Source; Base; Near; Disp16; Med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

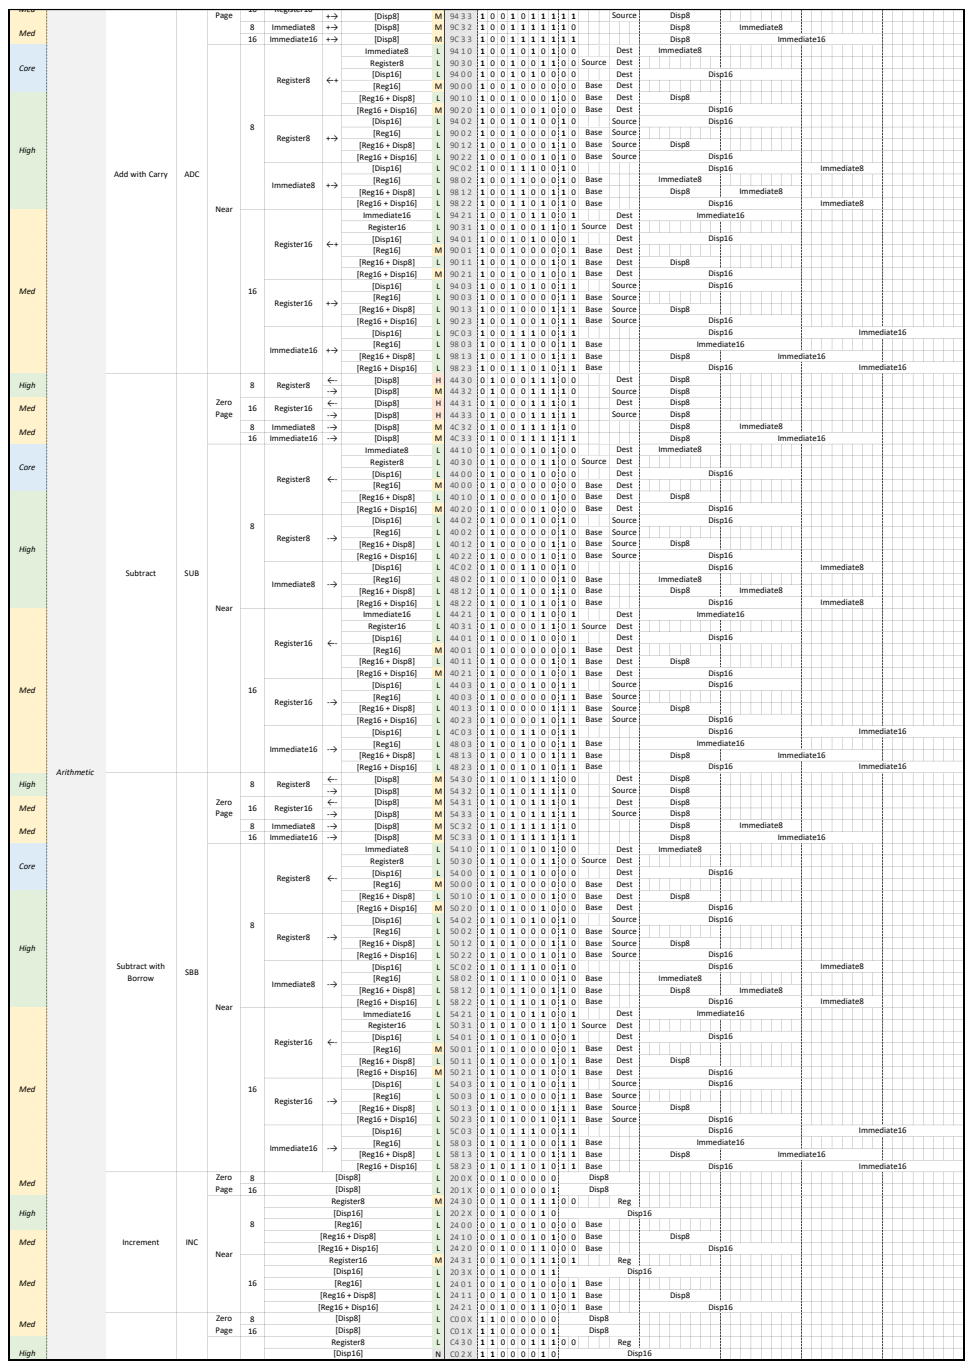
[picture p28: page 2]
[Disp8]; Immediate8 +→; 16 Immediate16 +→; Immediate8; Register8; [Disp16]; [Reg16]; [Reg16 + Disp8]; [Reg16 + Disp16]; Immediate16; Register16; Immediate8 -→; 16 Immediate16 -→; Arithmetic; Dest; Disp16; Base; Source; Disp8; Med; Add with Carry; ADC; Page; High; Core; Near; Subtract; SUB; Zero Page; 8 Register8; Immediate16 +→; Immediate16 -→; Subtract with Borrow; SBB; Source Dest; Base Source; Base Source Base; Increment; INC; Reg; Zero

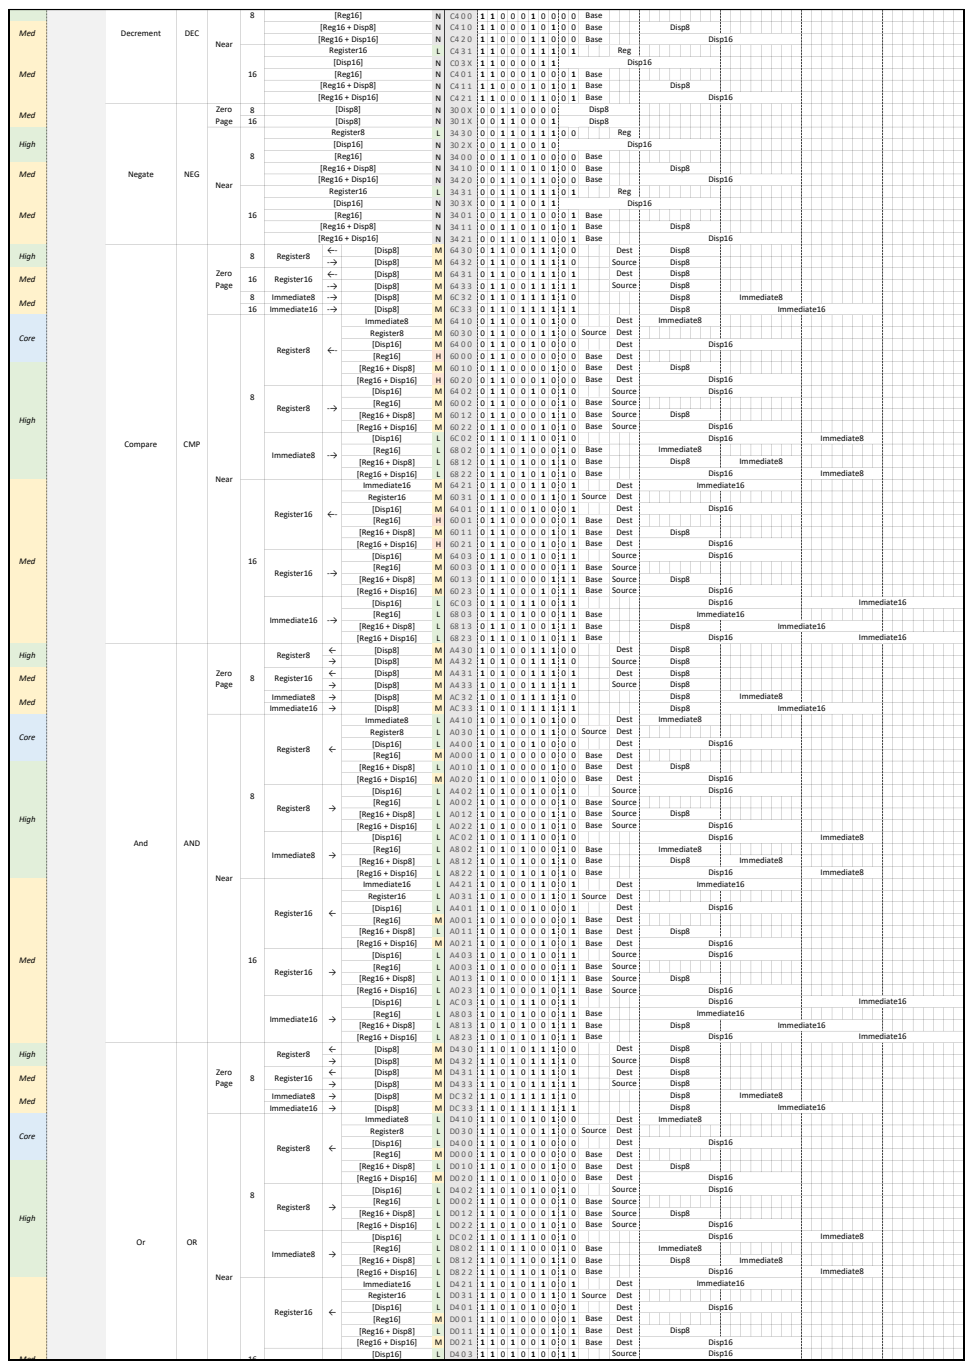
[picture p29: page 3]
[Disp8]; Immediate8 -→; 16 Immediate16 -→; Immediate8; Register8; [Disp16]; [Reg16]; [Reg16 + Disp8]; [Reg16 + Disp16]; Immediate16; Register16; Immediate16 →; Decrement; DEC; Base; Med; Disp8; Disp16; Near; Negate; NEG; Zero Page; Reg; High; Dest; Source; Compare; CMP; 8 Register8; Core; Immediate16 -→; Base Source; And; AND; Base Source Base; Source Dest

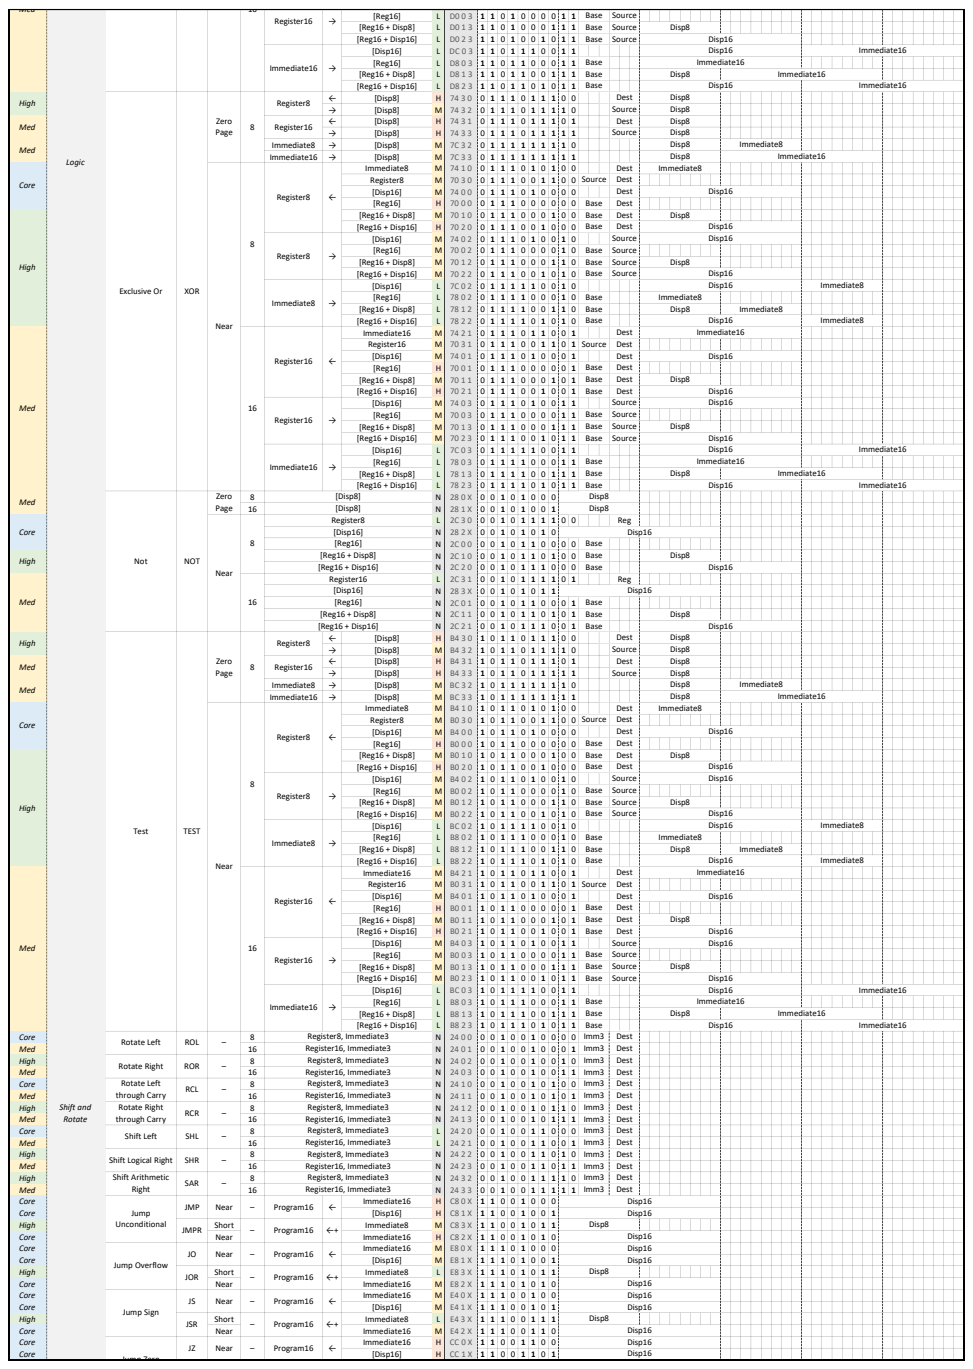
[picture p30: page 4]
[Reg16]; [Reg16 + Disp8]; [Reg16 + Disp16]; [Disp16]; [Disp8]; Immediate8; Immediate16; Register8; Register16; Immediate16 →; Core; Med; High; Short; Near; Logic; Base; Source; Exclusive Or; XOR; Zero Page; Dest; Disp8; Disp16; Not; NOT; Reg; Test; TEST; Source Dest; Base Source; Source Dest Dest; Base Source Base; Shift and Rotate; Rotate Left; ROL; Register8, Immediate3; Imm3 Dest; Register16, Immediate3; through Carry; RCL; Imm3; Rotate Right; ROR; Shift Left; SHL; RCR; Shift Arithmetic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

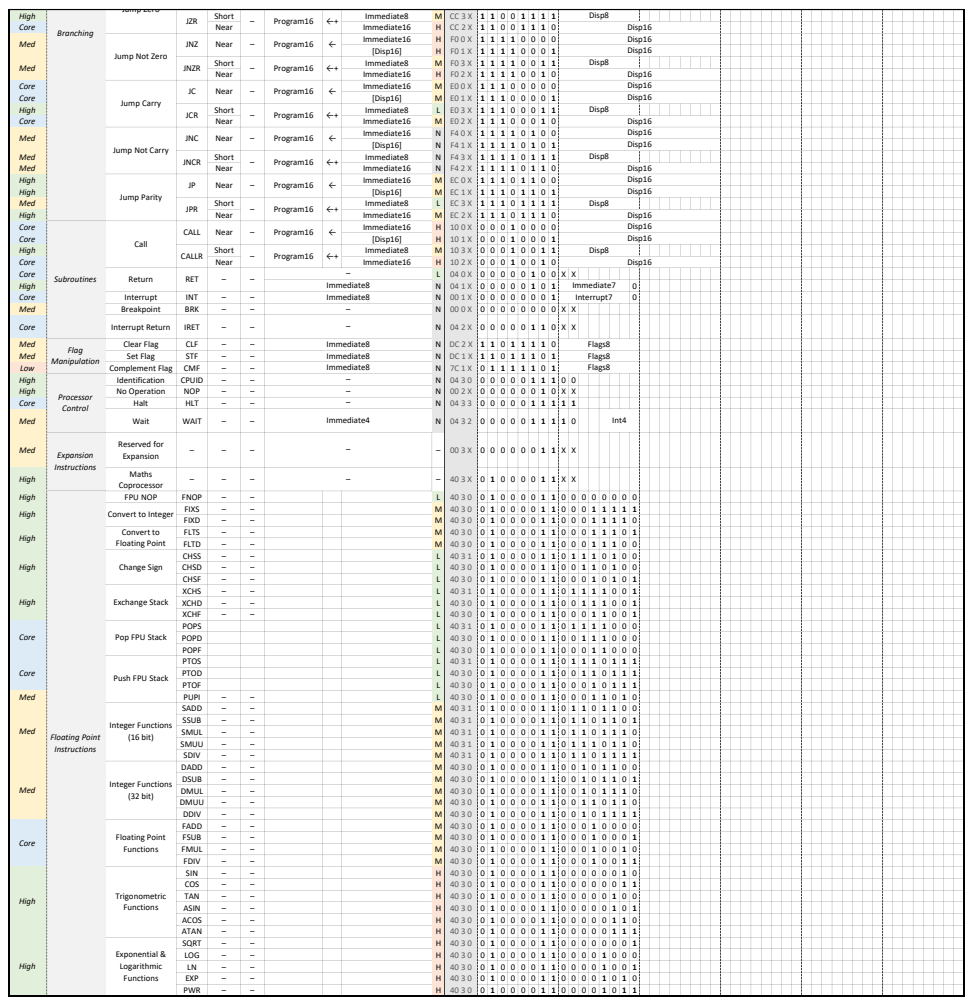
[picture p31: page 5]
High; Short; Immediate8; Core; Near; Immediate16; [Disp16]; Med; Interrupt; INT; Breakpoint; BRK; Interrupt Return; IRET; Clear Flag; CLF; Set Flag; STF; Low; Complement Flag CMF; Identification; CPUID; No Operation; NOP; Halt; HLT; Wait; WAIT; Reserved for; Expansion; Maths; Coprocessor; FPU NOP; FNOP; FIXS; FIXD; FLTS; FLTD; CHSS; CHSD; CHSF; XCHS; XCHD; XCHF; POPS; POPD; POPF; PTOS; PTOD; PTOF; PUPI; SADD; SSUB; SMUL; SMUU; SDIV; DADD; DSUB; DMUL; DMUU; DDIV; FADD; FSUB; FMUL; FDIV; SIN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

Jump Not Zero

Jump Not Carry

Convert to Integer
Convert to
Floating Point

Pop FPU Stack

Push FPU Stack

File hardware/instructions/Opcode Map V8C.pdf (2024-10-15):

Ver 8C | 00 00 00 01 00 10 00 11 01 00 01 01 01 10 01 11 | 10 00 10 01 10 10 10 11 | 11 00 11 01 11 10 11 11
00 | Breakpoint | Interrupt | No Operation | Reserved for Expansion
Return | Interrupt Return
04 | CPU ID | Wait | Halt
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
2C | Sign Extend
30

### 34 Move 38 LEA

3C
40 | Pop Flags | Push Flags
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
### 64 Add

68
6C
70

### 74 Add Carry

78
7C
80

### 84 Subtract

88
8C
90
94 Sub Borr.
98
9C
A0
A4 | Compare
A8
AC
B0
B4
B8
BC
C0
C4 | Test
C8
CC
D0
D4 | And
D8
DC
E0
E4 | Or
E8
EC
F0
F4 | Xor
F8
FC
43 00 43 04 43 08 43 0C 43 10 43 14 43 18 43 1C 43 20 43 24 43 28 43 2C 43 30 43 34 43 38 43 3C … 43 68 43 6C 43 70 43 74 43 78 43 7C … 43 FC | FNOP | SQRT | SIN | COS
| TAN | ASIN | ACOS | ATAN
| LOG | LN | EXP | PWR
CHSS | SMUU | PTOS
POPS | XCHS
POPD | XCHD
SADD | SSUB | SMUL | SDIV
DADD | DSUB | DMUL | DDIV
CHSD | | DMUU | PTOD
| CHSF | | PTOF
POPF | XCHF | PUPI
FLTD | FLTS | FIXD | FIXS
FADD | FSUB | FMUL | FDIV

Exclusive Or

Exclusive Or | Exclusive Or
Set Flag | Clear Flag | Exclusive Or

Or

Or | Or
Out | Or

Exclusive Or

Exclusive Or
| Exclusive Or

And

And | And
In | And

Or

Or
| Or

Test

Test | Test
Test

And

And
| And

Not
Not | Not | Not | Not

Test

Test
Test

Compare

Compare | Compare
Compare
Negate
Negate | Negate | Negate | Negate

Sub Borrow

Sub Borrow | Sub Borrow
Sub Borrow

Compare

Compare
| Compare

Subtract

Subtract | Subtract
Subtract

Sub Borrow

Sub Borrow
Sub Borrow

Add Carry

Add Carry | Add Carry
Add Carry

Subtract

Subtract
Subtract

Add

Add | Add
Add

Add Carry

Add Carry
Add Carry

Decrement
Decrement | Decrement | Decrement | Decrement

Add

| | Add
Add
Pop | Push
Increment
Increment | Increment | Increment | Increment

Push
Push
Pop
Pop | Push | Pop | Push | Pop | Push
| Move | | Move | LEA | Move
Move Flags | | Move
| Maths Coprocessor

Jump Overflow
Jump Not Zero
Jump Not Carry
| Shift Left
Move | Exchange
Move
Move

Function Call
Jump Unconditional
Jump Zero
Jump Zero
Jump Sign
Jump Overflow

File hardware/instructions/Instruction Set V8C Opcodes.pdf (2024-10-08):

Ver 8C | 00 00 00 01 00 10 00 11 01 00 01 01 01 10 01 11 | 10 00 10 01 10 10 10 11 | 11 00 11 01 11 10 11 11
00 | Breakpoint | Interrupt | No Operation | Reserved for Expansion
Return | Interrupt Return
04 | CPU ID | Wait | Halt
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
2C | Sign Extend
30

### 34 Move 38 LEA

3C
40 | Pop Flags | Push Flags
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
### 64 Add

68
6C
70

### 74 Add Carry

78
7C
80

### 84 Subtract

88
8C
90
94 Sub Borr.
98
9C
A0
A4 | Compare
A8
AC
B0
B4
B8
BC
C0
C4 | Test
C8
CC
D0
D4 | And
D8
DC
E0
E4 | Or
E8
EC
F0
F4 | Xor
F8
FC

Exclusive Or

Exclusive Or | Exclusive Or
Set Flag | Clear Flag | Exclusive Or

Or

Or | Or
Out | Or

Exclusive Or

Exclusive Or
| Exclusive Or

And

And | And
In | And

Or

Or
| Or

Test

Test | Test
Test

And

And
| And

Not
Not | Not | Not | Not

Test

Test
Test

Compare

Compare | Compare
Compare
Negate
Negate | Negate | Negate | Negate

Sub Borrow

Sub Borrow | Sub Borrow
Sub Borrow

Compare

Compare
| Compare

Subtract

Subtract | Subtract
Subtract

Sub Borrow

Sub Borrow
Sub Borrow

Add Carry

Add Carry | Add Carry
Add Carry

Subtract

Subtract
Subtract

Add

Add | Add
Add

Add Carry

Add Carry
Add Carry

Decrement
Decrement | Decrement | Decrement | Decrement

Add

| | Add
Add
Pop | Push
Increment
Increment | Increment | Increment | Increment

Pop
Pop | Push | Pop | Push | Pop | Push

Push

Push

Move
Move

Move

Move | LEA | Move
Move Flags | Move
Maths Coprocessor

Jump Overflow
Jump Not Zero
Jump Not Carry
| Shift Left
Move | Exchange

Function Call
Jump Unconditional
Jump Zero
Jump Zero
Jump Sign
Jump Overflow

43 00
43 04
43 08
43 0C
43 10
43 14
43 18
43 1C
43 20
43 24
43 28
43 2C
43 30
43 34
43 38
43 3C
43 40
43 44
43 48
43 4C
43 50
43 54
43 58
43 5C
43 60
43 64
43 68
43 6C
43 70
43 74
43 78
43 7C
43 80
43 84
43 88
43 8C
43 90
43 94
43 98
43 9C

### 43 A0 43 A4 43 A8 43 AC 43 B0 43 B4 43 B8 43 BC 43 C0 43 C4 43 C8 43 CC 43 D0 43 D4 43 D8 43 DC 43 E0 43 E4 43 E8 43 EC 43 F0 43 F4 43 F8 43 FC

FNOP | SQRT | SIN | COS
TAN | ASIN | ACOS | ATAN
LOG | LN | EXP | PWR

CHSS

CHSD

| CHSF | | PTOF
POPF | XCHF | PUPI
FLTD | FLTS | FIXD | FIXS

PTOD

PTOS

SDIV

DDIV

FADD | FSUB | FMUL | FDIV

POPS

POPD

SMUU

DMUU

SADD | SSUB | SMUL
DADD | DSUB | DMUL

XCHS

XCHD

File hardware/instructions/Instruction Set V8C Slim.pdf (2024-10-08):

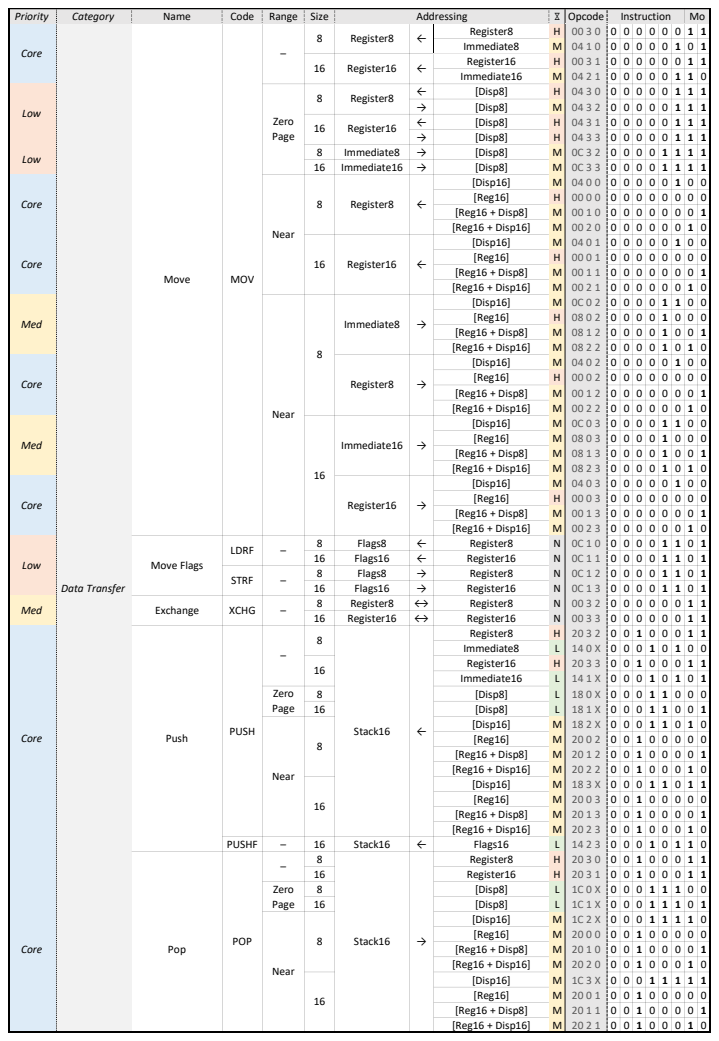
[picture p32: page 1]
Immediate8; Register16; Immediate16; [Disp8]; Immediate8 →; 16 Immediate16 →; [Disp16]; [Reg16]; [Reg16 + Disp8]; [Reg16 + Disp16]; Flags8; Register8; Flags16; PUSHF; Stack16; Core; Pop; POP; Zero Page; Near; Push; PUSH; Med; Exchange; XCHG; STRF; Low; Move Flags; LDRF; Immediate16 →; 8 Register8; Data Transfer; Move; MOV

Priority Category Name Code Range Size Addressing ⧖ Opcode Instruction | Mo

Register8 | H | 00 3 0 | 0 0 0 0 0 0 1 1

Core

Low

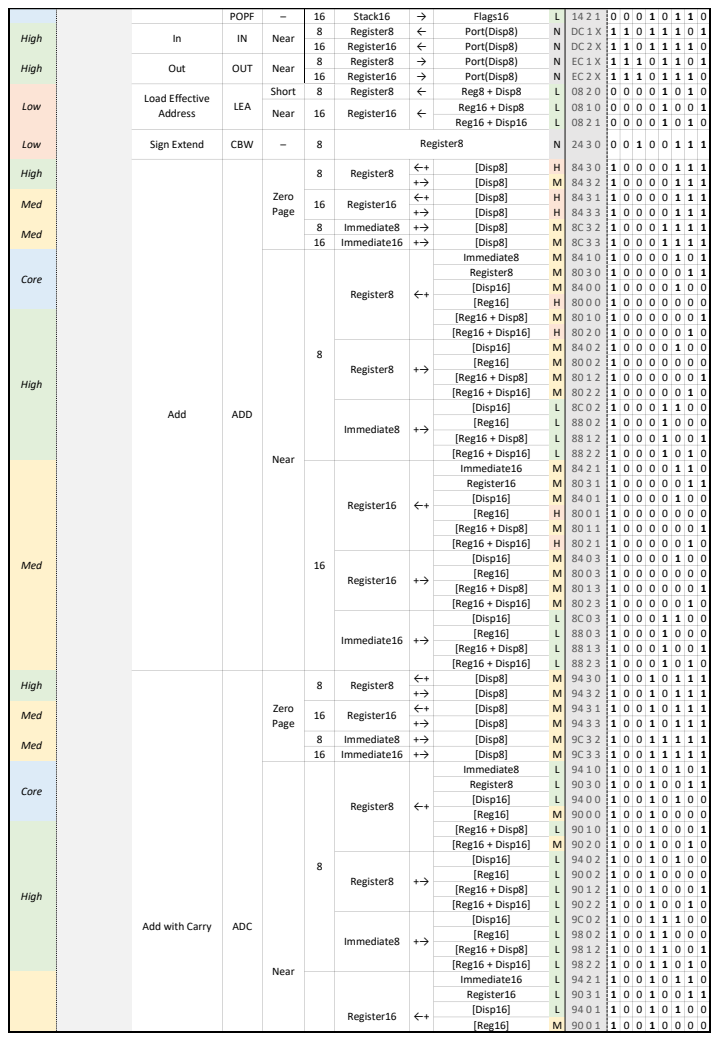
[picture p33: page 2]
Low; Sign Extend; CBW; [Disp8]; 8 Immediate8; 16 Immediate16; Immediate8; Register8; [Disp16]; [Reg16]; [Reg16 + Disp8]; [Reg16 + Disp16]; Immediate16; Register16; Immediate16 Register16 [Disp16] [Reg16]; Near; Immediate8 +; Med; Add with Carry; ADC; Zero Page; 8 Register8; Immediate16 +; Add; ADD

POPF – | 16 | Stack16 → Flags16 | L 14 2 1 | 0 1

High | In IN Near | 8 Register8 | ← Port(Disp8) | N DC 1 X N DC 2 X N EC 1 X N EC 2 X

16 Register16 | ← Port(Disp8)

Out OUT Near | 8 Register8 | → Port(Disp8)

16 Register16 | → Port(Disp8) | | 1 1 1 0

Low | Short 8 Register8 ← Reg8 + Disp8 Load Effective Address LEA Reg16 + Disp8 Near 16 Register16 ← Reg16 + Disp16 | | | L 08 2 0 L 08 1 0 L 08 2 1 | 0 0 0 0 1 0 1 0

High | H 84 3 0

M 84 3 2
H 84 3 1 H 84 3 3

Med | M 8C 3 2 M 8C 3 3

Core | M 84 1 0 M 80 3 0 M 84 0 0

H 80 0 0
M 80 1 0
H 80 2 0

High | M 84 0 2 M 80 0 2 M 80 1 2 M 80 2 2

H 80 0 1
M 80 1 1
H 80 2 1
M 84 0 3 M 80 0 3 M 80 1 3 M 80 2 3

High | M 94 3 0 M 94 3 2

Med | M 94 3 1 M 94 3 3 M 9C 3 2 M 9C 3 3

Core | L 94 1 0 L 90 3 0 L 94 0 0

M 90 0 0
L 90 1 0
M 90 2 0

High | L 94 0 2 L 90 0 2 L 90 1 2 L 90 2 2 L 9C 0 2 L 98 0 2 L 98 1 2 L 98 2 2

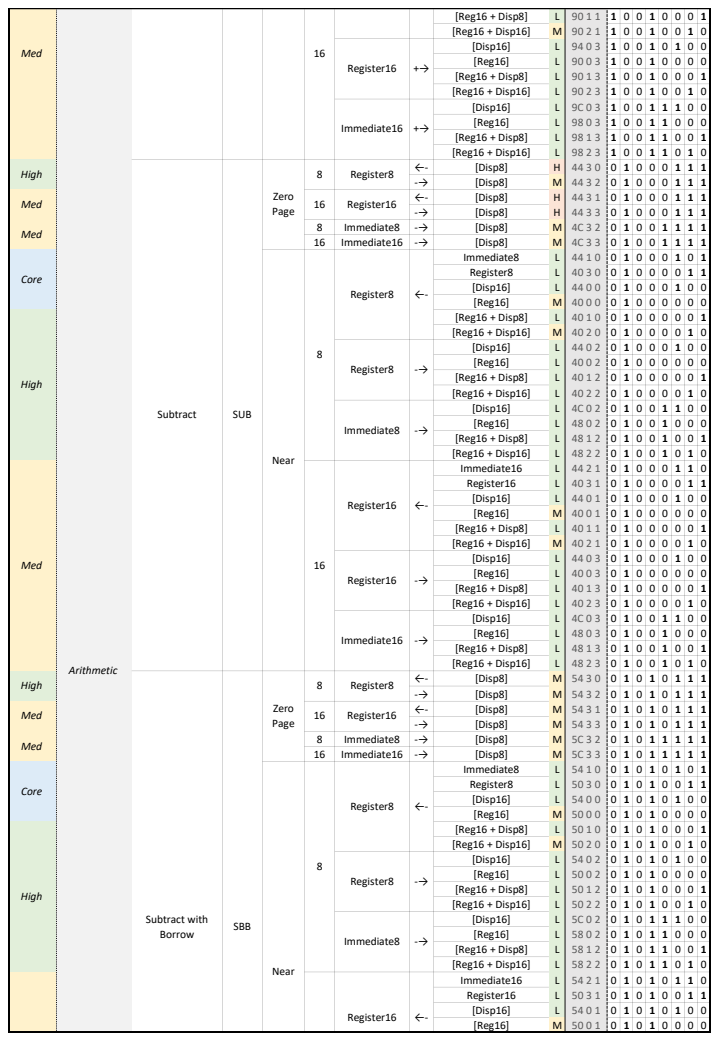
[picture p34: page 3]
[Reg16 + Disp8] [Reg16 + Disp16]; [Reg16 + Disp8]; [Reg16 + Disp16]; [Disp16]; [Reg16]; [Disp8]; 8 Immediate8; 16 Immediate16; Immediate8; Register8; Immediate16; Register16; Near; Immediate8 -; Med; Subtract with Borrow; SBB; Zero Page; 8 Register8; Immediate16 -; Immediate16 +; Subtract; SUB

L 90 1 1
M 90 2 1
L 94 0 3 L 90 0 3 L 90 1 3 L 90 2 3 L 9C 0 3 L 98 0 3 L 98 1 3 L 98 2 3

High | | H 44 3 0

M 44 3 2
H 44 3 1 H 44 3 3

Med | | M 4C 3 2 M 4C 3 3

Core | | L 44 1 0 L 40 3 0 L 44 0 0

M 40 0 0
L 40 1 0
M 40 2 0

High | | L 44 0 2 L 40 0 2 L 40 1 2 L 40 2 2 L 4C 0 2 L 48 0 2 L 48 1 2 L 48 2 2

M 40 0 1
L 40 1 1
M 40 2 1

Arithmetic | L 44 0 3 L 40 0 3 L 40 1 3 L 40 2 3 L 4C 0 3 L 48 0 3 L 48 1 3 L 48 2 3

High | | M 54 3 0 M 54 3 2

Med | | M 54 3 1 M 54 3 3 M 5C 3 2 M 5C 3 3

Core | | L 54 1 0 L 50 3 0 L 54 0 0

M 50 0 0
L 50 1 0
M 50 2 0

High | | L 54 0 2 L 50 0 2 L 50 1 2 L 50 2 2 L 5C 0 2 L 58 0 2 L 58 1 2 L 58 2 2

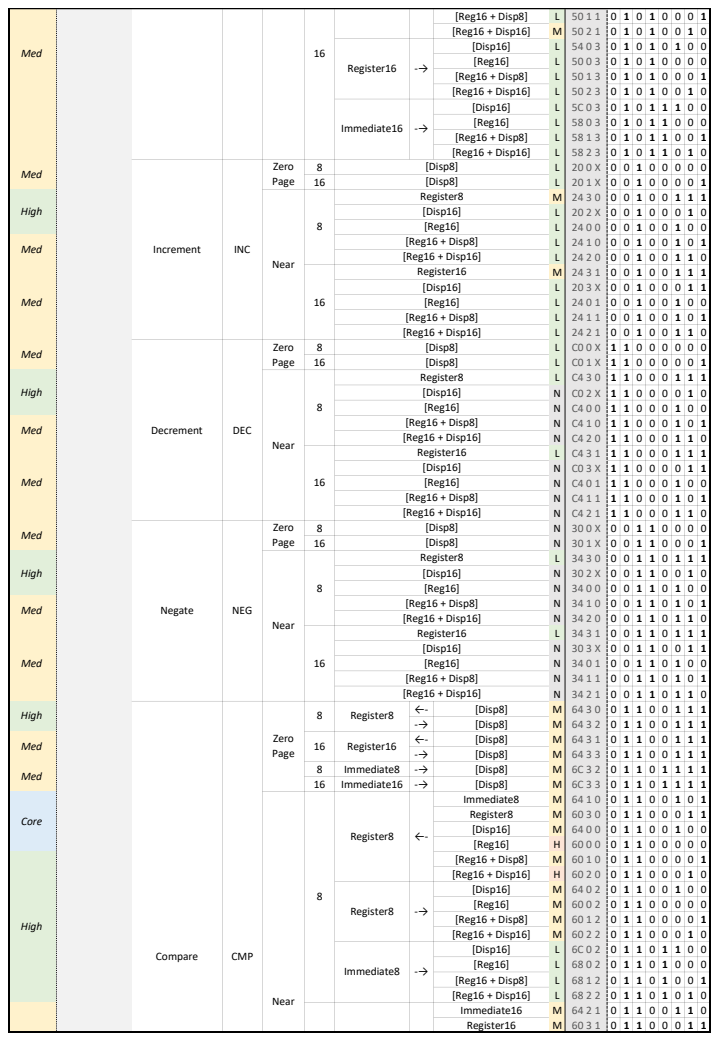
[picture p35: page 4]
[Reg16 + Disp8]; [Reg16 + Disp16]; [Disp16]; [Reg16]; [Disp8]; 8 Immediate8; 16 Immediate16; Immediate8; Register8; Immediate8 -; Near; Med; Register16; High; Register8 [Disp16]; Compare; CMP; Zero Page; 8 Register8; Negate; NEG; Register16 [Disp16] [Reg16] [Reg16 + Disp8]; [Reg16 + Disp16] Register16 [Disp16] [Reg16]; Decrement; DEC; Increment; INC; Immediate16 -

High | M 64 3 0 M 64 3 2

Med | M 64 3 1 M 64 3 3 M 6C 3 2 M 6C 3 3

Core | M 64 1 0 M 60 3 0 M 64 0 0

H 60 0 0
M 60 1 0
H 60 2 0

High | M 64 0 2 M 60 0 2 M 60 1 2 M 60 2 2

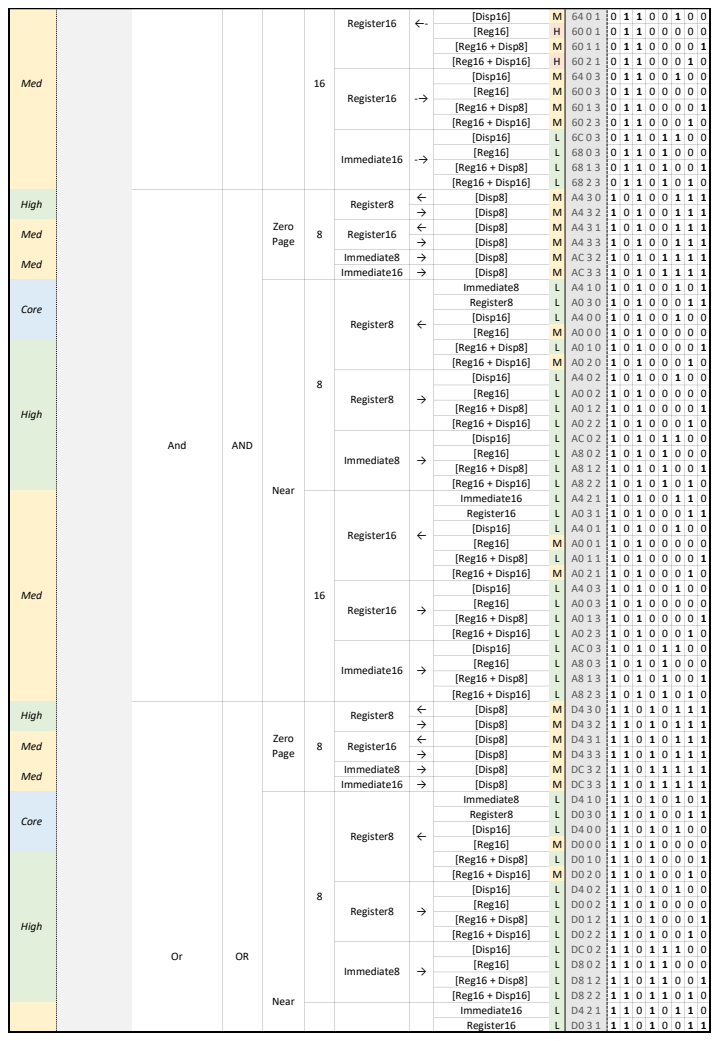
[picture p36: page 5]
[Disp16]; [Reg16]; [Reg16 + Disp8]; [Reg16 + Disp16]; [Disp8]; Immediate8; Immediate16; Register8; Register16; Med; Near; Zero Page; And; AND

M 64 0 1
H 60 0 1
M 60 1 1
H 60 2 1
M 64 0 3 M 60 0 3 M 60 1 3 M 60 2 3

High | M A4 3 0 M A4 3 2

Med | M A4 3 1 M A4 3 3 M AC 3 2 M AC 3 3

Core | L A4 1 0 L A0 3 0 L A4 0 0

M A0 0 0
L A0 1 0
M A0 2 0

High | L A4 0 2 L A0 0 2 L A0 1 2 L A0 2 2 L AC 0 2 L A8 0 2 L A8 1 2 L A8 2 2

M A0 0 1
L A0 1 1
M A0 2 1
L A4 0 3 L A0 0 3 L A0 1 3 L A0 2 3 L AC 0 3 L A8 0 3 L A8 1 3 L A8 2 3

High | M D4 3 0 M D4 3 2

Med | M D4 3 1 M D4 3 3 M DC 3 2 M DC 3 3

Core | L D4 1 0 L D0 3 0 L D4 0 0

M D0 0 0
L D0 1 0
M D0 2 0

High | L D4 0 2 L D0 0 2 L D0 1 2 L D0 2 2 L DC 0 2 L D8 0 2 L D8 1 2 L D8 2 2

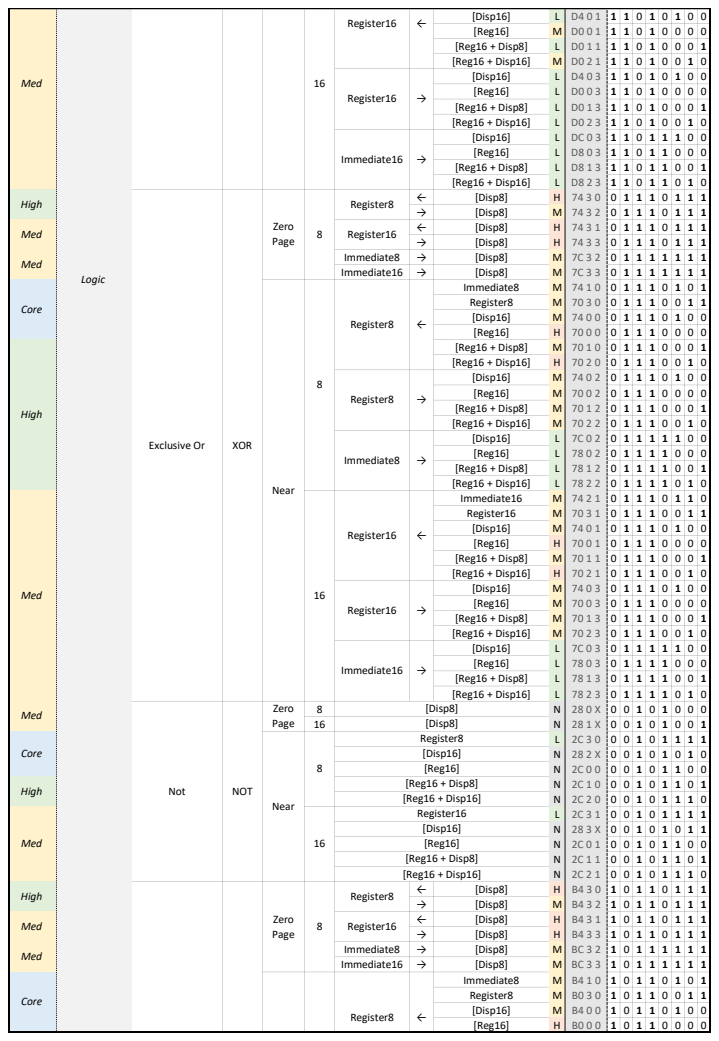
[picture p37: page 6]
[Disp16]; [Reg16]; [Reg16 + Disp8]; [Reg16 + Disp16]; [Disp8]; Immediate8; Immediate16; Register8; Register16; Immediate8 Register8; Med; Register16 [Disp16] [Reg16] [Reg16 + Disp8]; Core; Near; Register8 [Disp16]; Zero Page; Not; NOT; High; Exclusive Or; XOR

Med | Logic

Core

High | H B4 3 0

M B4 3 2
H B4 3 1 H B4 3 3

Med | M BC 3 2 M BC 3 3

Core | M B4 1 0 M B0 3 0 M B4 0 0

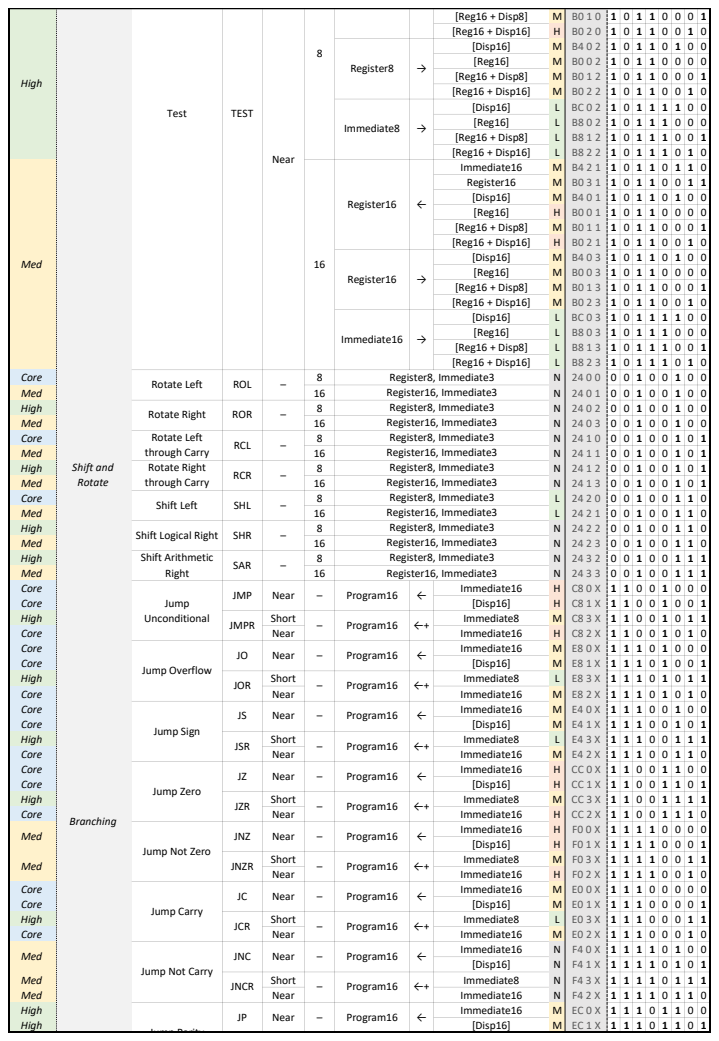
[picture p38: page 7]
[Reg16 + Disp8]; [Reg16 + Disp16]; [Disp16]; [Reg16]; Immediate16; Register16; Med; Core; High; Short; Immediate8; Near; Jump Parity; Program16; JNCR; Program16 ←+; JNC; JCR; Jump Carry; JNZR; JNZ; Jump Overflow; JZR; Jump Zero; JSR; Program16 ←+ ←; JMPR; Jump Unconditional; JMP; Jump Sign; JOR; Register16, Immediate3; Shift Arithmetic; Right; SAR; Register8, Immediate3; Register8; Test; TEST

Core | | Rotate Left ROL – 8 Register8, Immediate3 16 Register16, Immediate3 | N 24 0 0 N 24 0 1 | 0 0 1 0 0 1 0 0
Med
High | | Rotate Right ROR – Register8, Immediate3 8 16 Register16, Immediate3 | N 24 0 2 N 24 0 3 | 0 0 1 0 0 1 0 0
Core | | Rotate Left 8 Register8, Immediate3 through Carry RCL – 16 Register16, Immediate3 | N 24 1 0 N 24 1 1 | 0 0 1 0 0 1 0 1
High | Shift and | Rotate Right 8 Register8, Immediate3 through Carry RCR – 16 Register16, Immediate3 | N 24 1 2 N 24 1 3 | 0 0 1 0 0 1 0 1
Med | Rotate
Core | | Shift Left SHL – 8 Register8, Immediate3 Register16, Immediate3 16 | L 24 2 0 L 24 2 1 | | 0 0 1 0 0 1 1 0
High | | Shift Logical Right SHR – 8 Register8, Immediate3 16 Register16, Immediate3 | N 24 2 2 N 24 2 3 | | 0 0 1 0 0 1 1 0
High | | | N 24 3 2 N 24 3 3

M C8 3 X
H C8 2 X
M E8 0 X M E8 1 X

L E8 3 X
M E8 2 X M E4 0 X M E4 1 X

L E4 3 X
M E4 2 X
H CC 0 X H CC 1 X

Branching | H CC 2 X

Med | | H F0 0 X H F0 1 X

Jump Not Zero

M F0 3 X
H F0 2 X
M E0 0 X M E0 1 X

L E0 3 X
M E0 2 X

Med | | N F4 0 X N F4 1 X N F4 3 X N F4 2 X

Jump Not Carry

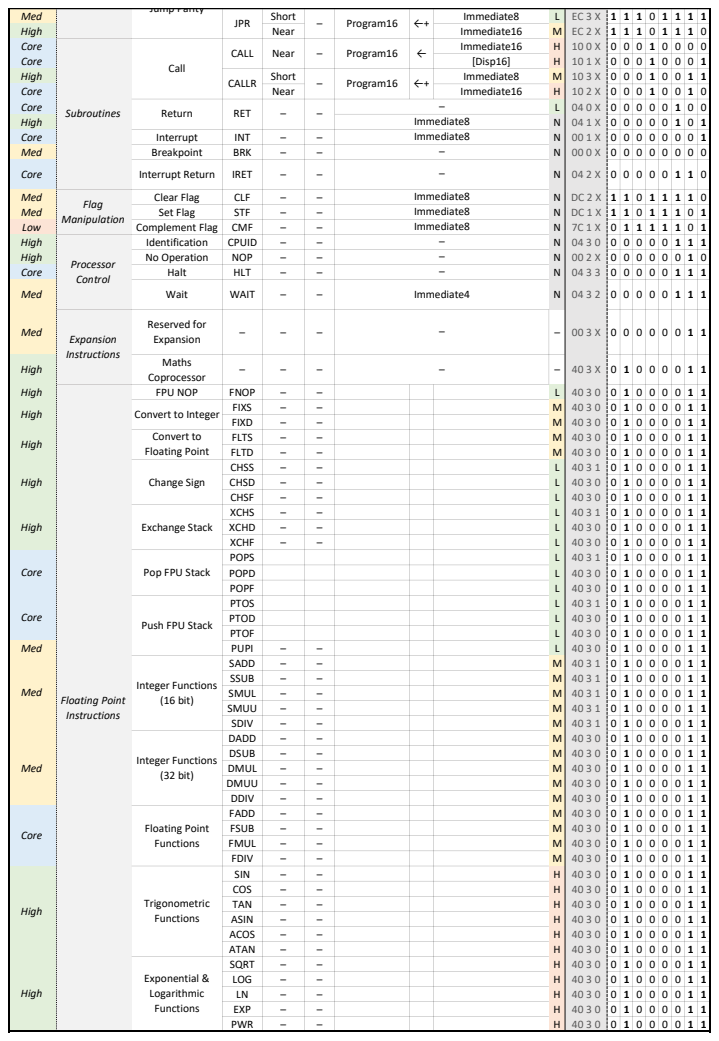
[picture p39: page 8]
Med; Short; Immediate8; High; Near; Immediate16; Core; [Disp16]; Interrupt; INT; Breakpoint; BRK; Interrupt Return; IRET; Clear Flag; CLF; Set Flag; STF; Low; Complement Flag CMF; Identification; CPUID; No Operation; NOP; Halt; HLT; Wait; WAIT; Reserved for; Expansion; Maths; Coprocessor; FPU NOP; FNOP; FIXS; FIXD; FLTS; FLTD; CHSS; CHSD; CHSF; XCHS; XCHD; XCHF; POPS; POPD; POPF; PTOS; PTOD; PTOF; PUPI; SADD; SSUB; SMUL; SMUU; SDIV; DADD; DSUB; DMUL; DMUU; DDIV; FADD; FSUB; FMUL; FDIV; SIN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

Convert to Integer
Convert to
Floating Point

Pop FPU Stack

Push FPU Stack

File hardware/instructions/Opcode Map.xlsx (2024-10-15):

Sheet: Version 8C Print
Ver 8C | 00 00 | 00 01 | 00 10 | 00 11 | 01 00 | 01 01 | 01 10 | 01 11 | 10 00 | 10 01 | 10 10 | 10 11 | 11 00 | 11 01 | 11 10 | 11 11
00 | Breakpoint |  |  |  | Interrupt |  |  |  | No Operation |  |  |  | Reserved for Expansion
04 | Return |  |  |  |  |  |  |  | Interrupt Return |  |  |  | CPU ID |  | Wait | Halt
08 | Function Call
0C | Jump Unconditional
10 | Jump Zero
14 | Jump Zero
18 | Jump Sign
1C | Jump Overflow
20 | Jump Overflow
24 | Jump Not Zero
28 | Jump Not Carry
2C |  |  |  |  |  |  |  |  | Shift Left |  |  |  | Sign Extend
30 | Move |  |  |  |  | Move |  |  |  |  |  |  |  |  | Exchange
34 |  |  |  |  |  |  |  |  |  | Move |  |  | Move
38 |  |  | Move |  | LEA |  | Move |  | LEA |  | Move
3C |  |  |  |  | Move Flags |  |  |  |  |  |  |  |  |  | Move
40 | Push |  |  |  |  |  |  |  |  | Pop Flags |  | Push Flags | Maths Coprocessor
44 |  |  |  |  |  |  |  |  | Push
48 | Pop
4C | Pop |  | Push |  | Pop |  | Push |  | Pop |  | Push |  | Pop |  | Push
50 | Increment
54 | Increment |  |  |  | Increment |  |  |  | Increment |  |  |  | Increment
58 | Decrement
5C | Decrement |  |  |  | Decrement |  |  |  | Decrement |  |  |  | Decrement
60 | Add |  |  |  |  | Add
64 |  |  |  |  |  |  |  |  |  | Add |  |  | Add
68 |  |  | Add |  |  |  | Add |  |  |  | Add
6C |  |  |  |  |  |  |  |  |  |  |  |  |  |  | Add
70 | Add Carry |  |  |  |  | Add Carry
74 |  |  |  |  |  |  |  |  |  | Add Carry |  |  | Add Carry
78 |  |  | Add Carry |  |  |  | Add Carry |  |  |  | Add Carry
7C |  |  |  |  |  |  |  |  |  |  |  |  |  |  | Add Carry
80 | Subtract |  |  |  |  | Subtract
84 |  |  |  |  |  |  |  |  |  | Subtract |  |  | Subtract
88 |  |  | Subtract |  |  |  | Subtract |  |  |  | Subtract
8C |  |  |  |  |  |  |  |  |  |  |  |  |  |  | Subtract
90 | Sub Borrow |  |  |  |  | Sub Borrow
94 |  |  |  |  |  |  |  |  |  | Sub Borr. |  |  | Sub Borrow
98 |  |  | Sub Borrow |  |  |  | Sub Borrow |  |  |  | Sub Borrow
9C |  |  |  |  |  |  |  |  |  |  |  |  |  |  | Sub Borrow
A0 | Compare |  |  |  |  | Compare
A4 |  |  |  |  |  |  |  |  |  | Compare |  |  | Compare
A8 |  |  | Compare |  |  |  | Compare |  |  |  | Compare
AC |  |  |  |  |  |  |  |  |  |  |  |  |  |  | Compare
B0 | Negate
B4 | Negate |  |  |  | Negate |  |  |  | Negate |  |  |  | Negate
B8 | Not
BC | Not |  |  |  | Not |  |  |  | Not |  |  |  | Not
C0 | Test |  |  |  |  | Test
C4 |  |  |  |  |  |  |  |  |  | Test |  |  | Test
C8 |  |  | Test |  |  |  | Test |  |  |  | Test
CC |  |  |  |  |  |  |  |  |  |  |  |  |  |  | Test
D0 | And |  |  |  |  | And
D4 |  |  |  |  |  |  |  |  |  | And |  |  | And
D8 |  |  | And |  |  |  | And |  |  |  | And
DC |  |  |  |  | In |  |  |  |  |  |  |  |  |  | And
E0 | Or |  |  |  |  | Or
E4 |  |  |  |  |  |  |  |  |  | Or |  |  | Or
E8 |  |  | Or |  |  |  | Or |  |  |  | Or
EC |  |  |  |  | Out |  |  |  |  |  |  |  |  |  | Or
F0 | Exclusive Or |  |  |  |  | Exclusive Or
F4 |  |  |  |  |  |  |  |  |  | Xor |  |  | Exclusive Or
F8 |  |  | Exclusive Or |  |  |  | Exclusive Or |  |  |  | Exclusive Or
FC |  |  |  |  | Set Flag |  |  |  | Clear Flag |  |  |  |  |  | Exclusive Or
43 00 | FNOP |  |  |  | SQRT |  |  |  | SIN |  |  |  | COS
43 04 | TAN |  |  |  | ASIN |  |  |  | ACOS |  |  |  | ATAN
43 08 | LOG |  |  |  | LN |  |  |  | EXP |  |  |  | PWR
43 0C
43 10 | FADD |  |  |  | FSUB |  |  |  | FMUL |  |  |  | FDIV
43 14 |  |  |  |  | CHSF |  |  |  |  |  |  |  | PTOF
43 18 | POPF |  |  |  | XCHF |  |  |  | PUPI
43 1C | FLTD |  |  |  | FLTS |  |  |  | FIXD |  |  |  | FIXS
43 20
43 24
43 28
43 2C | DADD |  |  |  | DSUB |  |  |  | DMUL |  |  |  | DDIV
43 30
43 34 | CHSD |  |  |  |  |  |  |  | DMUU |  |  |  | PTOD
43 38 | POPD |  |  |  | XCHD
43 3C
…
43 68
43 6C | SADD |  |  |  | SSUB |  |  |  | SMUL |  |  |  | SDIV
43 70
43 74 | CHSS |  |  |  |  |  |  |  | SMUU |  |  |  | PTOS
43 78 | POPS |  |  |  | XCHS
43 7C
…
43 FC

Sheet: Version 8C
Ver 8C | 00 00 | 00 01 | 00 10 | 00 11 | 01 00 | 01 01 | 01 10 | 01 11 | 10 00 | 10 01 | 10 10 | 10 11 | 11 00 | 11 01 | 11 10 | 11 11
00 | Breakpoint |  |  |  | Interrupt |  |  |  | No Operation |  |  |  | Reserved for Expansion
04 | Return |  |  |  |  |  |  |  | Interrupt Return |  |  |  | CPU ID |  | Wait | Halt
08 | Function Call
0C | Jump Unconditional
10 | Jump Zero
14 | Jump Zero
18 | Jump Sign
1C | Jump Overflow
20 | Jump Overflow
24 | Jump Not Zero
28 | Jump Not Carry
2C |  |  |  |  |  |  |  |  | Shift Left |  |  |  | Sign Extend
30 | Move |  |  |  |  | Move |  |  |  |  |  |  |  |  | Exchange
34 |  |  |  |  |  |  |  |  |  | Move |  |  | Move
38 |  |  | Move |  | LEA |  | Move |  | LEA |  | Move
3C |  |  |  |  | Move Flags |  |  |  |  |  |  |  |  |  | Move
40 | Push |  |  |  |  |  |  |  |  | Pop Flags |  | Push Flags | Maths Coprocessor
44 |  |  |  |  |  |  |  |  | Push
48 | Pop
4C | Pop |  | Push |  | Pop |  | Push |  | Pop |  | Push |  | Pop |  | Push
50 | Increment
54 | Increment |  |  |  | Increment |  |  |  | Increment |  |  |  | Increment
58 | Decrement
5C | Decrement |  |  |  | Decrement |  |  |  | Decrement |  |  |  | Decrement
60 | Add |  |  |  |  | Add
64 |  |  |  |  |  |  |  |  |  | Add |  |  | Add
68 |  |  | Add |  |  |  | Add |  |  |  | Add
6C |  |  |  |  |  |  |  |  |  |  |  |  |  |  | Add
70 | Add Carry |  |  |  |  | Add Carry
74 |  |  |  |  |  |  |  |  |  | Add Carry |  |  | Add Carry
78 |  |  | Add Carry |  |  |  | Add Carry |  |  |  | Add Carry
7C |  |  |  |  |  |  |  |  |  |  |  |  |  |  | Add Carry
80 | Subtract |  |  |  |  | Subtract
84 |  |  |  |  |  |  |  |  |  | Subtract |  |  | Subtract
88 |  |  | Subtract |  |  |  | Subtract |  |  |  | Subtract
8C |  |  |  |  |  |  |  |  |  |  |  |  |  |  | Subtract
90 | Sub Borrow |  |  |  |  | Sub Borrow
94 |  |  |  |  |  |  |  |  |  | Sub Borr. |  |  | Sub Borrow
98 |  |  | Sub Borrow |  |  |  | Sub Borrow |  |  |  | Sub Borrow
9C |  |  |  |  |  |  |  |  |  |  |  |  |  |  | Sub Borrow
A0 | Compare |  |  |  |  | Compare
A4 |  |  |  |  |  |  |  |  |  | Compare |  |  | Compare
A8 |  |  | Compare |  |  |  | Compare |  |  |  | Compare
AC |  |  |  |  |  |  |  |  |  |  |  |  |  |  | Compare
B0 | Negate
B4 | Negate |  |  |  | Negate |  |  |  | Negate |  |  |  | Negate
B8 | Not
BC | Not |  |  |  | Not |  |  |  | Not |  |  |  | Not
C0 | Test |  |  |  |  | Test
C4 |  |  |  |  |  |  |  |  |  | Test |  |  | Test
C8 |  |  | Test |  |  |  | Test |  |  |  | Test
CC |  |  |  |  |  |  |  |  |  |  |  |  |  |  | Test
D0 | And |  |  |  |  | And
D4 |  |  |  |  |  |  |  |  |  | And |  |  | And
D8 |  |  | And |  |  |  | And |  |  |  | And
DC |  |  |  |  | In |  |  |  |  |  |  |  |  |  | And
E0 | Or |  |  |  |  | Or
E4 |  |  |  |  |  |  |  |  |  | Or |  |  | Or
E8 |  |  | Or |  |  |  | Or |  |  |  | Or
EC |  |  |  |  | Out |  |  |  |  |  |  |  |  |  | Or
F0 | Exclusive Or |  |  |  |  | Exclusive Or
F4 |  |  |  |  |  |  |  |  |  | Xor |  |  | Exclusive Or
F8 |  |  | Exclusive Or |  |  |  | Exclusive Or |  |  |  | Exclusive Or
FC |  |  |  |  | Set Flag |  |  |  | Clear Flag |  |  |  |  |  | Exclusive Or
43 00 | FNOP |  |  |  | SQRT |  |  |  | SIN |  |  |  | COS
43 04 | TAN |  |  |  | ASIN |  |  |  | ACOS |  |  |  | ATAN
43 08 | LOG |  |  |  | LN |  |  |  | EXP |  |  |  | PWR
43 0C
43 10 | FADD |  |  |  | FSUB |  |  |  | FMUL |  |  |  | FDIV
43 14 |  |  |  |  | CHSF |  |  |  |  |  |  |  | PTOF
43 18 | POPF |  |  |  | XCHF |  |  |  | PUPI
43 1C | FLTD |  |  |  | FLTS |  |  |  | FIXD |  |  |  | FIXS
43 20
43 24
43 28
43 2C | DADD |  |  |  | DSUB |  |  |  | DMUL |  |  |  | DDIV
43 30
43 34 | CHSD |  |  |  |  |  |  |  | DMUU |  |  |  | PTOD
43 38 | POPD |  |  |  | XCHD
43 3C
43 40
43 44
43 48
43 4C
43 50
43 54
43 58
43 5C
43 60
43 64
43 68
43 6C | SADD |  |  |  | SSUB |  |  |  | SMUL |  |  |  | SDIV
43 70
43 74 | CHSS |  |  |  |  |  |  |  | SMUU |  |  |  | PTOS
43 78 | POPS |  |  |  | XCHS
43 7C
43 80
43 84
43 88
43 8C
43 90
43 94
43 98
43 9C
43 A0
43 A4
43 A8
43 AC
43 B0
43 B4
43 B8
43 BC
43 C0
43 C4
43 C8
43 CC
43 D0
43 D4
43 D8
43 DC
43 E0
43 E4
43 E8
43 EC
43 F0
43 F4
43 F8
43 FC

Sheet: Version 8B
Ver 8B | 00 00 | 00 01 | 00 10 | 00 11 | 01 00 | 01 01 | 01 10 | 01 11 | 10 00 | 10 01 | 10 10 | 10 11 | 11 00 | 11 01 | 11 10 | 11 11
00 | Breakpoint |  |  |  | Interrupt |  |  |  | No Operation |  |  |  | Reserved for Expansion
04 | Return |  |  |  |  |  |  |  | Interrupt Return |  |  |  | CPU ID |  | Wait | Halt
08 | Function Call
0C | Jump Unconditional
10 | Jump Zero
14 | Jump Zero
18 | Jump Sign
1C | Jump Overflow
20 | Jump Overflow
24 | Jump Not Zero
28 | Jump Not Carry
2C | ~~Rotate Left~~ |  | ~~Rotate Right~~ |  | ~~Rotate Carry Left~~ |  | ~~Rotate Carry Right~~ |  | Shift Left |  | ~~Shift Right~~ |  | Sign Extend |  | ~~Shift Arithmetic Right~~
30 | Move |  |  |  |  | Move |  |  |  |  |  |  |  |  | Exchange
34 |  |  |  |  |  |  |  |  |  | Move |  |  | Move
38 |  |  | Move |  | LEA |  | Move |  | LEA |  | Move
3C |  |  |  |  | Move Flags |  |  |  |  |  |  |  |  |  | Move
40 | Push |  |  |  |  |  |  |  |  | Pop Flags |  | Push Flags | Maths Coprocessor
44 | Push
48 | Pop
4C | Pop |  | Push |  | Pop |  | Push |  | Pop |  | Push |  | Pop |  | Push
50 | Increment
54 | Increment |  |  |  | Increment |  |  |  | Increment |  |  |  | Increment
58 | Decrement
5C | Decrement |  |  |  | Decrement |  |  |  | Decrement |  |  |  | Decrement
60 | Add |  |  |  |  | Add
64 |  |  |  |  |  |  |  |  |  | Add |  |  | Add
68 |  |  | Add |  |  |  | Add |  |  |  | Add
6C |  |  |  |  |  |  |  |  |  |  |  |  |  |  | Add
70 | Add Carry |  |  |  |  | Add Carry
74 |  |  |  |  |  |  |  |  |  | Add Carry |  |  | Add Carry
78 |  |  | Add Carry |  |  |  | Add Carry |  |  |  | Add Carry
7C |  |  |  |  |  |  |  |  |  |  |  |  |  |  | Add Carry
80 | Subtract |  |  |  |  | Subtract
84 |  |  |  |  |  |  |  |  |  | Subtract |  |  | Subtract
88 |  |  | Subtract |  |  |  | Subtract |  |  |  | Subtract
8C |  |  |  |  |  |  |  |  |  |  |  |  |  |  | Subtract
90 | Sub Borrow |  |  |  |  | Sub Borrow
94 |  |  |  |  |  |  |  |  |  | Sub Borr. |  |  | Sub Borrow
98 |  |  | Sub Borrow |  |  |  | Sub Borrow |  |  |  | Sub Borrow
9C |  |  |  |  |  |  |  |  |  |  |  |  |  |  | Sub Borrow
A0 | Compare |  |  |  |  | Compare
A4 |  |  |  |  |  |  |  |  |  | Compare |  |  | Compare
A8 |  |  | Compare |  |  |  | Compare |  |  |  | Compare
AC |  |  |  |  |  |  |  |  |  |  |  |  |  |  | Compare
B0 | Negate
B4 | Negate |  |  |  | Negate |  |  |  | Negate |  |  |  | Negate
B8 | Not
BC | Not |  |  |  | Not |  |  |  | Not |  |  |  | Not
C0 | Test |  |  |  |  | Test
C4 |  |  |  |  |  |  |  |  |  | Test |  |  | Test
C8 |  |  | Test |  |  |  | Test |  |  |  | Test
CC |  |  |  |  |  |  |  |  |  |  |  |  |  |  | Test
D0 | And |  |  |  |  | And
D4 |  |  |  |  |  |  |  |  |  | And |  |  | And
D8 |  |  | And |  |  |  | And |  |  |  | And
DC |  |  |  |  | In |  |  |  |  |  |  |  |  |  | And
E0 | Or |  |  |  |  | Or
E4 |  |  |  |  |  |  |  |  |  | Or |  |  | Or
E8 |  |  | Or |  |  |  | Or |  |  |  | Or
EC |  |  |  |  | Out |  |  |  |  |  |  |  |  |  | Or
F0 | Exclusive Or |  |  |  |  | Exclusive Or
F4 |  |  |  |  |  |  |  |  |  | Xor |  |  | Exclusive Or
F8 |  |  | Exclusive Or |  |  |  | Exclusive Or |  |  |  | Exclusive Or
FC |  |  |  |  | Set Flag |  |  |  | Clear Flag |  |  |  |  |  | Exclusive Or
43 00
43 04
43 08
43 0C
43 10
43 14
43 18
43 1C
43 20
43 24
43 28
43 2C
43 30
43 34
43 38
43 3C
43 40
43 44
43 48
43 4C
43 50
43 54
43 58
43 5C
43 60
43 64
43 68
43 6C
43 70
43 74
43 78
43 7C
43 80
43 84
43 88
43 8C
43 90
43 94
43 98
43 9C
43 A0
43 A4
43 A8
43 AC
43 B0
43 B4
43 B8
43 BC
43 C0
43 C4
43 C8
43 CC
43 D0
43 D4
43 D8
43 DC
43 E0
43 E4
43 E8
43 EC
43 F0
43 F4
43 F8
43 FC
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

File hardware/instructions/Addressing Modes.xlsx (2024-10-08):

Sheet: Registers
Address | 8 Bit Op. | 16 Bit Op. |  | Register |  | Use
000 | AL | AX |  | AH | AL | GP, Arguments, Returns
001 | BL | BX | *16 bit only register. | BH | BL | GP, Arguments
010 | CL | CX | **Stack pointers. | CH | CL | GP, Counters
011 | DL | DX |  | DH | DL | GP
100 | AH | EX* |  | EX |  | GP
101 | BH | FX* |  | FX |  | GP, Relative data offset for PIC?
110 | CH | SP** |  | SP |  | Stack
111 | DH | BP** |  | BP |  | Stack

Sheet: Instruction Format
Byte 1 | Byte 2 | Byte 3 | Byte 4 | Byte 5 | Byte 6 | Byte 7
Opcode + Mod |  | D/W R/M | Displacement |  | Immediate
Instruction / Opcode (Bits)
Any Opcode |  |  |  |  |  | Mod
Byte 1 |  |  |  | Byte 2
Opcode |  |  | Mod | Size + Direction |  | R/M | Reg
Byte 1 | Byte 2 | Byte 3 | ~~Byte 4~~ | Byte 5 | Byte 6 | Byte 7 | Byte 8
Instruction / Opcode |  | Mod R/M | ~~SIB~~ | Displacement |  | Immediate
Instruction / Opcode (Bits)
Any Opcode |  |  |  |  |  | Size | Direction
Byte 1 |  |  | Byte 2 |  |  | ~~Byte 3~~
Opcode | Size | Direction | Mod | Reg | R/M | ~~Scale~~ | ~~Index~~ | ~~Base~~

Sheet: Mod RM
R/M \\ Mod | 00 | 01 | 10 | 11
000 | [AX] | [AX + Disp8] | [AX + Disp16] | Reg AL/AX
001 | [BX] | [BX + Disp8] | [BX + Disp16] | Reg BL/BX | Mod | R/M | Reg
010 | [CX] | [CX + Disp8] | [CX + Disp16] | Reg CL/CX | 2 b | 3 b | 3 b
011 | [DX] | [DX + Disp8] | [DX + Disp16] | Reg DL/DX
100 | [EX] | [EX + Disp8] | [EX + Disp16] | Reg AH/EX | Mod | Meaning
101 | [FX] | [FX + Disp8] | [FX + Disp16] | Reg BH/FX | 00 | Register indirect.
110 | [SP] | [SP + Disp8] | [SP + Disp16] | Reg CH/SP | 01 | Register indirect with 8bit displacement.
111 | [BP] | [BP + Disp8] | [BP + Disp16] | Reg DH/BP | 10 | Register indirect with 16bit displacement.
 | [Reg16] | [Reg16 + Disp8] | [Reg16 + Disp16] | Reg8/Reg16 | 11 | Register direct.
XXX | [Disp16] | Imm8 | Imm16 | [Disp8]
 |  |  |  |  | Reg defines the src or dst register, Mod & R/M define the other src or dst register/memory location.
 | ~~[Reg8]~~ | ~~Load from zero page ~~(addr in reg8)~~~~
 | [Disp8] | Load from zero page (addr in imm8)
 | [Disp16] | Load from anywhere (addr in imm16)
 | Imm8 | Load immediate from imm8
 | Imm16 | Load immediate from imm16

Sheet: SIB.old
Scale | Factor
00 | ×1
01 | ×2 | Scale | Index | Base
10 | ×4 | 2 b | 3 b | 3 b
11 | ×8
 |  | Index & Base refer to registers.

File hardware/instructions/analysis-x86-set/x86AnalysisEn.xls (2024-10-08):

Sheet: Length
length | file1 | file2 | file3 | total count | percentage |  | percentage of the code size
1 | 14540 | 28777 | 9675 | 52992 | 15.57% | 0.1557195919 | 4.77%
2 | 24481 | 41895 | 31822 | 98198 | 28.86% | 0.5771192816 | 17.67%
3 | 19893 | 32186 | 17297 | 69376 | 20.39% | 0.6115943392 | 18.72%
4 | 7174 | 17419 | 9523 | 34116 | 10.03% | 0.4010061592 | 12.28%
5 | 9060 | 14109 | 7468 | 30637 | 9.00% | 0.4501416381 | 13.78%
6 | 9430 | 8365 | 11102 | 28897 | 8.49% | 0.5094915135 | 15.60%
7 | 2589 | 5634 | 12896 | 21119 | 6.21% | 0.4344145235 | 13.30%
8 | 323 | 2362 | 728 | 3413 | 1.00% | 0.08023414359 | 2.46%
9 | 8 | 6 | 0 | 14 | 0.004113968687% | 0.0003702571818 | 0.01%
10 | 495 | 159 | 475 | 1129 | 0.33% | 0.03317621891 | 1.02%
11 | 34 | 275 | 104 | 413 | 0.12% | 0.01334982839 | 0.41%
 |  |  |  | 340304 |  | 3.266617495

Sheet: Top 20
mov | 119105 | mov | 119105
push | 34028 | push | 34028
call | 20458 | call | 20458
cmp | 15736 | cmp | 15736
add | 14677 | add | 14677
pop | 13893 | pop | 13893
lea | 13134 | lea | 13134
test | 9508 | test | 9508
je | 9335 | je | 9335
xor | 8312 | xor | 8312
jmp | 7569 | jmp | 7569
jne | 7471 | jne | 7471
ret | 4942 | ret | 4942
inc | 4639 | inc | 4639
sub | 4515 | sub | 4515
fld | 4396 | fld | 4396
and | 3772 | and | 3772
fstp | 3538 | fstp | 3538
shl | 2884 | shl | 2884
or | 2512 | or | 2512
fmul | 2404 | Others | 35880
shr | 2309
jl | 2076
dec | 2010
jle | 1942
fxch | 1761
sar | 1497
jnb | 1172
jb | 1092
repz | 1075
jge | 1068
jg | 1058
jbe | 986
fadd | 940
nop | 856
movzx | 719
not | 709
scasb | 601
repnz | 601
faddp | 591
ja | 556
movsd | 536
neg | 482
fstsw | 481
sahf | 472
imul | 458
fild | 451
movsb | 353
cdq | 347
movsx | 333
sbb | 331
fsub | 325
fcomip | 299
fst | 283
leave | 275
fcom | 263
sete | 229
stosd | 223
adc | 211
jnl | 210
fcomp | 199
fsubp | 171
fmulp | 168
fcomi | 159
fistp | 149
idiv | 134
fsubr | 127
dword | 119
fchs | 113
setne | 101
fdiv | 99
fdivp | 78
byte | 70
div | 65
fldlg | 61
mul | 58
fylx | 55
cmovl | 54
jns | 53
fdivr | 53
fcos | 53
fcmovnbe | 51
stosb | 50
movq | 47
js | 47
fcmovnb | 45
fdivrp | 42
fcmovbe | 40
fabs | 39
fsqrt | 38
fcmovb | 38
setle | 36
wait | 33
cmovnle | 33
fldcw | 29
cmovne | 28
fsubrp | 25
frndint | 24
fscale | 23
fldle | 23
movd | 21
setg | 19
cmovc | 19
punpckhdq | 18
cmovnl | 18
punpckldq | 17
fldln | 17
int | 16
fstcw | 16
cmove | 14
cld | 14
rcr | 13
std | 12
rol | 12
fldz | 12
xchg | 10
setl | 10
cmovle | 10
stosw | 9
setnl | 9
fincstp | 9
fsin | 8
fprem | 8
fcompp | 8
cmova | 8
pxor | 7
pmaddwd | 7
packssdw | 6
movsw | 6
lock | 6
cpuid | 6
jpe | 5
pushad | 4
psubusw | 4
paddw | 4
fcmove | 4
emms | 4
cmpsd | 4
cmpsb | 4
bswap | 4
setb | 3
paddusw | 3
paddd | 3
out | 3
jcxz | 3
bts | 3
bt | 3
xadd | 2
shrd | 2
shld | 2
pushfd | 2
psubw | 2
psraw | 2
popad | 2
pcmtgtw | 2
outsd | 2
fstenv | 2
fldenv | 2
fimul | 2
ffidiv | 2
setnb | 1
rdmsr | 1
psubsw | 1
popfd | 1
pmulhw | 1
les | 1
fxam | 1
fptan | 1
fpatan | 1
fldpi | 1
fdecstp | 1
fcmovne | 1
fclex | 1
cmovnc | 1
bsr | 1
aad | 1

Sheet: Number of operands
Without operands | 2050 | 4087 | 2843 | 8980
1 operand | 34284 | 56343 | 36131 | 126758
2 operands | 51693 | 90757 | 62069 | 204519
3 operands |  |  | 47 | 47

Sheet: Operand types
immediate | 107535 | 20.06485837%
register | 300181 | 56.01050123%
absolute address | 5454 | 1.017656926%
indirect address | 122767 | 22.90698347%
 | 535937

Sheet: Formats
register-memory | 20489 | 33930 | 17964 | 72383
register-register | 11402 | 23718 | 19164 | 54284
register-immediate | 8838 | 13121 | 10780 | 32739
memory-register | 7431 | 12517 | 11232 | 31180
memory-immediate | 3531 | 7471 | 2928 | 13930

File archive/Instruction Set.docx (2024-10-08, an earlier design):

Instruction (5) | Parameter (3) | Data (3 or 8) | Data (8) | Opcode | Name | Description
Mov | Reg | Reg | - | 00000 | Move | Requires push to stack. Used as Nop.
Wait | - | - | - | 00001 | Halt
Lda | Reg | Addr | Addr | 00010 | Load Address | [Seg][Addr]
Ldr | Reg | Reg | - | 00011 | Load Register | “”
Ldi | Reg | Value | - | 00100 | Load Immediate | -128 to 127 (00h to FFh)
Sta | Reg | Addr | Addr | 00101 | Store Address | [Seg][Addr]
Str | Reg | Reg | - | 00110 | Store Register | “”
Push | Reg | - | - | 00111 | Push
Pop | Reg | - | - | 01000 | Pop
Call | Addr | Addr | Addr | 01001 | Call | Don’t use segment register.
Ret | - | - | - | 01010 | Return
Jmp | Addr | Addr | Addr | 01011 | Jump | Don’t use segment register.
Jc | Addr | Addr | Addr | 01100 | Jump if Carry | Jump if bellow.
Jz | Addr | Addr | Addr | 01101 | Jump if Zero | Jump if equal.
Jo | Addr | Addr | Addr | 01110 | Jump if Overflow
Jp | Addr | Addr | Addr | 01111 | Jump if Parity
Cmp | Reg | Reg | - | 10000 | Compare | Subtraction; discards results, updates flags.
Add | Reg | Reg | - | 10001 | Add | First register is A, seconds is B.
Adc | Reg | Reg | - | 10010 | Add with Carry | Use CF as carry input.
Inc | Reg | Reg | - | 10011 | Increment | Add 0 with carry high.
Sub | Reg | Reg | - | 10100 | Subtract
Sbb | Reg | Reg | - | 10101 | Sub with Borrow | Use CF as borrow input.
Dec | Reg | Reg | - | 10110 | Decrement | Add 0 with borrow high.
Shl | Reg | Reg | - | 10111 | Logical Shift Left
Rcl | Reg | Reg | - | 11000 | Rotate Carry Left
Not | Reg | Reg | - | 11001 | Negate
And | Reg | Reg | - | 11010 | Conjoin
Or | Reg | Reg | - | 11011 | Disjoin
Xor | Reg | Reg | - | 11100 | Exclusive Disjoin
Flg | Mode | - | - | 11101 | Flag Update | Choose a control flag to update.
Seg | Value | Value | - | 11110 | Segment | Update segment register.
Int | - | Value | - | 11111 | Interrupt | Choose interrupt to raise.

Instruction (5) | Parameter (3) | Data (8 or 3) | Code | Name | Description
Mov | Reg | Reg | 00 | Move | Requires push to stack. Used as Nop.
Hlt | - | - | 01 | Halt
Lda | Reg | Addr | 02 | Load Address | [Seg][Addr]
Ldr | Reg | Reg | 03 | Load Register | “”
Ldi | Reg | Value | 04 | Load Immediate | -128 to 127 (00h to FFh)
Sta | Reg | Addr | 05 | Store Address | [Seg][Addr]
Str | Reg | Reg | 06 | Store Register | “”
Push | Reg | - | 07 | Push
Pop | Reg | - | 08 | Pop
Call | - | Addr | 09 | Call | [Seg][Addr]
Ret | - | - | 0A | Return
Jmp | - | Addr | 0B | Jump | [Seg][Addr]
Bnch | Mode | Addr | 0C | Branch | Cond jump. Choose flag to jump on.
Add | Reg | - | 0D | Add
Adc | Reg | - | 0E | Add with Carry | Use CF as carry input.
Inc | Reg | - | 0F | Increment | Add 0 with carry high.
Sub | Reg | - | 10 | Subtract
Sbb | Reg | - | 11 | Sub with Borrow | Use CF as borrow input.
Dec | Reg | - | 12 | Decrement | Add 0 with borrow high.
Shl | Reg | - | 13 | Logical Shift Left
Rcl | Reg | - | 14 | Rotate Carry Left
Not | Reg | - | 15 | Negate
And | Reg | - | 16 | Conjoin
Or | Reg | - | 17 | Disjoin
Xor | Reg | - | 18 | Exclusive Disjoin
Flg | Mode | - | 19 | Flag | Chose flag to update.
In | Dev | Reg | 1A | Input | Receive data from device to register.
Out | Dev | Reg | 1B | Output | Send data from register to device.
Send | Dev | Value | 1C | Send (Output) | Send literal data to device.
Int | - | Value | 1D | Interrupt | Choose interrupt to raise.
Seg | Value | Value | 1E | Segment | Update segment register.
Sec | Value | - | 1F | Segment Count | Inc or Dec segment.

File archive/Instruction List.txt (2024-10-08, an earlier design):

inst [mod], w[dst]w[src], [adr/lit]...
6-2, 1-3-1-3, 8x...

nop  xx                               \\ no operation

ld   00, x[dst] x[src]                \\ load b/w @ src > dst; if dst is word, load 2 addresses
ld   01, 0[dst]       , [adr]         \\ load byte @ adr > dst
ld   01, 1[dst]       , [adr], [adr]  \\ load word @ adr > dst
ld   10, 0[dst]       , [lit]         \\ load byte lit > dst
ld   10, 1[dst]       , [lit], [lit]  \\ load word lit > dst

str  00, x[dst] x[src]                \\ dst is memory address, src is memory contents; if src is word, store 2 addresses
str  01, 0      x[src], [adr]         \\ 
str  01, 1      x[src], [adr], [adr]  \\ 

mov  xx, x[dst] x[src]                \\ copy src contents > dst; is src is wider than dst, copy only high/low byte; some registers cannot be written to using mov; (ld & str should be mov)

out  00, x[dvc] x[src]                \\ copy b/w @ src > i/o device; if dst is word, copy 2 addresses
out  10, x[dvc] 0     , [lit]         \\ copy byte lit > dvc
out  10, x[dvc] 1     , [lit], [lit]  \\ copy word lit > dvc

in   00, x[dst] x[dvc]                \\ copy b/w from i/o device > dst; if dvc wider than dst, copy only high/low byte

add  00, x[dst] x[src]                \\ add b/w @ src to> dst; if dst is word, add 2 addresses
add  01, 0[dst]       , [adr]         \\ add byte @ adr to> dst
add  01, 1[dst]       , [adr], [adr]  \\ add word @ adr to> dst
add  10, 0[dst]       , [lit]         \\ add byte lit to> dst
add  10, 1[dst]       , [lit], [lit]  \\ add word lit to> dst

sub  00, x[dst] x[src]                \\ sub b/w @ src from> dst; if dst is word, add 2 addresses
sub  01, 0[dst]       , [adr]         \\ sub byte @ adr from> dst
sub  01, 1[dst]       , [adr], [adr]  \\ sub word @ adr from> dst
sub  10, 0[dst]       , [lit]         \\ sub byte lit from> dst
sub  10, 1[dst]       , [lit], [lit]  \\ sub word lit from> dst

hlt  xx                               \\ halt operation

jmp, conditionals, call, ret; logic;

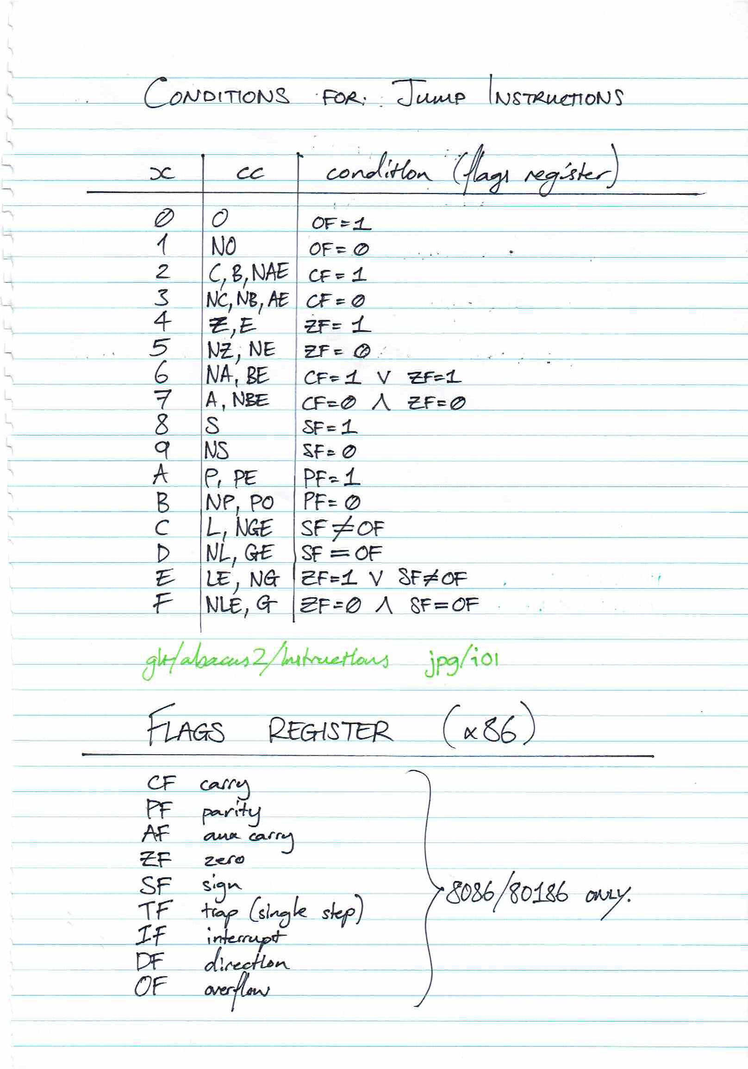
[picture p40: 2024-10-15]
hardware/instructions/i01.JPG

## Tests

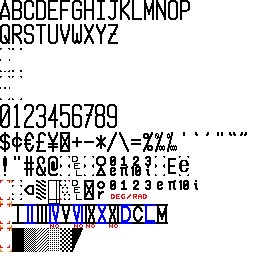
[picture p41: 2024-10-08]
hardware/video/video_adapter/fonts/Test Latin.jpg

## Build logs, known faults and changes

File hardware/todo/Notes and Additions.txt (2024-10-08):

USE THE 6502 AND 8086 BLOCK DIAGRAMS TO DESIGN THE CPU AND ENSURE THAT WE DONT MISS ANY COMPONENTS !!!

Does the DMA Controller need its own Interrupt Channel???
Include DMA circuitry on the Interrupt Controller card.

have a flag in the FLAGS register that unlocks the ROM (write protection, enabled by default).

POINTER REGISTERS can INC and DEC on their own without using the ALU...
Software much check for stack overflow by using the top-of-heap OR stack-size-limit variable to compare BEFORE down to another fucntion.

XXX-INGORE: Allows ALU to simultaneously check for stack pointer underflow to detect if stack is overflowed.

INSTRUCTION DECODING:
INST: 6 bits
MOD: 2 bits
D/S: 2 bits (in second byte)
10 BIT MICROCODE ROM (1024x32ish)
 1) Get first byte and load into instruction register (D/S bytes will be leftover and dont matter for now)
 2) If instruction needs more data, get next byte and load D/S bits into instruction register (and RM/Reg bits into other control registers, ALU, etc)

First 2 bits of instruction are loaded into S3,S2 of 74181 ALU, and the S1,S0 and M control lines are generated by the microcode.
For ADC and SBB, the microcode must force set/reset the carry flag.

USE LITTLE ENDIAN

16bit memory instructions must be used with ALLIGNED ADDRESSES (i.e. ending in 0 so that one byte can be taken from each bank even+odd).
If an ODD address is specified, detect in hardware (not in microcode) and raise an exception (perhaps the BP instruction? or a violation interrupt like 15h?)

Have an interrupt (e.g. INT 15h) that is called when an access-violation (e.g. writing to ROM while ROM-PROTECT flag is set) or a memory misalignment occurs.

STACK POINTER will always point to an even address so that 16-bit memory operations can occur in the stack.
If an 8-bit byte is pushed to the stack, the SP will still be decremented by 2 and an empty garbage/zero byte will be after the data byte.
When 8-bit byte popped from stack, lower byte will be ignored.

have TEMP register for immediate operators such as SEGMENT-INCREMENT... if seg-inc by 4, seg register is added to temp register which contains 4.

have front panel switches (dual point, floating default) that manually set SR-latched of flags register when in Program mode.

Have an external control panel that plugs into the computer front panel
External controls include a 555 variable clock, an ammeter/voltmeter, various other more specific indicator lights, etc

Need PC Speaker on motherboard chipset.

Sound chip is AY8930.
To play music, use raster interrupts to run a routine every 0.02s that takes instructions from memory and updates the sound chip's registers.
This way, songs can be stored in DATA memory instead of the CPU having to execute music generation code from CODE memory.
Have a time multiplier (8bit value) that is used in a countdown register (in zero page) to update values every N raster interrupts. Basically makes the song play slower, but saves memory.

Support BURST/BLOCK and CYCLE STEALING DMA modes!!

each bus connector can CLK, RST, CLR (memory clear), INTREQ (int request), plus DMA service lines.
CHIP ENABLE signals sent over a multiplexed set of lines (4 instead of 16 parallel). The CS number selects the expansion port, then the expansion device has to read the Address rfom the bus and route the CS signal to the SPECIFIC REGISTER that is being addressed.

SEE EXTERNAL TXT FILE FOR INTERRUPT INFORMATION!

IMPORTANT: Should there be a buffer in-between the "CPU internal bus" and the "external bus"? Or should they be directly wired.
I imagine having a buffer would introduce a propegation delay? Is it important to have for DMA?

How do bus device control registers work? are they directly tied to control lines? Is there logic behind them?
Dont forget to tie the control register outputs low.

A few GPIO pins exposed on motherboard with VCC pins beside them for jumping, these pins are pulled to ground so whe they arent jumped they are low. Can be read by the system as hard coded variables eg. for expansion configuration.

ORDER SOME PCB CUT OFFS THAT ARE JUST GOLDFINGER TO BREADBOARD-PIN-HOLES ADAPTERS (so that we can just use regular DIY 90DEG EDGE PINS to plug into the bus).

OLD FLAGS REGISTER:

Status flags (lsb to msb): CARRY, ZERO, OVERFLOW, SIGN/NEGATIVE, PARITY.
Control flags (lsb to msb): INTERRUPT-ENABLE, MEMORY-TRANSPARENCY (?), ROM-PROTECT/PRIVILEDGE-LEVEL.
System flags (lsb to msb): HALTED, WAITING, STACK-OVERFLOW?, STACK-UNDERFLOW?, ACCESS-VIOLATION?, MISALIGNED-ADDRESS?.

(Memory-transparency = 1 allows you to write to underlying RAM as opposed to mapped I/O or ROM)
(ROM-protect = 1 prevents the ROM chip from being written to)
(Stack-size = determines whether that stack sould be 1KB or 8KB large)
(Stack-overflow = Bit is set if the stack counter overflows and STAYS ON until it is acknowledged/reset)

NEW FLAGS REGISTER:

[CF]	Carry
[ZF]	Zero
[SF]	Sign
[PF]	Parity
[OF]	Overflow
[TF]	Trap/Single Step
[WF]	Write Protect
[IF]	Interrupt Enable

Registers: 4 GENERAL PURPOSE (2x8b), PROG-COUNT (16b), STACK-POINTER [NEG-COUNTER] (10b-13b), BASE-POINTER (10b-13b), FLAGS (16b?).

NAH: --have dip switches on the board that determine how much ram is installed... the dip switches can act as a byte in memory.--

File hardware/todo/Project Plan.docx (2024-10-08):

1. CPU Internal Circuitry
  a. Write out desired specifications
  b. Lay out memory map
  c. Design all the components (logically only)
  d. Specify a standard external bus to connect the parts
  e. Add electrical parts to all the components (resistors, capacitors, etc)
  f. CAD up schematics for the CPU
  g. Test all components of breadboards and make changes as necessary
  h. Once all working, CAD up PCB layouts for all the components
  i. Etch/order the PCBs and assemble the components
2. Building Cases/Hardware
  a. Design the backplane (both electrically and physically, dimensions etc)
  b. Design front panel (the actual buttons etc, the controller is a component above)
  c. Design and CAD the case (including front panel and port holes)
  d. Build the case (from a metal net and wood)
3. Computer/External/Expansion Devices
  a. Design all the devices (logically only)
  b. Add electrical parts to the devices
  c. CAD up schematics for the devices
  d. Test all the devices on breadboards and make changes as necessary
  e. Once all working, CAD up PCB layouts for the devices
  f. Etch the PCBs and assemble the devices
4. Programming Software
  a. Write some basic programs or a monitor to test/demo the machine (can continue to randomly write programs as this list is progressed through)
  b. Assembler coded in Python (runs on a PC/Mac instead of the machine)
  c. Data Loaders (cassette loader, floppy loader, serial loader)
  d. Resident Monitor (lives in ROM, like the Turnkey 8800)
  e. Simple BIOS (just some elementary system calls and routines or whatever)
  f. BASIC Programming Language (in ROM, like 4K BASIC)
  g. Compiler for a High-Level Language in another HLL (such as C or FORTRAN)
  h. Disk Operating System (the big kahuna, like Altair DOS)
5. Writing Manuals
  a. Leaflets
  b. Introductory/Setup Guide
  c. Programming Guide
  d. Technical Reference
  e. BASIC User Guide, Monitor Guide, DOS User Guide

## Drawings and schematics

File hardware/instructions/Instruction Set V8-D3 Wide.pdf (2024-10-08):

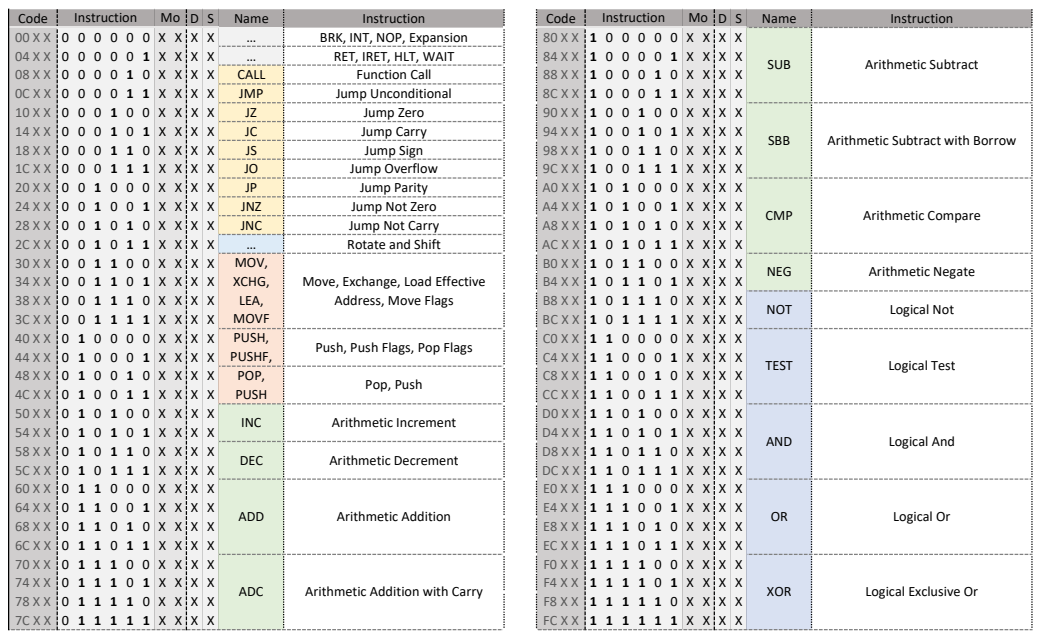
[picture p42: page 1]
Code; Name; Instruction; BRK, INT, NOP, Expansion; RET, IRET, HLT, WAIT; CALL; Function Call; JMP; Jump Unconditional; Jump Zero; Jump Carry; Jump Sign; Jump Overflow; Jump Parity; JNZ; Jump Not Zero; JNC; Jump Not Carry; Rotate and Shift; SUB; Arithmetic Subtract; SBB; Arithmetic Subtract with Borrow; CMP; Arithmetic Compare; NEG; Arithmetic Negate; XOR; Logical Exclusive Or; Logical Or; AND; Logical And; NOT; Logical Not; TEST; Logical Test; DEC; Arithmetic Decrement; ADC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

Move, Exchange, Load Effective
Address, Move Flags

Push, Push Flags, Pop Flags

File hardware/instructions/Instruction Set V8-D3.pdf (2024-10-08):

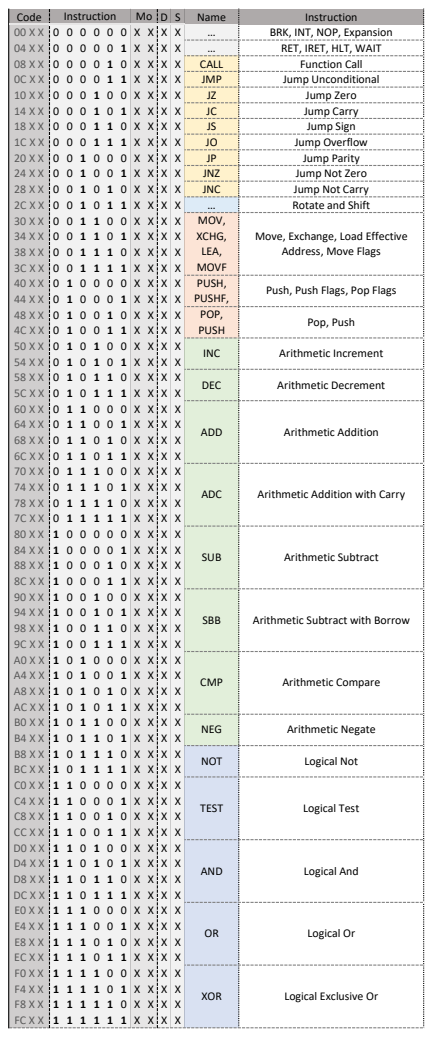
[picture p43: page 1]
Code; D S Name; Instruction; BRK, INT, NOP, Expansion; RET, IRET, HLT, WAIT; CALL; Function Call; JMP; Jump Unconditional; Jump Zero; Jump Carry; Jump Sign; Jump Overflow; Jump Parity; JNZ; Jump Not Zero; JNC; Jump Not Carry; Rotate and Shift; DEC; Arithmetic Decrement; Logical Or; ADC; Arithmetic Addition with Carry; AND; Logical And; TEST; Logical Test; CMP; Arithmetic Compare; XOR; Logical Exclusive Or; ADD; Arithmetic Addition; INC; Arithmetic Increment; SUB; Arithmetic Subtract; SBB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

Move, Exchange, Load Effective
Address, Move Flags

Push, Push Flags, Pop Flags

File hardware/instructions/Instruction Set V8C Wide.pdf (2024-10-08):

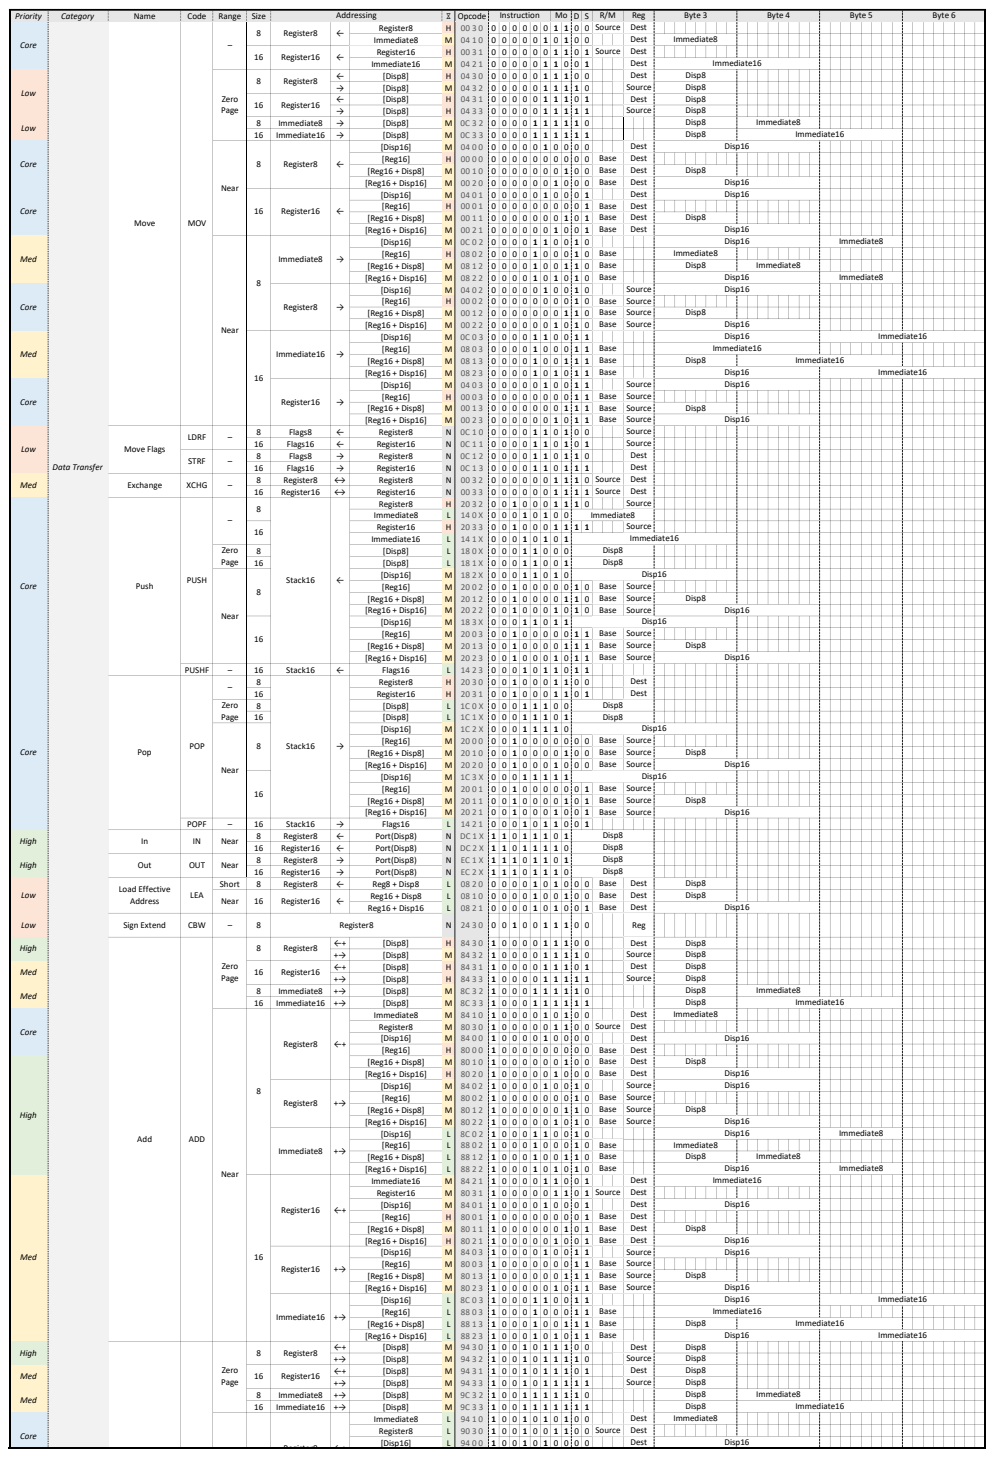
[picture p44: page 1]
Priority; Category; Name; Code Range Size; ⧖ Opcode; Register8; Immediate8; Register16; Immediate16; [Disp8]; 16 Immediate16 →; [Disp16]; [Reg16]; [Reg16 + Disp8]; [Reg16 + Disp16]; Flags8; Flags16; PUSHF; Stack16; POPF; Port(Disp8); Short; Reg8 + Disp8; Reg16 + Disp8; Reg16 + Disp16; Low; Sign Extend; CBW; Immediate8 +→; 16 Immediate16 +→; Med; Disp8; Core; Source; Dest; High; Zero Page; 8 Register8; Disp16; Immediate16 +→; Base; Base Source Base; Source Dest Dest; Base Source; Near; Reg; Add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

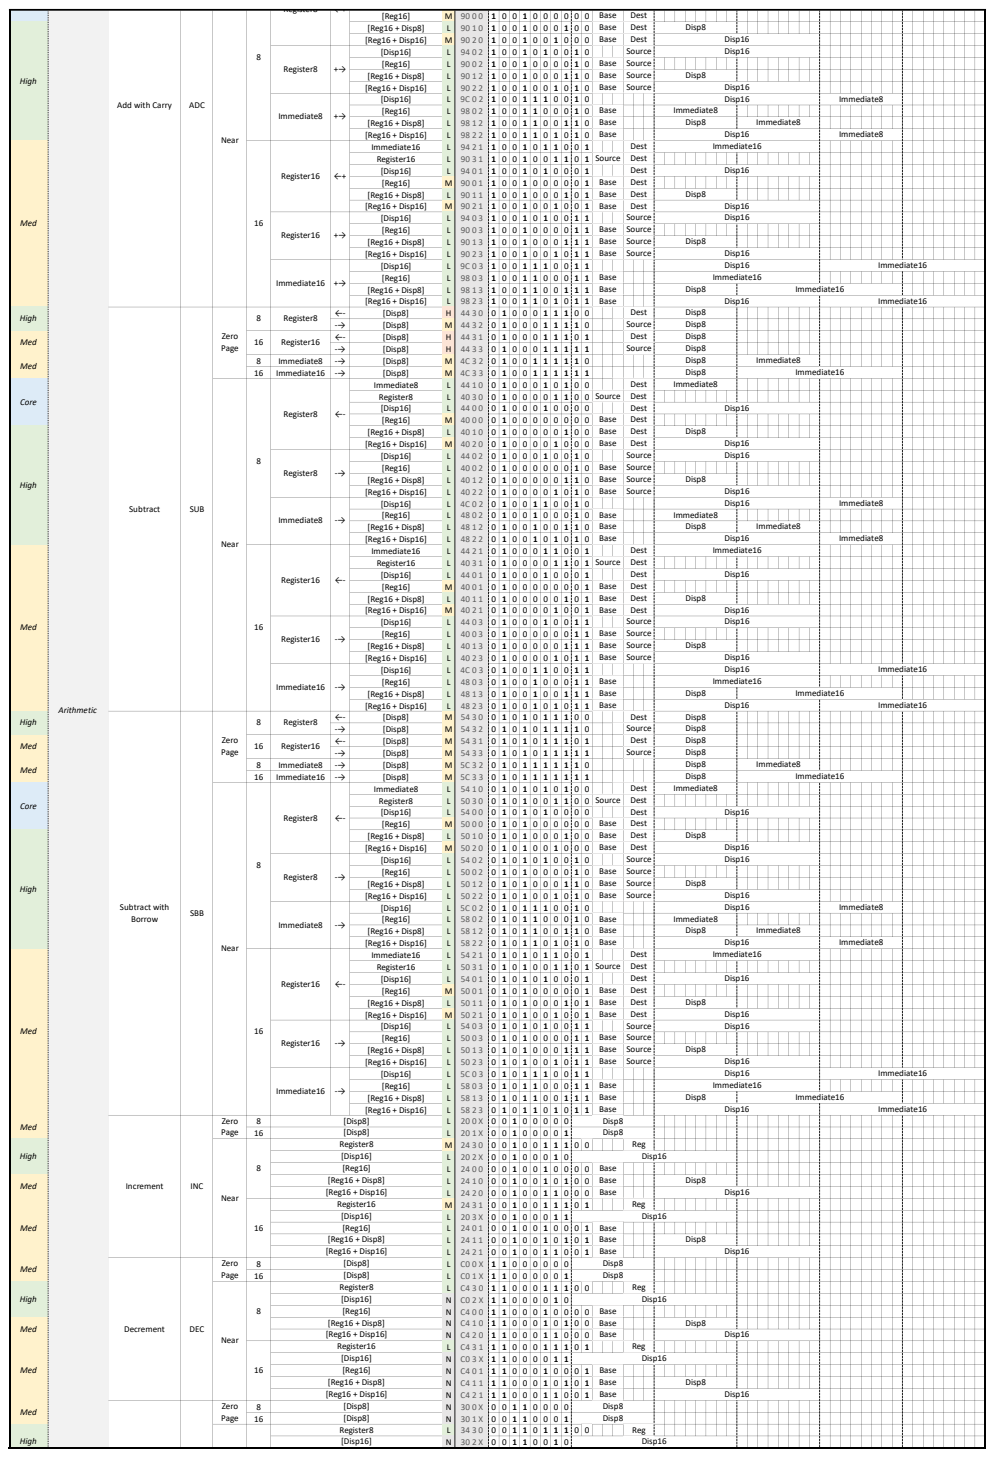
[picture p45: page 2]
[Reg16]; [Reg16 + Disp8]; [Reg16 + Disp16]; [Disp16]; Immediate16; Register16; [Disp8]; Immediate8 -→; 16 Immediate16 -→; Immediate8; Register8; Disp8; High; Reg; Med; Zero; Page; Disp16; Base; Near; Decrement; DEC; Zero Page; Increment; INC; Source; Base Source; Immediate16 -→; Dest; Base Source Base; Source Dest; Core; Subtract with Borrow; SBB; 8 Register8; Immediate16 +→; Subtract; SUB; Immediate8 +→; Add with Carry; ADC; Arithmetic

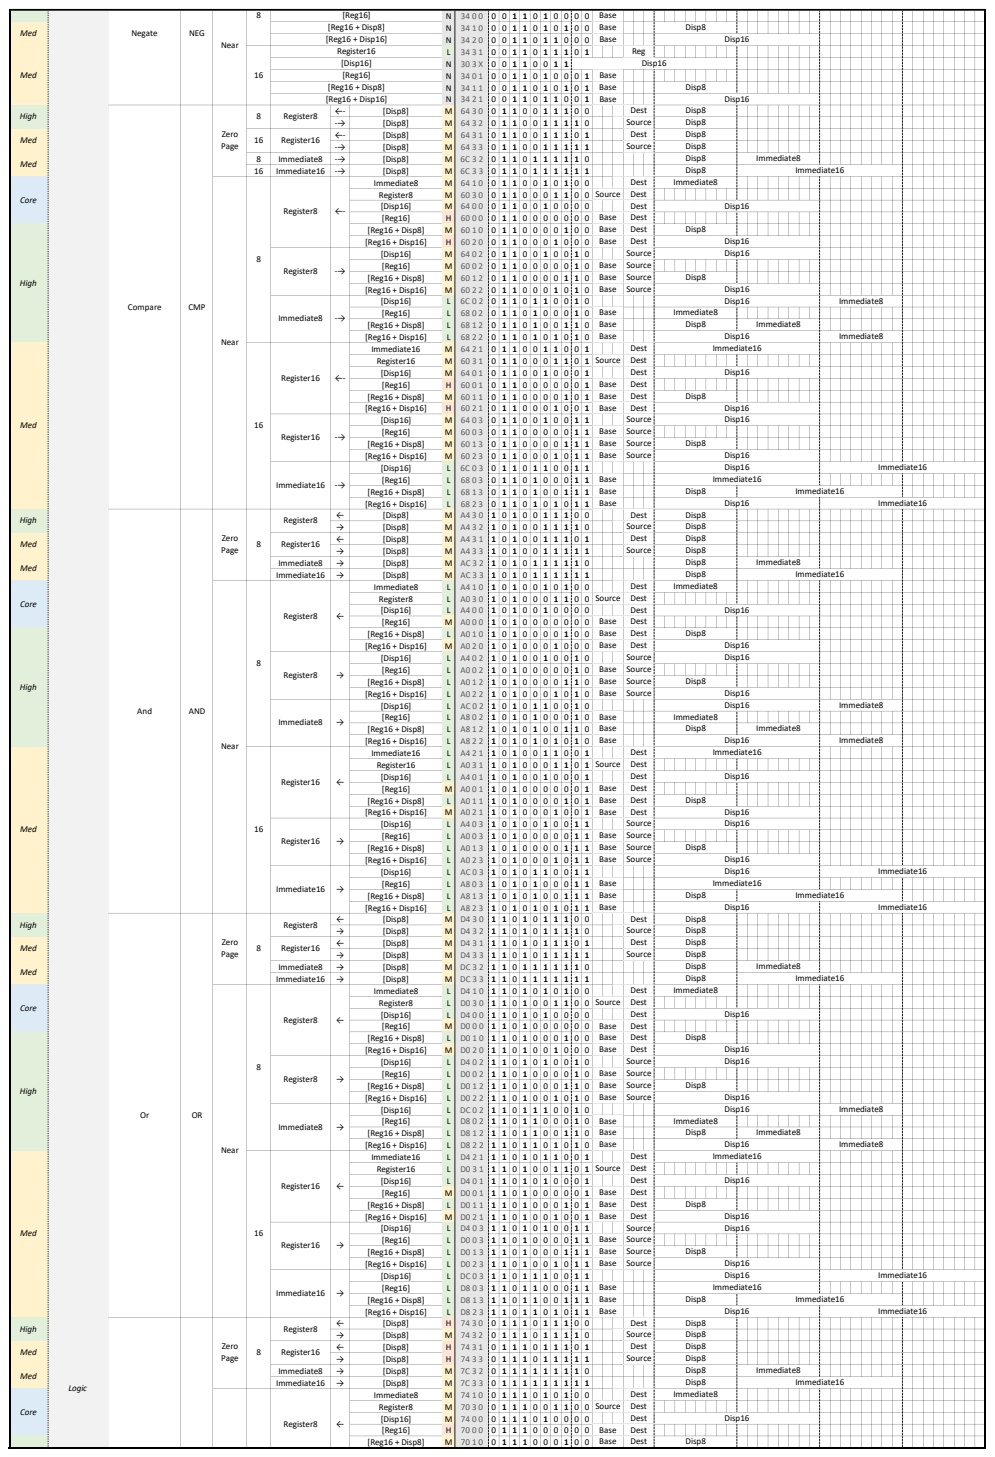
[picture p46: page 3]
[Disp8]; Immediate8 -→; 16 Immediate16 -→; Immediate8; Register8; [Disp16]; [Reg16]; [Reg16 + Disp8]; [Reg16 + Disp16]; Immediate16; Register16; Immediate16 →; Dest; Core; Source; Disp8; Med; Base; Source Dest; Disp16; High; Zero Page; Base Source; Base Source Base; Source Dest Dest; Near; Logic; And; AND; Compare; CMP; 8 Register8; Negate; NEG; Reg

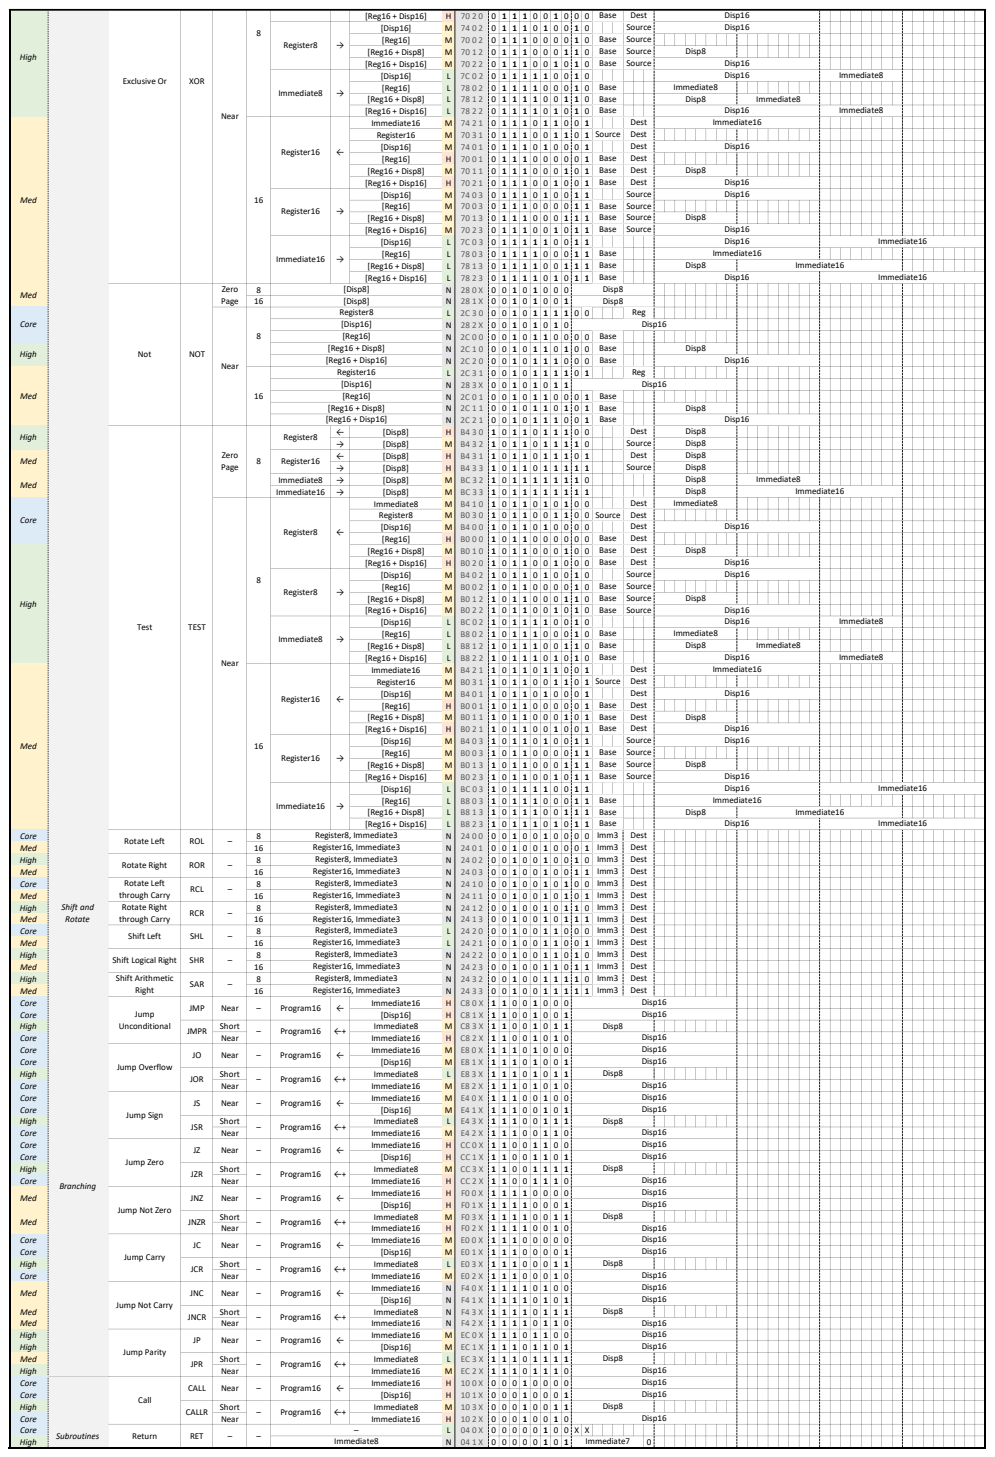
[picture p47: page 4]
[Reg16 + Disp16]; [Disp16]; [Reg16]; [Reg16 + Disp8]; Immediate16; Register16; [Disp8]; Immediate8; Immediate16 →; Register8; Core; Med; High; Short; Near; Subroutines; Immediate7; Disp16; Return; RET; Disp16 Disp16; CALLR; Program16 ←+; Disp8; Call; CALL; Program16; JPR; Jump Parity; JNCR; JNC; JCR; Jump Carry; JNZR; JNZ; Jump Overflow; JZR; Jump Zero; JSR; JMPR; Branching; Jump Unconditional; JMP; Jump Sign; JOR; Register16, Immediate3; Imm3 Dest; Dest; Shift Arithmetic; Right; SAR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

Jump Not Zero

Jump Not Carry

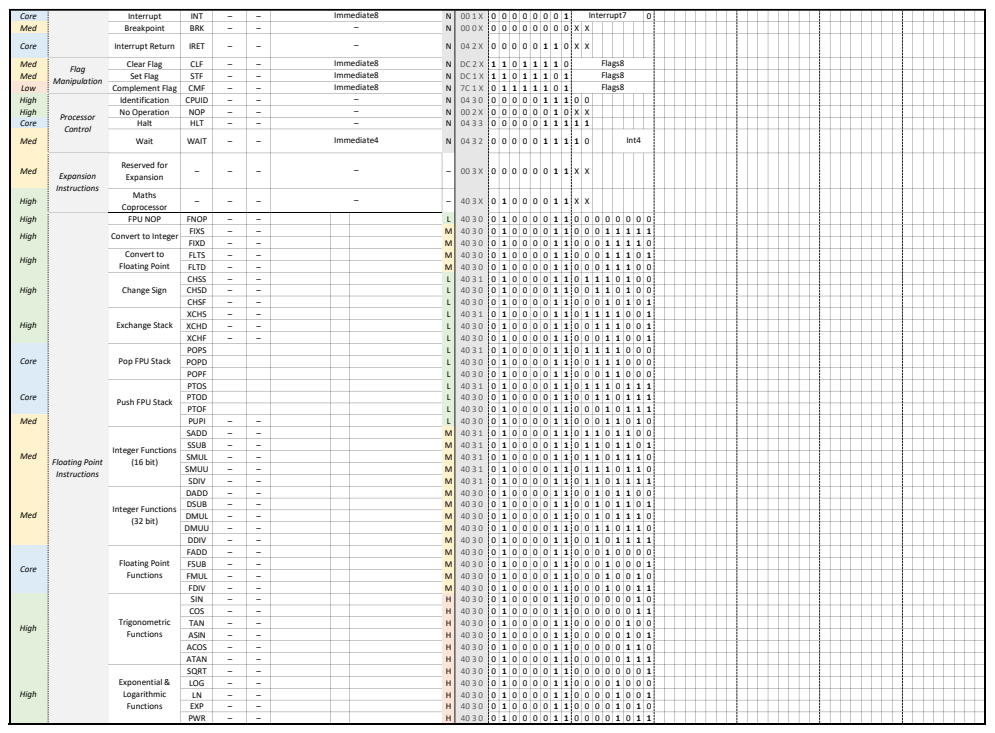
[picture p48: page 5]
Core; Interrupt; INT; Med; Breakpoint; BRK; Interrupt Return; IRET; Clear Flag; CLF; Set Flag; STF; Low; Complement Flag CMF; High; Identification; CPUID; No Operation; NOP; Halt; HLT; Wait; WAIT; Reserved for; Expansion; Maths; Coprocessor; FPU NOP; FNOP; FIXS; FIXD; FLTS; FLTD; CHSS; CHSD; CHSF; XCHS; XCHD; XCHF; POPS; POPD; POPF; PTOS; PTOD; PTOF; PUPI; SADD; SSUB; SMUL; SMUU; SDIV; DADD; DSUB; DMUL; DMUU; DDIV; FADD; FSUB; FMUL; FDIV; SIN; COS; TAN; ASIN; ACOS; ATAN; SQRT; LOG; EXP; PWR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

Convert to Integer
Convert to
Floating Point

Pop FPU Stack

Push FPU Stack

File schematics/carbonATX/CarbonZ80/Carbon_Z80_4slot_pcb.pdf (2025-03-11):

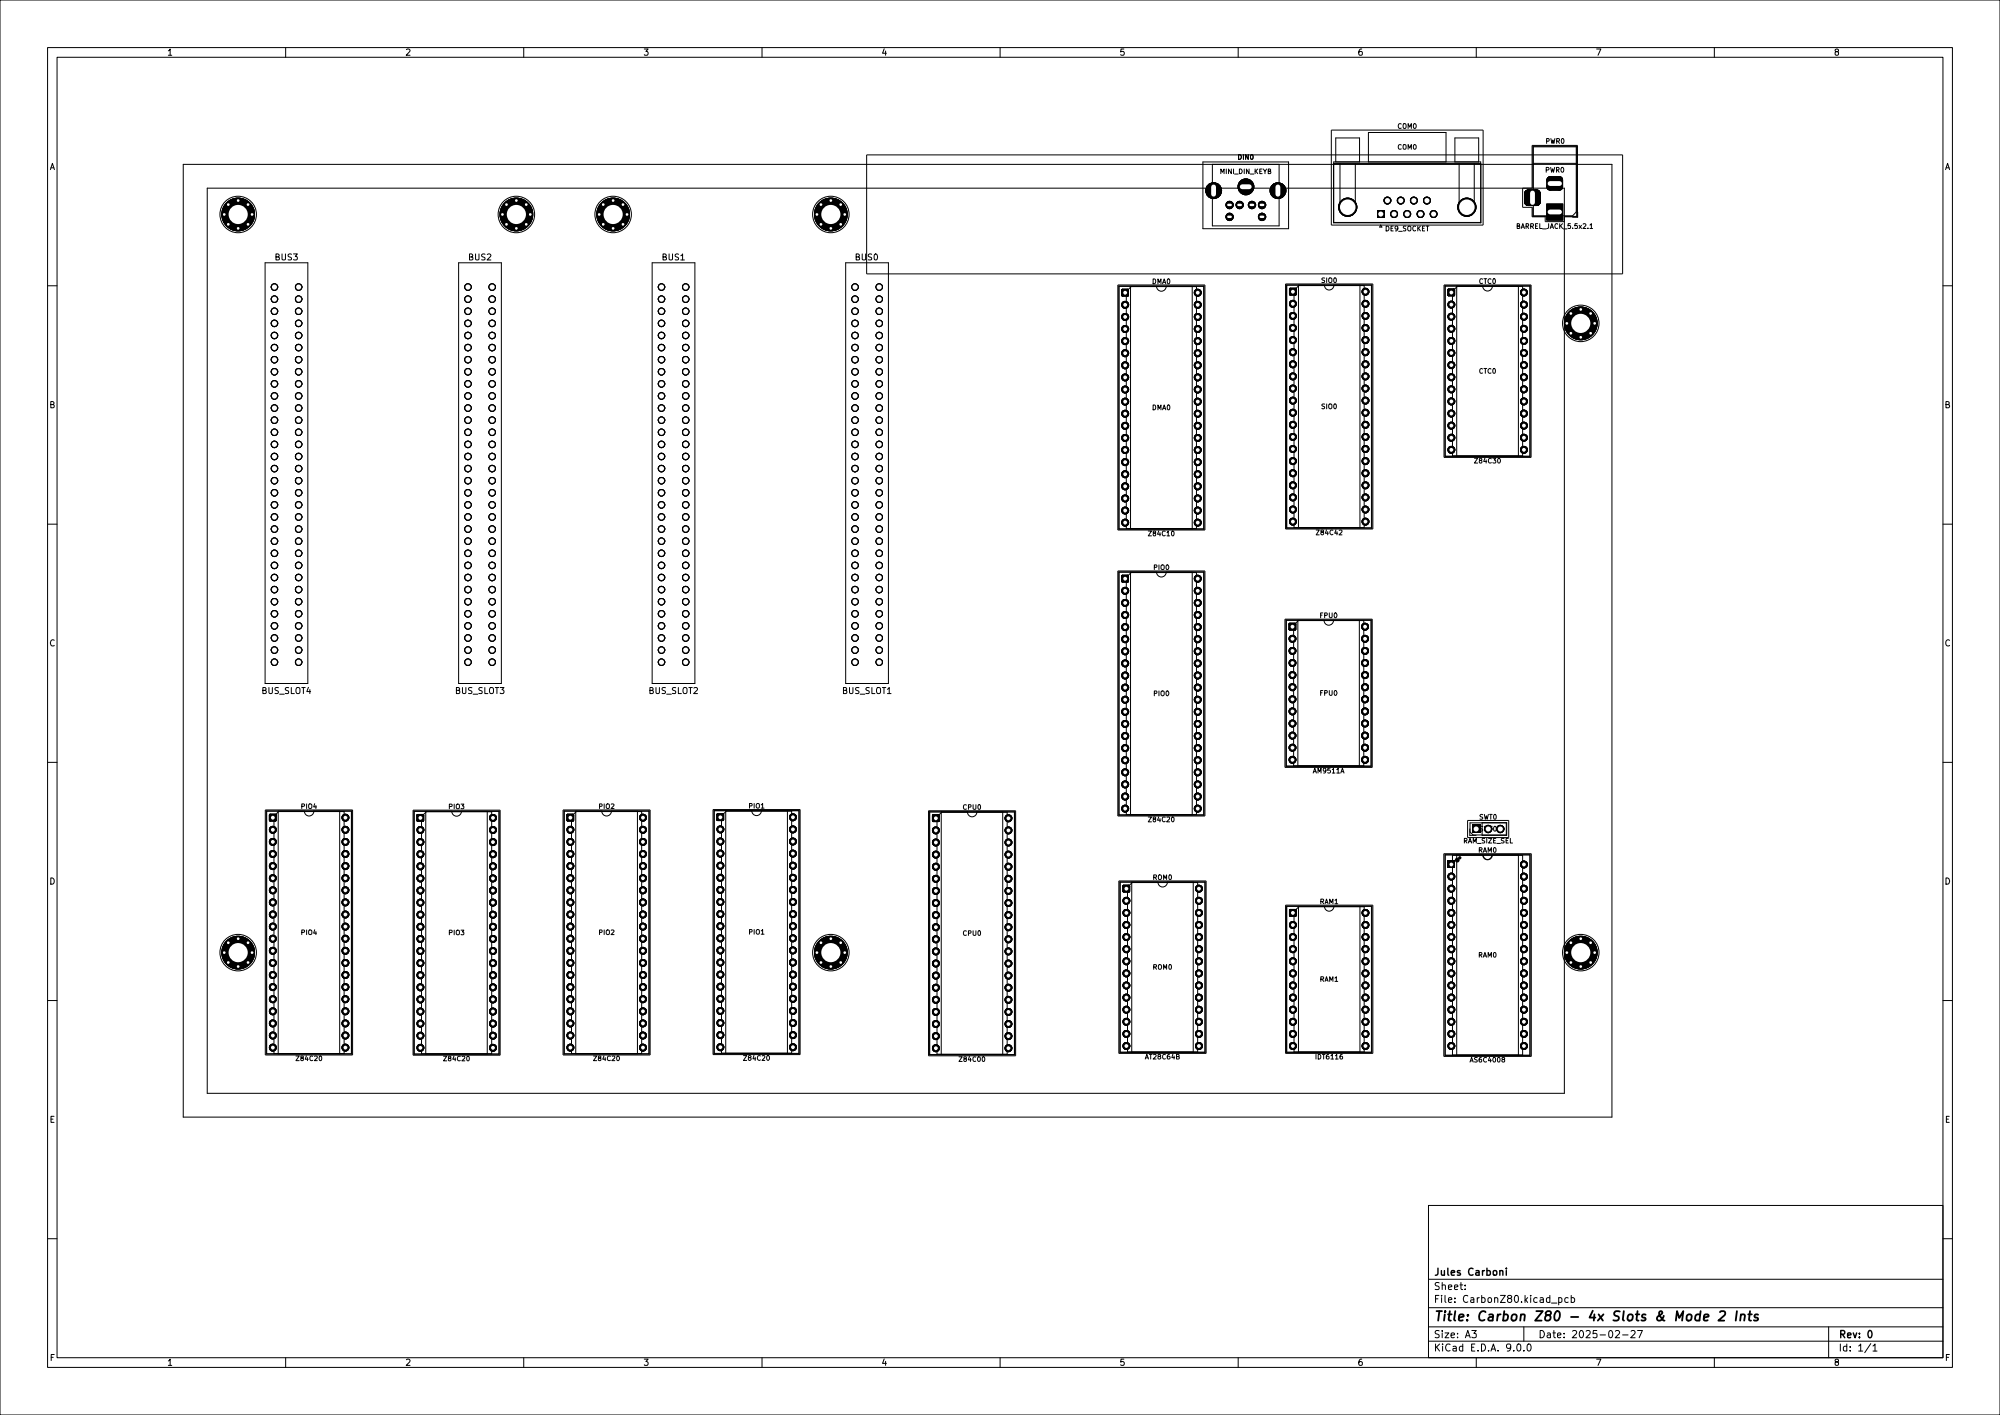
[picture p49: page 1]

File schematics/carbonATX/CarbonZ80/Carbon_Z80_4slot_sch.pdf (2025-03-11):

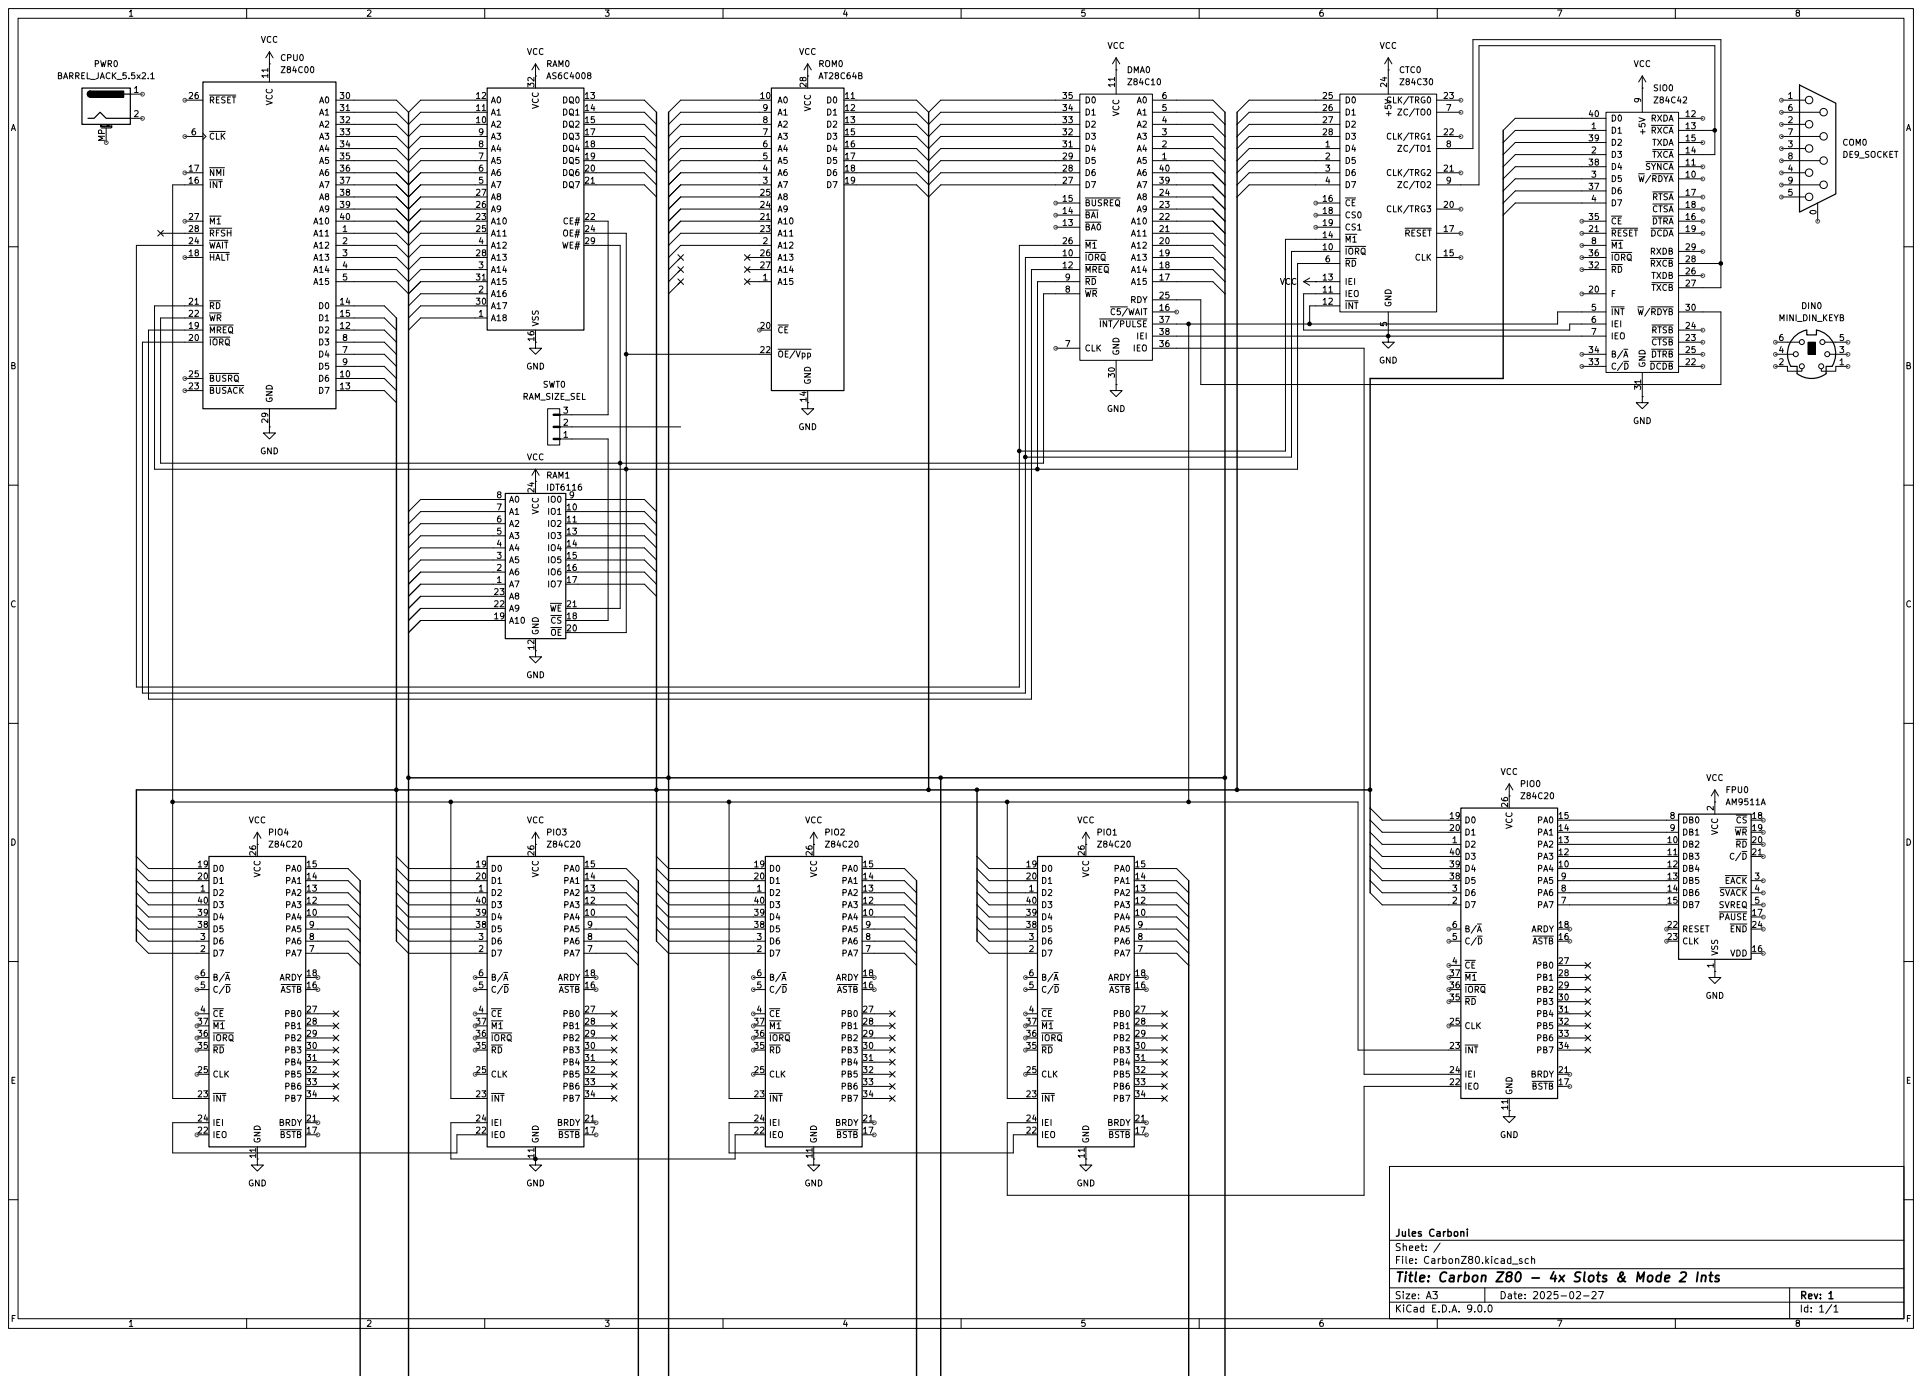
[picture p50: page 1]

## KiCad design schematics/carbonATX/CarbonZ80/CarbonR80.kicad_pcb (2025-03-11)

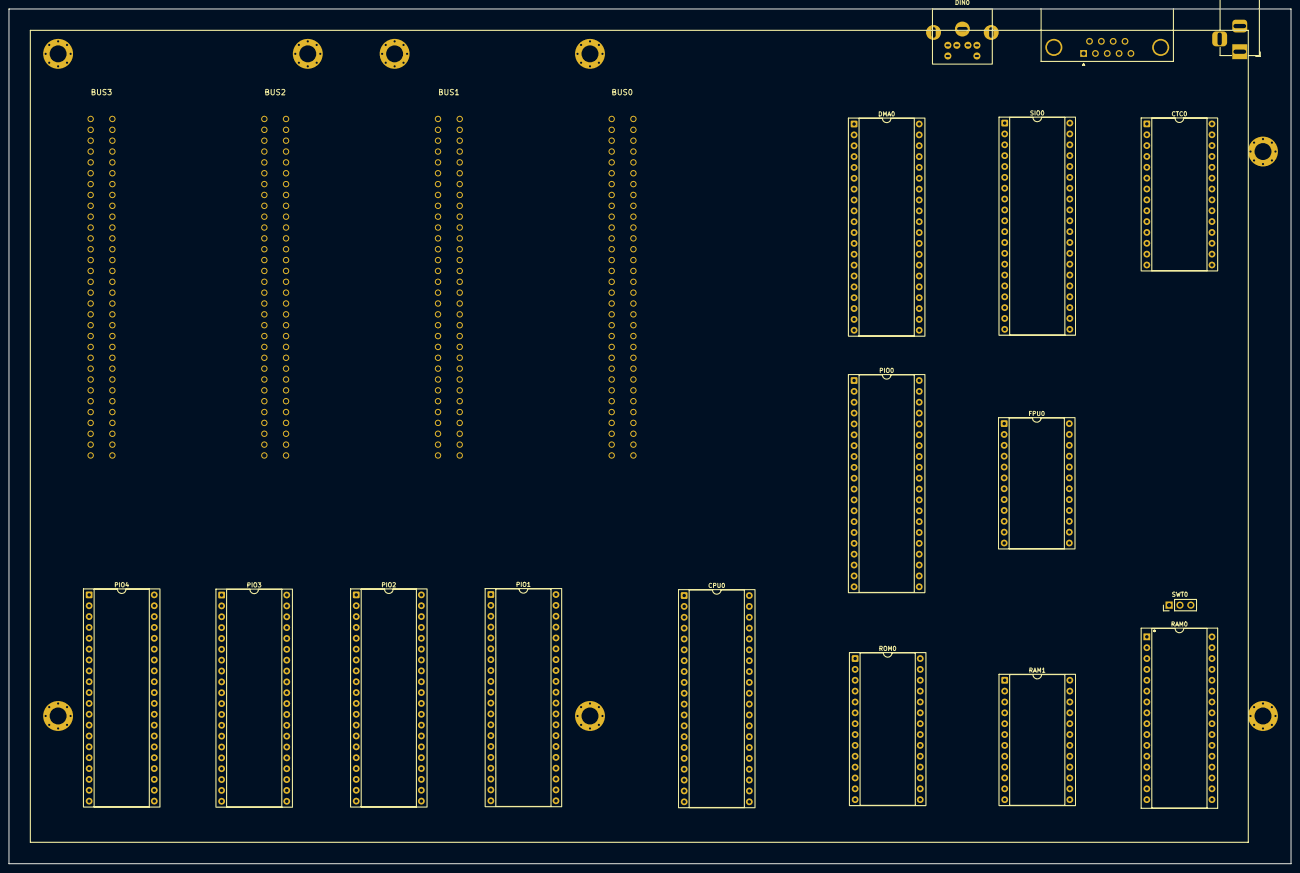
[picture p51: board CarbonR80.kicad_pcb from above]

Board: 2 copper layers, 300.0 x 200.0 mm, 21 parts (0 on the bottom side), 26 nets, no tracks yet.

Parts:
BUS0: BUS_SLOT1; 8bISA_64pin
BUS1: BUS_SLOT2; 8bISA_64pin
BUS2: BUS_SLOT3; 8bISA_64pin
BUS3: BUS_SLOT4; 8bISA_64pin
COM0: DE9_SOCKET; DSUB-9_Socket_Horizontal_P2.77x2.84mm_EdgePinOffset7.70mm_H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
CPU0: Z84C00; DIP-40_W15.24mm_Socket
CTC0: Z84C30; DIP-28_W15.24mm_Socket
DIN0: MINI_DIN_KEYB; Mini_DIN_6
DMA0: Z84C10; DIP-40_W15.24mm_Socket
FPU0: AM9511A; DIP-24_W15.24mm_Socket
PIO0, PIO1, PIO2, PIO3, PIO4: Z84C20; DIP-40_W15.24mm_Socket
PWR0: BARREL_JACK_5.5x2.1; BarrelJack_Horizontal
RAM0: AS6C4008; DIP-32_W15.24mm_Socket
RAM1: IDT6116; DIP-24_W15.24mm_Socket
ROM0: AT28C64B; DIP-28_W15.24mm_Socket
SIO0: Z84C42; DIP-40_W15.24mm_Socket
SWT0: RAM_SIZE_SEL; PinHeader_1x03_P2.54mm_Vertical

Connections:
GND: CPU0.29 (GND), CTC0.5 (GND), DMA0.30 (GND), DMA0.38 (IEI), FPU0.1 (VSS), PIO0.11 (GND), PIO1.11 (GND), PIO2.11 (GND), PIO2.22 (IEO), PIO3.11 (GND), PIO3.24 (IEI), PIO4.11 (GND), RAM0.16 (VSS), RAM1.12 (GND), ROM0.14 (GND), SIO0.7 (IEO), SIO0.31 (GND)
unnamed: CPU0.16 (~INT), CTC0.12 (~INT), DMA0.37 (~INT/PULSE), PIO0.23 (~INT), PIO1.23 (~INT), PIO2.23 (~INT), PIO3.23 (~INT), PIO4.23 (~INT), SIO0.5 (~INT)
unnamed: CPU0.20 (~IORQ), CTC0.10 (~IORQ), DMA0.10 (~IORQ)
unnamed: CPU0.19 (~MREQ), DMA0.12 (~MREQ)
unnamed: CPU0.21 (~RD), CTC0.6 (~RD), DMA0.9 (~RD), RAM0.24 (OE#), RAM1.20 (~OE), ROM0.22 (~OE/Vpp)
unnamed: CPU0.24 (~WAIT), CTC0.14 (~M1), DMA0.26 (~M1)
unnamed: CPU0.22 (~WR), DMA0.8 (~WR), RAM0.29 (WE#), RAM1.21 (~WE)
unnamed: CTC0.11 (IEO), SIO0.6 (IEI)
unnamed: CTC0.8 (ZC/TO1), SIO0.27 (~TXCB), SIO0.28 (~RXCB)
unnamed: CTC0.9 (ZC/TO2), SIO0.13 (~RXCA), SIO0.14 (~TXCA)
unnamed: DMA0.36 (IEO), PIO0.24 (IEI)
unnamed: DMA0.25 (RDY), SIO0.30 (~W/~RDYB)
unnamed: FPU0.8 (DB0), PIO0.15 (PA0)
unnamed: FPU0.9 (DB1), PIO0.14 (PA1)
unnamed: FPU0.10 (DB2), PIO0.13 (PA2)
unnamed: FPU0.11 (DB3), PIO0.12 (PA3)
unnamed: FPU0.12 (DB4), PIO0.10 (PA4)
unnamed: FPU0.13 (DB5), PIO0.9 (PA5)
unnamed: FPU0.14 (DB6), PIO0.8 (PA6)
unnamed: FPU0.15 (DB7), PIO0.7 (PA7)
unnamed: PIO0.22 (IEO), PIO1.24 (IEI)
unnamed: PIO1.22 (IEO), PIO2.24 (IEI)
unnamed: PIO3.22 (IEO), PIO4.24 (IEI)
unnamed: RAM0.22 (CE#), SWT0.3
unnamed: RAM1.18 (~CS), SWT0.1
VCC: CPU0.11 (VCC), CTC0.13 (IEI), CTC0.24 (+5V), DMA0.11 (VCC), FPU0.2 (VCC), PIO0.26 (VCC), PIO1.26 (VCC), PIO2.26 (VCC), PIO3.26 (VCC), PIO4.26 (VCC), RAM0.32 (VCC), RAM1.24 (VCC), ROM0.28 (VCC), SIO0.9 (+5V)

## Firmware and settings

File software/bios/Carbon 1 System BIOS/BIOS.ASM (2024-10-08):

$TITLE(BIOS FOR CARBON 1 MINI-COMPUTER)

;----------------------------------------------------------------
;	CARBON 1 MINICOMPUTER SYSTEM BIOS	        	:
;----------------------------------------------------------------
;	PROGRAM:	CARBON SYSTEM BIOS			:
;	AUTHOR:		JULES CARBONI				:
;	CREATED:	15 JAN 2024				:
;	MODIFIED:	15 JAN 2024 (JULES CARBONI)		:
;	INSPIRATION:	IBM PC BIOS (VERSION 3) (27 OCT 1981)	:
;----------------------------------------------------------------

;----------------------------------------------------------------
;	THE  BIOS ROUTINES ARE MEANT TO BE ACCESSED THROUGH	:
;	SOFTWARE INTERRUPTS ONLY.  ANY ADDRESSES PRESENT IN	:
;	THE LISTINGS  ARE INCLUDED  ONLY FOR  COMPLETENESS,	:
;	NOT FOR  REFERENCE.   APPLICATIONS WHICH  REFERENCE	:
;	ABSOLUTE   ADDRESSES   WITHIN	THE  CODE   SEGMENT	:
;	VIOLATE THE STRUCTURE AND DESIGN OF BIOS.		:
;----------------------------------------------------------------

;----------------------------------------
;		EQUATES 		:
;----------------------------------------
PORT_A		EQU	60H		; 8255 PORT A ADDR
PORT_B		EQU	61H		; 8255 PORT B ADDR
PORT_C		EQU	62H		; 8255 PORT C ADDR
CMD_PORT	EQU	63H
INTA00		EQU	20H		; 8259 PORT
INTA01		EQU	21H		; 8259 PORT
EOI		EQU	20H
TIMER		EQU	40H
TIM_CTL 	EQU	43H		; 8253 TIMER CONTROL PORT ADDR
TIMER0		EQU	40H		; 8253 TIMER/CNTER 0 PORT ADDR
TMINT		EQU	01		; TIMER 0 INTR RECVD MASK
DMA08		EQU	08		; DMA STATUS REG PORT ADDR
DMA		EQU	00		; DMA CHANNEL 0 ADDRESS REG PORT ADDR
MAX_PERIOD	EQU	540H
MIN_PERIOD	EQU	410H
KBD_IN		EQU	60H		; KEYBOARD DATA IN ADDR PORT
KBDINT		EQU	02		; KEYBOARD INTR MASK
KB_DATA 	EQU	60H		; KEYBOARD SCAN CODE PORT
KB_CTL		EQU	61H		; CONTROL BITS FOR KEYBOARD SENSE DATA
;----------------------------------------
;	8088 INTERRUPT LOCATIONS	:
;----------------------------------------
ABS0		SEGMENT AT 0
STG_LOC0	LABEL	BYTE
		ORG	2*4
NMI_PTR 	LABEL	WORD
		ORG	5*4
INT5_PTR	LABEL	WORD
		ORG	8*4
INT_ADDR	LABEL	WORD
INT_PTR 	LABEL	DWORD
		ORG	10H*4
VIDEO_INT	LABEL	WORD
		ORG	1DH*4
PARM_PTR	LABEL	DWORD		; POINTER TO VIDEO PARMS
		ORG	18H*4
BASIC_PTR	LABEL	WORD		; ENTRY POINT FOR CASSETTE BASIC
		ORG	01EH*4		; INTERRUPT 1EH
DISK_POINTER	LABEL	DWORD
		ORG	01FH*4		; LOCATION OF POINTER
EXT_PTR LABEL	DWORD			; POINTER TO EXTENSION
		ORG	040H*4		; ROUTINE
IO_ROM_INIT	DW	?		;
IO_ROM_SEG	DW	?		; OPTIONAL ROM SEGMENT
		ORG	400H
DATA_AREA	LABEL	BYTE		; ABSOLUTE LOCATION OF DATA SEGMENT
DATA_WORD	LABEL	WORD
		ORG	7C00H
BOOT_LOCN	LABEL	FAR
ABS0		ENDS

;--------------------------------------------------------
;	STACK -- USED DURING INITIALIZATION ONLY	:
;--------------------------------------------------------
STACK		SEGMENT AT 30H
		DW	128 DUP(?)
TOS		LABEL	WORD
STACK		ENDS

;----------------------------------------
;	 ROM BIOS DATA AREAS		:
;----------------------------------------
DATA		SEGMENT AT 40H
RS232_BASE	DW	4 DUP(?)	; ADDRESSES OF RS232 ADAPTERS
PRINTER_BASE	DW	4 DUP(?)	; ADDRESSES OF PRINTERS
EQUIP_FLAG	DW	?		; INSTALLED HARDWARE
MFG_TST 	DB	?		; INITIALIZATION FLAG
MEMORY_SIZE	DW	?		; MEMORY SIZE IN K BYTES
IO_RAM_SIZE	DW	?		; MEMORY IN I/O CHANNEL
;----------------------------------------
;	   KEYBOARD DATA AREAS		:
;----------------------------------------
KB_FLAG 	DB	?

;----- SHIFT FLAG EQUATES WITHIN KB_FLAG

INS_STATE	EQU	80H		; INSERT STATE IS ACTIVE
CAPS_STATE	EQU	40H		; CAPS LOCK STATE HAS BEEN TOGGLED
NUM_STATE	EQU	20H		; NUM LOCK STATE HAS BEEN TOGGLED
SCROLL_STATE	EQU	10H		; SCROLL LOCK STATE HAS BEEN TOGGLED
ALT_SHIFT	EQU	08H		; ALTERNATE SHIFT KEY DEPRESSED
CTL_SHIFT	EQU	04H		; CONTROL SHIFT KEY DEPRESSED
LEFT_SHIFT	EQU	02H		; LEFT SHIFT KEY DEPRESSED
RIGHT_SHIFT	EQU	01H		; RIGHT SHIFT KEY DEPRESSED

KB_FLAG_1	DB	?		; SECOND BYTE OF KEYBOARD STATUS

INS_SHIFT	EQU	80H		; INSERT KEY IS DEPRESSED
CAPS_SHIFT	EQU	40H		; CAPS LOCK KEY IS DEPRESSED
NUM_SHIFT	EQU	20H		; NUM LOCK KEY IS DEPRESSED
SCROLL_SHIFT	EQU	10H		; SCROLL LOCK KEY IS DEPRESSED
HOLD_STATE	EQU	08H		; SUSPEND KEY HAS BEEN TOGGLED

ALT_INPUT	DB	?		; STORAGE FOR ALTERNATE KEYPAD ENTRY
BUFFER_HEAD	DW	?		; POINTER TO HEAD OF KEYBOARD BUFFER
BUFFER_TAIL	DW	?		; POINTER TO TAIL OF KEYBOARD BUFFER
KB_BUFFER	DW	16 DUP(?)	; ROOM FOR 15 ENTRIES
KB_BUFFER_END	LABEL	WORD

;----- HEAD = TAIL INDICATES THAT THE BUFFER IS EMPTY

NUM_KEY 	EQU	69		; SCAN CODE FOR NUMBER LOCK
SCROLL_KEY	EQU	70		; SCROLL LOCK KEY
ALT_KEY 	EQU	56		; ALTERNATE SHIFT KEY SCAN CODE
CTL_KEY 	EQU	29		; SCAN CODE FOR CONTROL KEY
CAPS_KEY	EQU	58		; SCAN CODE FOR SHIFT LOCK
LEFT_KEY	EQU	42		; SCAN CODE FOR LEFT SHIFT
RIGHT_KEY	EQU	54		; SCAN CODE FOR RIGHT SHIFT
INS_KEY 	EQU	82		; SCAN CODE FOR INSERT KEY
DEL_KEY 	EQU	83		; SCAN CODE FOR DELETE KEY

;----------------------------------------
;	DISKETTE DATA AREAS		:
;----------------------------------------
SEEK_STATUS	DB	?		; DRIVE RECALIBRATION STATUS
;				BIT 3-0 = DRIVE 3-0 NEEDS RECAL BEFORE
;					  NEXT SEEK IF BIT IS = 0
INT_FLAG	EQU	080H		; INTERRUPT OCCURRENCE FLAG
MOTOR_STATUS	DB	?		; MOTOR STATUS
;				BIT 3-0 = DRIVE 3-0 IS CURRENTLY RUNNING
;				BIT 7	= CURRENT OPERATION IS A WRITE, REQUIRES DELAY
MOTOR_COUNT	DB	?		; TIME OUT COUNTER FOR DRIVE TURN OFF
MOTOR_WAIT	EQU	37		; TWO SECONDS OF COUNTS FOR MOTOR TURN OFF

DISKETTE_STATUS DB	?		; SINGLE BYTE OF RETURN CODE INFO FOR STATUS
TIME_OUT	EQU	80H		; ATTACHMENT FAILED TO RESPOND
BAD_SEEK	EQU	40H		; SEEK OPERATION FAILED
BAD_NEC 	EQU	20H		; NEC CONTROLLER HAS FAILED
BAD_CRC 	EQU	10H		; BAD CRC ON DISKETTE READ
DMA_BOUNDARY	EQU	09H		; ATTEMPT TO DMA ACROSS 64K BOUNDARY
BAD_DMA 	EQU	08H		; DMA OVERRUN ON OPERATION
RECORD_NOT_FND	EQU	04H		; REQUESTED SECTOR NOT FOUND
WRITE_PROTECT	EQU	03H		; WRITE ATTEMPTED ON WRITE PROT DISK
BAD_ADDR_MARK	EQU	02H		; ADDRESS MARK NOT FOUND
BAD_CMD 	EQU	01H		; BAD COMMAND PASSED TO DISKETTE I/O

NEC_STATUS	DB	7 DUP(?)	; STATUS BYTES FROM NEC

;----------------------------------------
;	VIDEO DISPLAY DATA AREA 	:
;----------------------------------------
CRT_MODE	DB	?		; CURRENT CRT MODE
CRT_COLS	DW	?		; NUMBER OF COLUMNS ON SCREEN
CRT_LEN 	DW	?		; LENGTH OF REGEN IN BYTES
CRT_START	DW	?		; STARTING ADDRESS IN REGEN BUFFER
CURSOR_POSN	DW	8 DUP(?)	; CURSOR FOR EACH OF UP TO 8 PAGES
CURSOR_MODE	DW	?		; CURRENT CURSOR MODE SETTING
ACTIVE_PAGE	DB	?		; CURRENT PAGE BEING DISPLAYED
ADDR_6845	DW	?		; BASE ADDRESS FOR ACTIVE DISPLAY CARD
CRT_MODE_SET	DB	?		; CURRENT SETTING OF THE 3X8 REGISTER
CRT_PALETTE	DB	?		; CURRENT PALETTE SETTING COLOR CARD

;----------------------------------------
;	   CASSETTE DATA AREA		:
;----------------------------------------
EDGE_CNT	DW	?		; TIME COUNT AT DATA EDGE
CRC_REG 	DW	?		; CRC REGISTER
LAST_VAL	DB	?		; LAST INPUT VALUE

;----------------------------------------
;	    TIMER DATA AREA		:
;----------------------------------------
TIMER_LOW	DW	?		; LOW WORD OF TIMER COUNT
TIMER_HIGH	DW	?		; HIGH WORD OF TIMER COUNT
TIMER_OFL	DB	?		; TIMER HAS ROLLED OVER SINCE LAST READ
;COUNTS_SEC	EQU	18
;COUNTS_MIN	EQU	1092
;COUNTS_HOUR	EQU	65543
;COUNTS_DAY	EQU	1573040 = 1800B0H
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

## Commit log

2024-10-08 moved files around
    [Addressing Modes.xlsx, Binary File Format.xlsx, CDA Technical - TEMP PRINT.xlsx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]
2024-10-31 Update CDA Technical.xlsx
    [CDA Technical.xlsx]
2024-10-31 UPDATED VIDEO RESOLUTIONS
    [CDA Technical.xlsx]
2025-01-28 Add files via upload
    Version 5V, supercedes v5.1. See also 5V Lite and 5V Core.
2025-01-28 Version 5V, Lite, and Core.
    fixed spelling errors
    [Memory Map.xlsx]
2025-01-28 UPDATE: Version 5V, 5V Lite, and 5V Core.
    [Memory Map.xlsx]
2025-01-29 Add files via upload
    formatting
    [Memory Map.xlsx]
2025-01-29 Add files via upload
    adjusted banked regions
    [Memory Map.xlsx]
2025-02-22 created KiCad project for Carbon Z80
    [ATX_ISA16_8.kicad_pcb, ATX_ISA8_8.kicad_pcb, CarbonZ80.kicad_pcb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]
2025-02-22 Script to generate mobo pcbs
    generates standardized layouts and slots
2025-02-22 created 200x300 pcb layout
    [200x300_64pin_7.kicad_pcb]
2025-02-23 added 4 slot version
    [200x300_64pin_4.kicad_pcb]
2025-02-26 placed objects yo
    [200x300_64pin_4.kicad_pcb, CarbonZ80.kicad_pcb, CarbonZ80.kicad_sch]
2025-02-26 fixed rough layout
    [CarbonZ80.kicad_pcb, CarbonZ80.kicad_sch]
2025-02-26 updated memory map
    took into account the fact that execution starts at 0x0000.
    [Memory Map.xlsx]
2025-02-26 more updates
    [CarbonZ80.kicad_sch]
2025-03-06 more progress
    [CarbonZ80.kicad_pcb, CarbonZ80.kicad_sch]
2025-03-11 big updates
    [CarbonZ80.kicad_pcb, CarbonZ80.kicad_sch]
2025-03-11 fixes on sch, pdf old
    [CarbonZ80.kicad_pcb]
2025-07-16 started new rc2014 design
    [CarbonR80.kicad_pcb, CarbonR80.kicad_sch, CarbonZ80.kicad_sch]
2025-07-16 small chg
    [CarbonR80.kicad_sch]
